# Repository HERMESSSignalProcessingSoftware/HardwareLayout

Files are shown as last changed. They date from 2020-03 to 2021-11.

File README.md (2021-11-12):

# HardwareLayout

## To consider for iteration 3.1
- [X] Rename 5V-28V to 5V-noniso
- [X] STAMP labeling
- [X] Northmarking Top and Bottom
- [X] Far fewer power LEDs
- [X] PTH LEDs via ZE05
- [ ] Label LEDs on PCB
- [X] Strip LED resistor network
- [X] LED Renames: LED_FPGA_LOADED(#13), LED_HB_MEMSYNC(#16), LED_HB_MSS(#14), LED_RECORDING(#15)
- [X] Strip 0 and inf valued devices
- [X] Inverting RXSM Connector
- [X] LM4030 for SGR measurement
- [X] VCCINT auf 1.2V
- [X] Bank0 und Bank6 auf 1.2V und connections an Spannung anpassen
- [X] Optocoupling Pullups
- [X] Main Clk for SF2
- [X] Fix broken Flash package
- [X] Replace FT2232D with FT2232H
- [X] (discarded) FTDI 1MOhm beim Oszi?
- [X] (discarded) FTDI Pins 3 42 und Ende R9 an 5V statt 3V3
- [X] (discarded) FTDI SI/WU auf 3V3

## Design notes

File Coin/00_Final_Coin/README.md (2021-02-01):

## Finaler HERMESS Coin
### Wichtige Informationen:
Bilder (16 bit): HardwareLayout\Coin\GIMP_FINAL\Version 2.1\16Bit
Bilder (GIMP - Projekt):  HardwareLayout\Coin\GIMP_FINAL
GERBER - FILES: HardwareLayout\Coin\00_Final_Coin
CAM - JOB: HardwareLayout\Coin\00_Final_Coin

### Scaling:
0.04 Pixel / mm

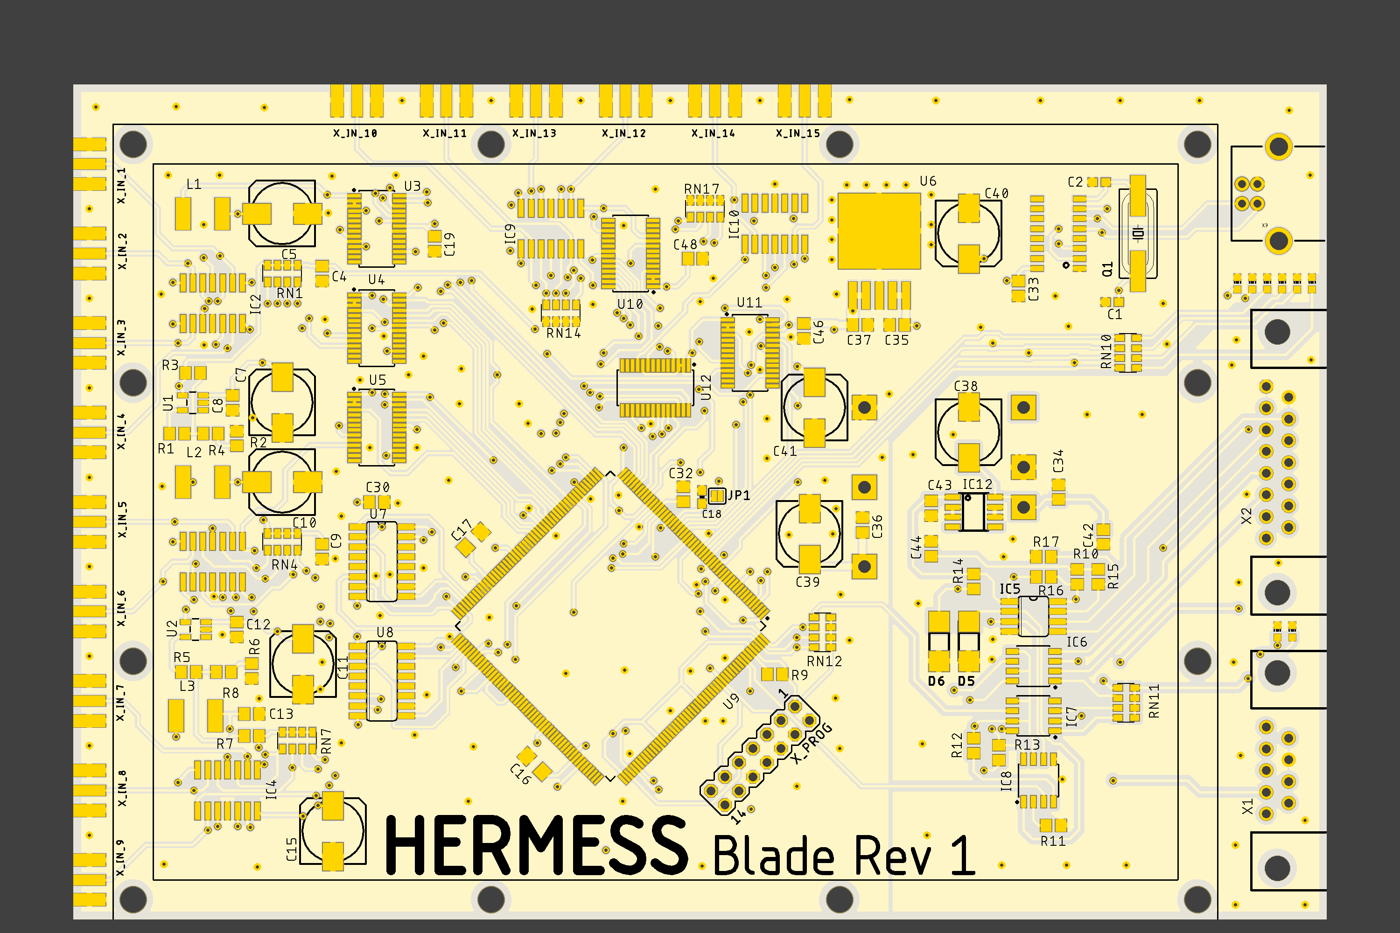
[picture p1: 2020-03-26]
docs/pinout/blade_rev1-sw.png

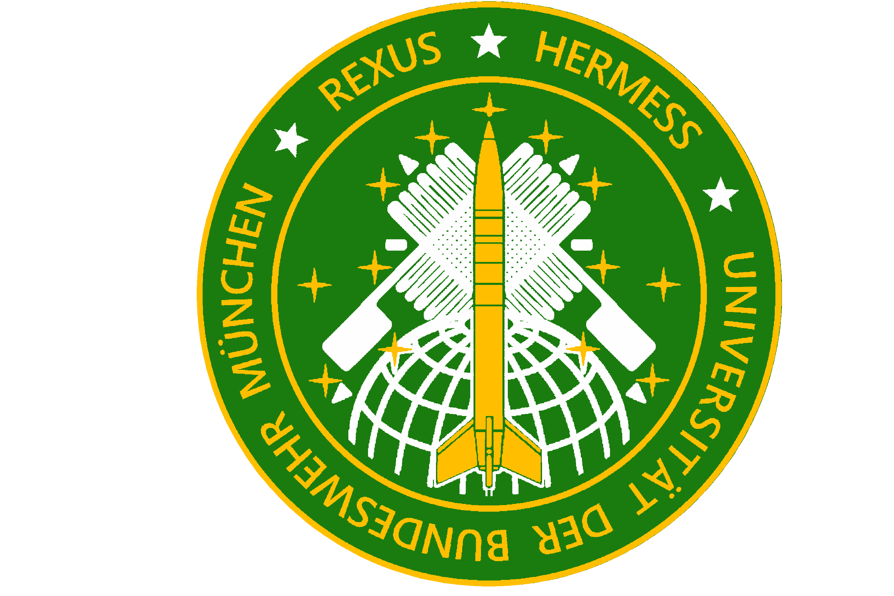
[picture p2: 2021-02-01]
Coin/00_Final_Coin/COIN_TOP_redesign_qr.png

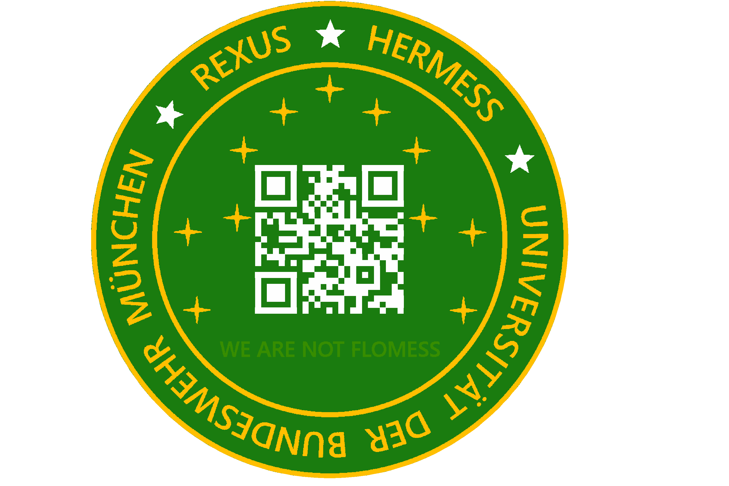
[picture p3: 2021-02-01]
Coin/00_Final_Coin/COIN_Bottom_redesign_qr.png

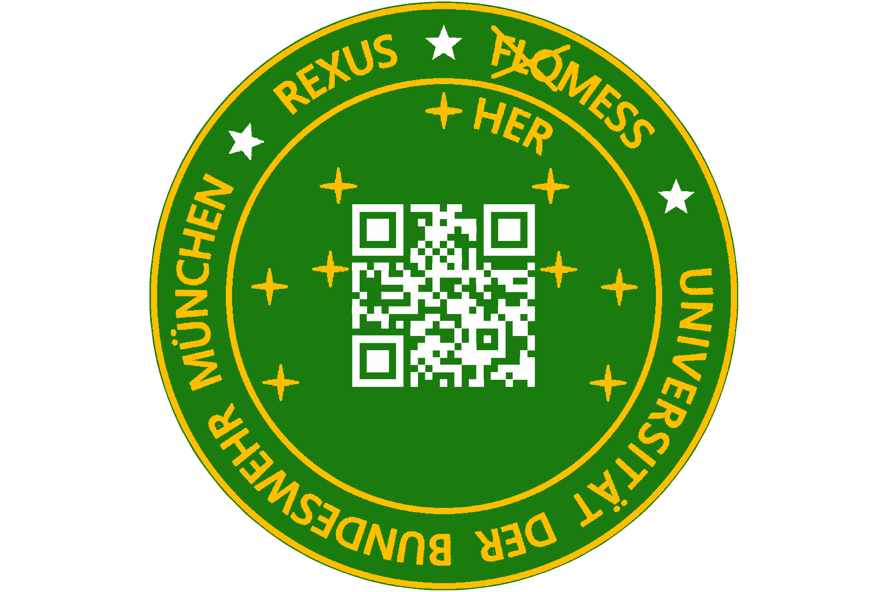
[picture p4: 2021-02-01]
Coin/01_Entwurf_fun_coin/HERMESS_COIN_FUN_BOTTOM.png

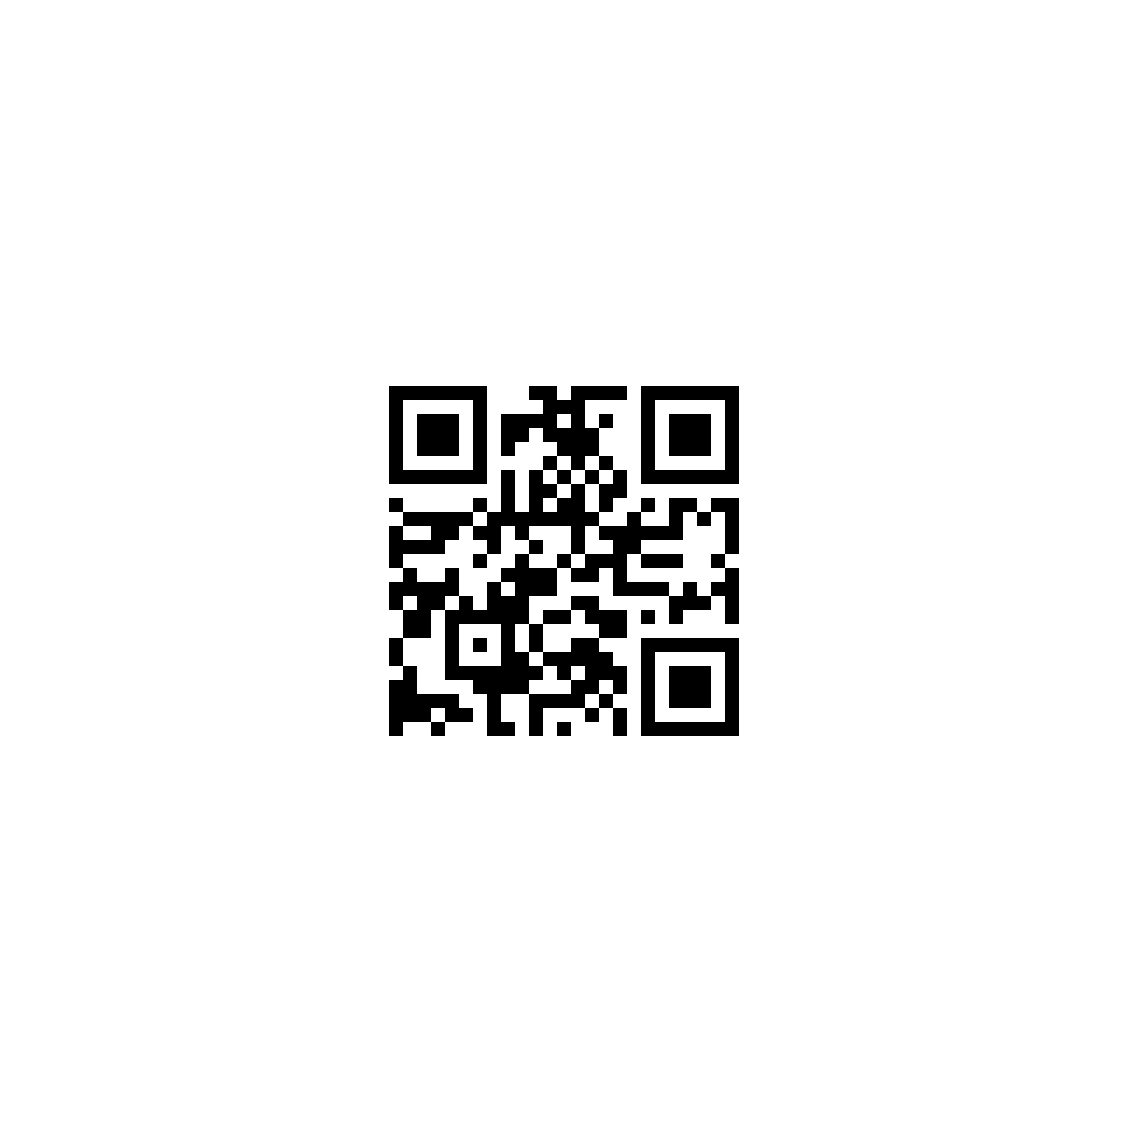
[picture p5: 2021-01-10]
Coin/GIMP_FINAL/HERMESS_BACKSIDE_LAYER_22.bmp

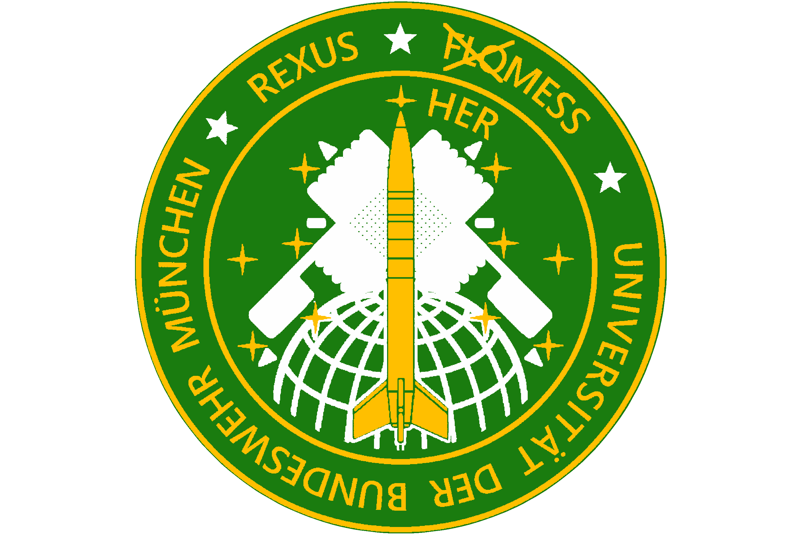
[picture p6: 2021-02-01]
Coin/01_Entwurf_fun_coin/HERMESS_COIN_FUN_TOP.png

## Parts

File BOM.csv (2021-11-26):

 | Neu bestellt | Qty | Value | Device | Package | Parts | Description | C-LOAD | CATEGORY | DATASHEET-URL | DESCRIPTION | HEAT-SINK | MANUFACTURER | MF | MOUNT | MPN | OC_FARNELL | OC_NEWARK | OPERATING_TEMP | OPERTAING_TEMP | PART-NUMBER | PART_STATUS | POPULARITY | ROHS_COMPLIANT | SERIES | SPICEPREFIX | SUB-CATEGORY | THERMALLOSS | TOLERANCE | TYPE | VALUE
x | 1 | 1 | DSC1001CI1-004.0960T | DSC1001CI1-004.0960T | CDFN3225 | U$5 |  |  |  |  |  |  |  |  |  |  |  |  |  |  |  |  |  |  |  | E
x | 1 | 1 | M93C46-WDW6TP | M93C46-WDW6TP | TSSOP-8 | FT_EEPROM | EEPORM M93C46 - WDW6TP
x | 1 | 1 | THN10-2411WIR | THL_20WI_SERIES | THL_20WI_SERIES | U_TRACODCDC | TRACO POWER DC/DC converter THL 20WI Series |  |  |  |  | NO
x | 2 | 1 |  | M15H | M15H | X1 | SUB-D |  |  |  |  |  |  |  |  |  | unknown | unknown |  |  |  |  | 0
x |  | 1 |  | PSS254_G2 | PSS254_G2 | WP
x |  | 1 |  | PSS254_G3 | PSS254_G3 | PROBES
x | 10 | 1 | 10n | C-EUC0805 | C0805 | C2 | CAPACITOR, European symbol |  |  |  |  |  |  |  |  |  |  |  |  |  |  |  | 88 |  |  | C
x | 2 | 1 | 12MHz | CRYSTALHC49UP | HC49UP | Q2 | CRYSTAL |  |  |  |  |  |  |  |  |  | unknown | unknown
x | 10 | 1 | 12k | R-EU_R0805 | R0805 | R9 | RESISTOR, European symbol |  |  |  |  |  |  |  |  |  |  |  |  |  |  |  | 86 |  |  | R
x | 10 | 1 | 150n | C-EUC0805 | C0805 | C27 | CAPACITOR, European symbol |  |  |  |  |  |  |  |  |  |  |  |  |  |  |  | 88 |  |  | C
x | 2 | 1 | 32.768kHz | WE-XTAL_IQXC-90_830107088501 | WE-XTAL_IQXC-90 | Y1 | WE-XTAL Watch Crystals | 6pF |  | https://www.we-online.com/catalog/datasheet/830107088501.pdf |  |  |  |  | SMT |  |  |  |  |  | 8,30E+11 |  |  |  |  |  |  |  | ±20ppm |  | 32.768kHz
x | 3 | 1 | FT2232HL | FT2232HL | LQFP64 | USB | FTDI FT2232HL
x | 2 | 1 | LM4030 | LM4030 | SOT-23 | REF4V096
x | 3 | 1 | TPS785 | TPS785 | TO-252-5 | TPS78512QKVURQ1
x | 3 | 1 | ZE05-4P-2V | ZE05-4P-2V | ZE05H-4P-2V | ZE05H-4P-2V
x | 3 | 6 | IL-AG5-10P-S3T2 | IL-AG5-10P-S3T2 | IL-AG5-10P-S3T2 | CON_STAMP1, CON_STAMP2, CON_STAMP3, CON_STAMP4, CON_STAMP5, CON_STAMP6
x | 4 | 2 |  | L-EUL1812 | L1812 | L1, L2 | INDUCTOR, European symbol |  |  |  |  |  |  |  |  |  |  |  |  |  |  |  | 18 |  |  | L
 | 5 | 18 | ADS1148QPWRQ1 | ADS1148QPWRQ1 | TSSOP28 | STAMP1_ADC_SG1, STAMP1_ADC_SG2, STAMP1_ADC_TEMP, STAMP2_ADC_SG1, STAMP2_ADC_SG2, STAMP2_ADC_TEMP, STAMP3_ADC_SG1, STAMP3_ADC_SG2, STAMP3_ADC_TEMP, STAMP4_ADC_SG1, STAMP4_ADC_SG2, STAMP4_ADC_TEMP, STAMP5_ADC_SG1, STAMP5_ADC_SG2, STAMP5_ADC_TEMP, STAMP6_ADC_SG1, STAMP6_ADC_SG2, STAMP6_ADC_TEMP
x | 6 | 3 | NXB0108PWJ | NXB0108PWJ | TSSOP-20 | U$1, U$2, U$3
x | 10 | 3 | 2 | R-EU_R0805 | R0805 | R2, R3, R4 | RESISTOR, European symbol |  |  |  |  |  |  |  |  |  |  |  |  |  |  |  | 86 |  |  | R
x | 10 | 2 | 22p | C-EUC0805 | C0805 | C74, C75 | CAPACITOR, European symbol |  |  |  |  |  |  |  |  |  |  |  |  |  |  |  | 88 |  |  | C
x | 5 | 1 | 3R65 | R-EU_R0805 | R0805 | R54 | RESISTOR, European symbol |  |  |  |  |  |  |  |  |  |  |  |  |  |  |  | 86 |  |  | R
x | 10 | 1 | 600 | R-EU_R0805 | R0805 | R42 | RESISTOR, European symbol |  |  |  |  |  |  |  |  |  |  |  |  |  |  |  | 86 |  |  | R
x | 20 | 5 | 680 | R-EU_R0805 | R0805 | R18, R19, R20, R49, R52 | RESISTOR, European symbol
x | 10 | 2 | 6pF | C-EUC0805 | C0805 | C30, C32 | CAPACITOR, European symbol |  |  |  |  |  |  |  |  |  |  |  |  |  |  |  | 88 |  |  | C
x | 20 | 5 | BSS123 | BSS123 | SOT23 | Q1, Q3, Q4, Q5, Q6 | N-CHANNEL MOS FET |  |  |  |  |  |  |  |  |  |  |  |  |  |  |  | 21
x | 20 | 1 | 1k | R-EU_R0805 | R0805 | R57 | RESISTOR, European symbol |  |  |  |  |  |  |  |  |  |  |  |  |  |  |  | 86 |  |  | R
x | 24 | 12 | COMMON_MODE_CHOKE | COMMON_MODE_CHOKE | COMMON_MODE_CHOKE | U$6, U$7, U$9, U$10, U$11, U$12, U$13, U$14, U$15, U$16, U$19, U$20 | WE-SL3 SMT COMMON MODE LINE FILT
x | 25 | 24 | 1k 0.1% | R-EU_R0805 | R0805 | R30, R33, R69, R74, R76, R86, R88, R92, R101, R105, R107, R111, R120, R124, R126, R130, R139, R143, R145, R149, R177, R181, R183, R187 | RESISTOR, European symbol |  |  |  |  |  |  |  |  |  |  |  |  |  |  |  | 86 |  |  | R
 |  | 4 |  | SJ | SJ | RCJ1, RCJ2, Y1J1, Y1J2 | SMD solder JUMPER |  |  |  |  |  |  |  |  |  |  |  |  |  |  |  | 33
 |  | 1 |  | USBMINIB | USB-MINIB | USB_CONN | USB Connectors
 |  | 103 | 100n | C-EUC0805 | C0805 | C1, C7, C8, C9, C10, C11, C12, C13, C14, C15, C16, C17, C18, C19, C20, C21, C22, C23, C25, C28, C29, C31, C33, C35, C36, C37, C43, C45, C46, C47, C48, C49, C51, C52, C53, C54, C55, C56, C71, C73, C76, C77, C78, C92, C94, C95, C96, C97, C98, C100, C101, C102, C103, C104, C105, C113, C115, C116, C117, C118, C119, C121, C122, C123, C124, C125, C126, C134, C136, C137, C138, C139, C140, C142, C143, C144, C145, C146, C147, C155, C157, C158, C159, C160, C161, C163, C164, C165, C166, C167, C168, C197, C199, C200, C201, C202, C203, C205, C206, C207, C208, C209, C210 | CAPACITOR, European symbol |  |  |  |  |  |  |  |  |  |  |  |  |  |  |  | 88 |  |  | C
 |  | 1 | 100n | C-EUC1206 | C1206 | C42 | CAPACITOR, European symbol |  |  |  |  |  |  |  |  |  |  |  |  |  |  |  | 54 |  |  | C
 |  | 3 | 10k | R-EU_R0805 | R0805 | R1, R26, R27 | RESISTOR, European symbol |  |  |  |  |  |  |  |  |  |  |  |  |  |  |  | 86 |  |  | R
 |  | 11 | 10u | CPOL-EUE/7260-38W | E/7260-38W | C38, C39, C40, C41, C60, C61, C62, C64, C65, C66, C67 | POLARIZED CAPACITOR, European symbol |  |  |  |  |  |  |  |  |  |  |  |  |  |  |  | 0 |  |  | C
 |  | 5 | 1V9 | LEDCHIP-LED0805 | CHIP-LED0805 | FL, MS, MSS, PWR, RC | LED
 |  | 6 | 1k | R-EU_R0805 | R0805 | R21, R22, R34, R43, R44, R53 | RESISTOR, European symbol
 |  | 18 | 1u | C-EUC0805 | C0805 | C34, C50, C63, C93, C99, C109, C114, C120, C130, C135, C141, C151, C156, C162, C172, C198, C204, C214 | CAPACITOR, European symbol |  |  |  |  |  |  |  |  |  |  |  |  |  |  |  | 88 |  |  | C
 |  | 1 | 2k2 | R-EU_R0805 | R0805 | R24 | RESISTOR, European symbol |  |  |  |  |  |  |  |  |  |  |  |  |  |  |  | 86 |  |  | R
 |  | 2 | 330 | R-EU_R0805 | R0805 | R47, R48 | RESISTOR, European symbol
 |  | 6 | 33n | C-EUC0805 | C0805 | C68, C110, C131, C152, C173, C215 | CAPACITOR, European symbol |  |  |  |  |  |  |  |  |  |  |  |  |  |  |  | 88 |  |  | C
 |  | 4 | 3k | R-EU_R0805 | R0805 | R11, R12, R13, R23 | RESISTOR, European symbol
 |  | 2 | 3k3 | R-EU_R0805 | R0805 | R16, R17 | RESISTOR, European symbol
 |  | 12 | 3n3 | C-EUC0805 | C0805 | C69, C70, C111, C112, C132, C133, C153, C154, C174, C175, C216, C217 | CAPACITOR, European symbol |  |  |  |  |  |  |  |  |  |  |  |  |  |  |  | 88 |  |  | C
 |  | 24 | 40 1% | R-EU_R0805 | R0805 | R29, R32, R72, R73, R84, R85, R90, R91, R103, R104, R109, R110, R122, R123, R128, R129, R141, R142, R147, R148, R179, R180, R185, R186 | RESISTOR, European symbol |  |  |  |  |  |  |  |  |  |  |  |  |  |  |  | 86 |  |  | R
 |  | 31 | 47 | R-EU_R0805 | R0805 | R14, R31, R35, R36, R40, R41, R45, R46, R50, R51, R55, R56, R60, R61, R70, R75, R83, R89, R93, R102, R108, R112, R121, R127, R131, R140, R146, R150, R178, R184, R188 | RESISTOR, European symbol |  |  |  |  |  |  |  |  |  |  |  |  |  |  |  | 86 |  |  | R
 |  | 2 | 470n | C-EUC0805 | C0805 | C4, C6 | CAPACITOR, European symbol |  |  |  |  |  |  |  |  |  |  |  |  |  |  |  | 88 |  |  | C
 |  | 18 | 4k7 | R-EU_R0805 | R0805 | R28, R68, R71, R77, R87, R94, R100, R106, R113, R119, R125, R132, R138, R144, R151, R176, R182, R189 | RESISTOR, European symbol |  |  |  |  |  |  |  |  |  |  |  |  |  |  |  | 86 |  |  | R
 |  | 12 | 4k7 1% | R-EU_R0805 | R0805 | R78, R79, R95, R96, R114, R115, R133, R134, R152, R153, R190, R191 | RESISTOR, European symbol |  |  |  |  |  |  |  |  |  |  |  |  |  |  |  | 86 |  |  | R
 |  | 5 | 4u7 | C-EUC0805 | C0805 | C3, C5, C24, C26, C79 | CAPACITOR, European symbol |  |  |  |  |  |  |  |  |  |  |  |  |  |  |  | 88 |  |  | C
 |  | 2 | 500 | R-EU_R0805 | R0805 | R10, R15 | RESISTOR, European symbol
 |  | 2 | 5V6 | DZMELF | DMELF | D1, D5 | Zener diode
 |  | 6 | 68n | C-EUC0805 | C0805 | C58, C107, C128, C149, C170, C212 | CAPACITOR, European symbol |  |  |  |  |  |  |  |  |  |  |  |  |  |  |  | 88 |  |  | C
 |  | 12 | 6n8 | C-EUC0805 | C0805 | C57, C59, C106, C108, C127, C129, C148, C150, C169, C171, C211, C213 | CAPACITOR, European symbol |  |  |  |  |  |  |  |  |  |  |  |  |  |  |  | 88 |  |  | C
 |  | 1 | 7k5 | R-EU_R0805 | R0805 | R25 | RESISTOR, European symbol |  |  |  |  |  |  |  |  |  |  |  |  |  |  |  | 86 |  |  | R
 |  | 6 | 820 0.1% | R-EU_R0805 | R0805 | R82, R99, R118, R137, R156, R194 | RESISTOR, European symbol |  |  |  |  |  |  |  |  |  |  |  |  |  |  |  | 86 |  |  | R
 |  | 12 | 9k09 1% | R-EU_R0805 | R0805 | R80, R81, R97, R98, R116, R117, R135, R136, R154, R155, R192, R193 | RESISTOR, European symbol |  |  |  |  |  |  |  |  |  |  |  |  |  |  |  | 86 |  |  | R
 |  | 1 | LM78L05ACMX/NOPB | LM78L05ACMX/NOPB | SOIC8 | U_7805
 |  | 1 | LT1528 | LT1528 | Q5-DD | U_LT1528 | LT1528
 |  | 1 | MAX488CSA | MAX488CSA | SO08 | U_MAX488 | RS485 TRANSEIVER |  |  |  |  |  |  | MAXIM |  | MAX488CSA | 3534170 | 34C3921 |  |  |  |  | 1
 |  | 3 | MOCD207M | MOCD207M_SOIC8 | SOIC127P594X363-8N | U_OPTO_3, U_OPTO_4, U_OPTO_5 | 8- pin SOIC Dual-Channel Phototransistor Output Optocoupler |  | Opto-Electronic |  |  |  | ON Semiconductor |  |  | MOCD207M |  |  |  | -40 to +100 °C |  | Active |  | RoHS3 Compliant |  |  | OptoCoupler | 0.24W |  |  | MOCD207M
 |  | 1 | S70FL01GSAGM | S70FL01GSAGM | SOIC16 | S70FL | Memory S70FL01G
 |  | 1 | SF2_M2S010TQ144 | SF2_M2S010TQ144 | TQFP144 | SF2_M2S010TQ1 | Smart Fusion SoC
 |  | 1 | ~0 | C-EUC0805 | C0805 | C44 | CAPACITOR, European symbol |  |  |  |  |  |  |  |  |  |  |  |  |  |  |  | 88 |  |  | C

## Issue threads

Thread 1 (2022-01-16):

MOSI signal of STAMP 6 spikes

robybyte, 2022-01-16:
While measuring RX TX signals of telemetry a strage signal appered on MOSI of STAMP 6 (pin number 2 at the SmartFusion IC).
Signal looked like a falling exponential function (as you discharge a capacitor) creating some spikes (Vpp was in the given limit of the SM2).

TODO: Measurments at pin 2 all the way to the corresponding STAMP.

Issue

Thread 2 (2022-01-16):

R54 overheating

robybyte, 2022-01-16:
While testing one resistor (R54) destroyed itself due to overheating.

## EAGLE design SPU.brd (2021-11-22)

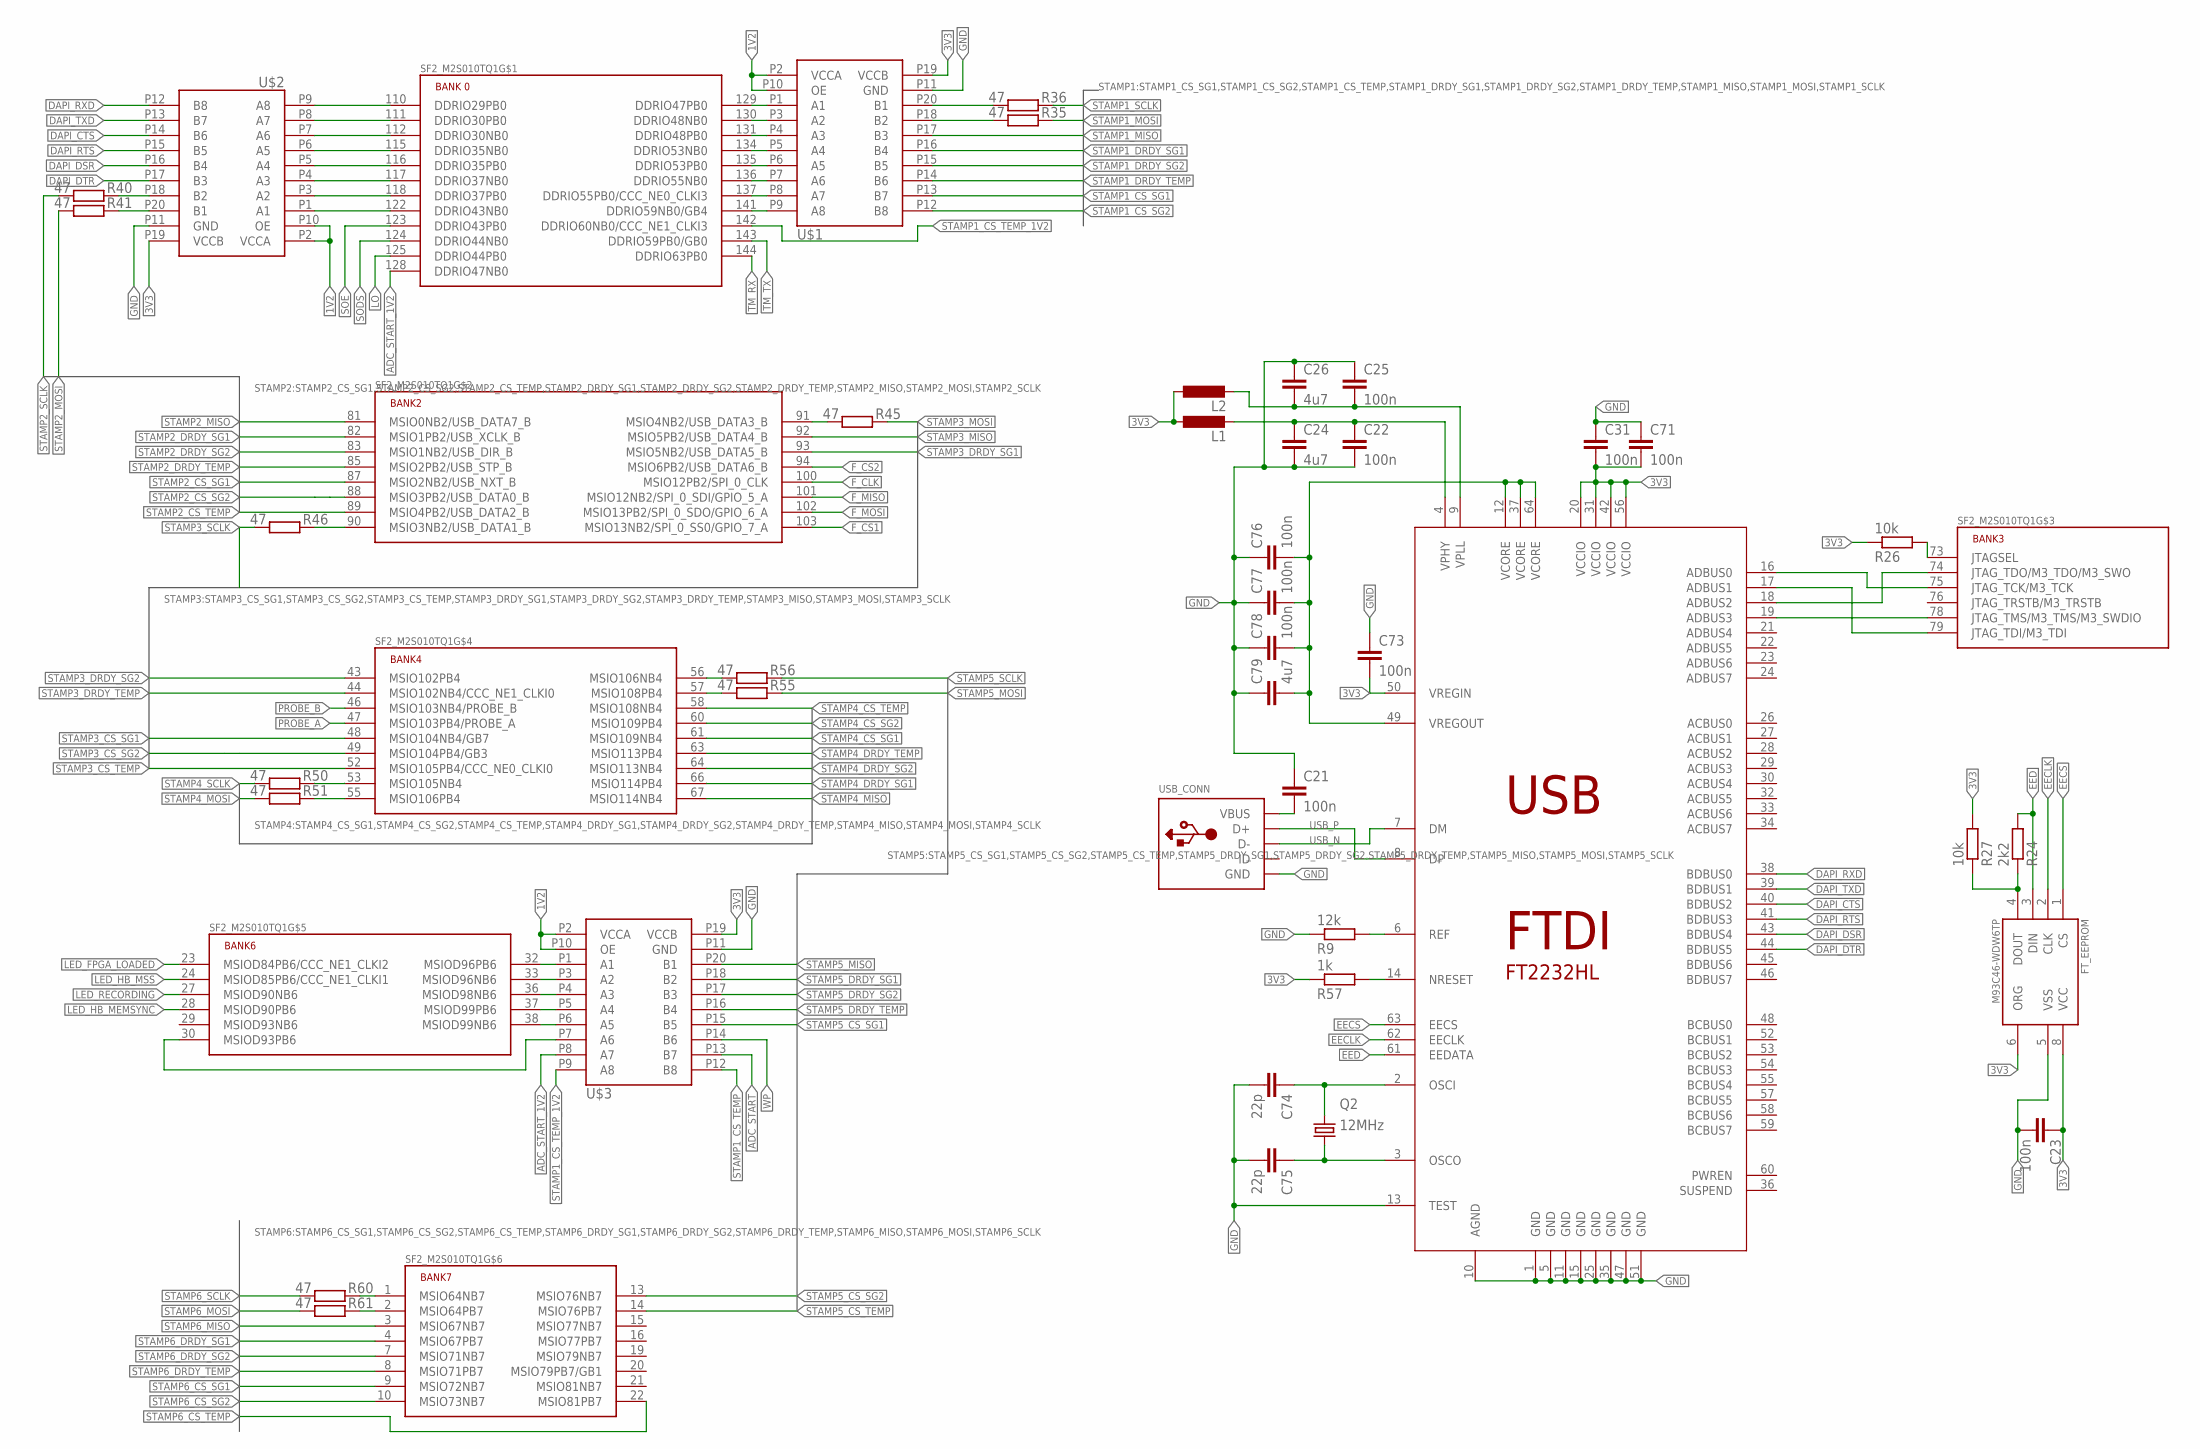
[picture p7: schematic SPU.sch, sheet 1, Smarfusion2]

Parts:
C21, C22, C23, C25, C31, C71, C73, C76, C77, C78: 100n; C0805
C24, C26, C79: 4u7; C0805
C74, C75: 22p; C0805
FT_EEPROM: M93C46-WDW6TP; TSSOP-8
L1, L2: L-EUL1812; L1812
Q2: 12MHz; HC49UP
R9: 12k; R0805
R24: 2k2; R0805
R26, R27: 10k; R0805
R35, R36, R40, R41, R45, R46, R50, R51, R55, R56, R60, R61: 47; R0805
R57: 1k; R0805
SF2_M2S010TQ1: SF2_M2S010TQ144; TQFP144
U$1, U$2, U$3: NXB0108PWJ; TSSOP-20
USB: FT2232HL; LQFP64
USB_CONN: USBMINIB; USB-MINIB

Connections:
1V2: U$1.P2 (VCCA), U$1.P10 (OE), U$2.P2 (VCCA), U$2.P10 (OE), U$3.P2 (VCCA), U$3.P10 (OE); also elsewhere on the board
3V3: C23.1, C31.2, C71.2, C73.2, FT_EEPROM.6 (ORG), FT_EEPROM.8 (VCC), L1.1, L2.1, R26.1, R27.2, R57.1, U$1.P19 (VCCB), U$2.P19 (VCCB), U$3.P19 (VCCB), USB.20 (VCCIO), USB.31 (VCCIO), USB.42 (VCCIO), USB.50 (VREGIN), USB.56 (VCCIO); also elsewhere on the board
ADC_START: U$3.P13 (B7); also elsewhere on the board
ADC_START_1V2: SF2_M2S010TQ1.128 (DDRIO47NB0), U$3.P8 (A7)
DAPI_CTS: U$2.P14 (B6), USB.40 (BDBUS2)
DAPI_DSR: U$2.P16 (B4), USB.43 (BDBUS4)
DAPI_DTR: U$2.P17 (B3), USB.44 (BDBUS5)
DAPI_RTS: U$2.P15 (B5), USB.41 (BDBUS3)
DAPI_RXD: U$2.P12 (B8), USB.38 (BDBUS0)
DAPI_TXD: U$2.P13 (B7), USB.39 (BDBUS1)
EECLK: FT_EEPROM.2 (CLK), USB.62 (EECLK)
EECS: FT_EEPROM.1 (CS), USB.63 (EECS)
EED: FT_EEPROM.3 (DIN), R24.2, USB.61 (EEDATA)
F_CLK: SF2_M2S010TQ1.100 (MSIO12PB2/SPI_0_CLK); also elsewhere on the board
F_CS1: SF2_M2S010TQ1.103 (MSIO13NB2/SPI_0_SS0/GPIO_7_A); also elsewhere on the board
F_CS2: SF2_M2S010TQ1.94 (MSIO6PB2/USB_DATA6_B); also elsewhere on the board
F_MISO: SF2_M2S010TQ1.101 (MSIO12NB2/SPI_0_SDI/GPIO_5_A); also elsewhere on the board
F_MOSI: SF2_M2S010TQ1.102 (MSIO13PB2/SPI_0_SDO/GPIO_6_A); also elsewhere on the board
GND: C21.1, C22.2, C23.2, C24.2, C25.1, C26.1, C31.1, C71.1, C73.1, C74.2, C75.2, C76.1, C77.1, C78.1, C79.1, FT_EEPROM.5 (VSS), R9.1, U$1.P11 (GND), U$2.P11 (GND), U$3.P11 (GND), USB.1 (GND), USB.5 (GND), USB.10 (AGND), USB.11 (GND), USB.13 (TEST), USB.15 (GND), USB.25 (GND), USB.35 (GND), USB.47 (GND), USB.51 (GND), USB_CONN.GND; also elsewhere on the board
LED_FPGA_LOADED: SF2_M2S010TQ1.23 (MSIOD84PB6/CCC_NE1_CLKI2); also elsewhere on the board
LED_HB_MEMSYNC: SF2_M2S010TQ1.28 (MSIOD90PB6); also elsewhere on the board
LED_HB_MSS: SF2_M2S010TQ1.24 (MSIOD85PB6/CCC_NE1_CLKI1); also elsewhere on the board
LED_RECORDING: SF2_M2S010TQ1.27 (MSIOD90NB6); also elsewhere on the board
LO: SF2_M2S010TQ1.125 (DDRIO44PB0); also elsewhere on the board
unnamed: R26.2, SF2_M2S010TQ1.73 (JTAGSEL)
unnamed: C74.1, Q2.2, USB.2 (OSCI)
unnamed: SF2_M2S010TQ1.32 (MSIOD96PB6), U$3.P1 (A1)
unnamed: SF2_M2S010TQ1.33 (MSIOD96NB6), U$3.P3 (A2)
unnamed: SF2_M2S010TQ1.36 (MSIOD98NB6), U$3.P4 (A3)
unnamed: C21.2, USB_CONN.VBUS
unnamed: C22.1, C24.1, L1.2, USB.4 (VPHY)
unnamed: R36.2, U$1.P20 (B1)
unnamed: SF2_M2S010TQ1.75 (JTAG_TCK/M3_TCK), USB.16 (ADBUS0)
unnamed: SF2_M2S010TQ1.79 (JTAG_TDI/M3_TDI), USB.17 (ADBUS1)
unnamed: SF2_M2S010TQ1.74 (JTAG_TDO/M3_TDO/M3_SWO), USB.18 (ADBUS2)
unnamed: SF2_M2S010TQ1.78 (JTAG_TMS/M3_TMS/M3_SWDIO), USB.19 (ADBUS3)
unnamed: SF2_M2S010TQ1.37 (MSIOD99PB6), U$3.P5 (A4)
unnamed: FT_EEPROM.4 (DOUT), R24.1, R27.1
unnamed: R35.2, U$1.P18 (B2)
unnamed: SF2_M2S010TQ1.118 (DDRIO37PB0), U$2.P3 (A2)
unnamed: SF2_M2S010TQ1.122 (DDRIO43NB0), U$2.P1 (A1)
unnamed: R40.1, U$2.P18 (B2)
unnamed: SF2_M2S010TQ1.129 (DDRIO47PB0), U$1.P1 (A1)
unnamed: R41.1, U$2.P20 (B1)
unnamed: R46.1, SF2_M2S010TQ1.90 (MSIO3NB2/USB_DATA1_B)
unnamed: R45.2, SF2_M2S010TQ1.91 (MSIO4NB2/USB_DATA3_B)
unnamed: SF2_M2S010TQ1.130 (DDRIO48NB0), U$1.P3 (A2)
unnamed: SF2_M2S010TQ1.131 (DDRIO48PB0), U$1.P4 (A3)
unnamed: SF2_M2S010TQ1.134 (DDRIO53NB0), U$1.P5 (A4)
unnamed: SF2_M2S010TQ1.135 (DDRIO53PB0), U$1.P6 (A5)
unnamed: SF2_M2S010TQ1.136 (DDRIO55NB0), U$1.P7 (A6)
unnamed: SF2_M2S010TQ1.137 (DDRIO55PB0/CCC_NE0_CLKI3), U$1.P8 (A7)
unnamed: SF2_M2S010TQ1.141 (DDRIO59NB0/GB4), U$1.P9 (A8)
unnamed: SF2_M2S010TQ1.38 (MSIOD99NB6), U$3.P6 (A5)
unnamed: SF2_M2S010TQ1.110 (DDRIO29PB0), U$2.P9 (A8)
unnamed: SF2_M2S010TQ1.111 (DDRIO30PB0), U$2.P8 (A7)
unnamed: SF2_M2S010TQ1.112 (DDRIO30NB0), U$2.P7 (A6)
unnamed: SF2_M2S010TQ1.115 (DDRIO35NB0), U$2.P6 (A5)
unnamed: R50.1, SF2_M2S010TQ1.53 (MSIO105NB4)
unnamed: R51.1, SF2_M2S010TQ1.55 (MSIO106PB4)
unnamed: SF2_M2S010TQ1.116 (DDRIO35PB0), U$2.P5 (A4)
unnamed: SF2_M2S010TQ1.117 (DDRIO37NB0), U$2.P4 (A3)
unnamed: SF2_M2S010TQ1.30 (MSIOD93PB6), U$3.P7 (A6)
unnamed: R55.2, SF2_M2S010TQ1.57 (MSIO108PB4)
unnamed: R56.2, SF2_M2S010TQ1.56 (MSIO106NB4)
unnamed: R60.1, SF2_M2S010TQ1.1 (MSIO64NB7)
unnamed: R61.1, SF2_M2S010TQ1.2 (MSIO64PB7)
unnamed: R57.2, USB.14 (NRESET)
unnamed: R9.2, USB.6 (REF)
unnamed: C75.1, Q2.1, USB.3 (OSCO)
unnamed: C76.2, C77.2, C78.2, C79.2, USB.12 (VCORE), USB.37 (VCORE), USB.49 (VREGOUT), USB.64 (VCORE)
unnamed: C25.2, C26.2, L2.2, USB.9 (VPLL)
PROBE_A: SF2_M2S010TQ1.47 (MSIO103PB4/PROBE_A); also elsewhere on the board
PROBE_B: SF2_M2S010TQ1.46 (MSIO103NB4/PROBE_B); also elsewhere on the board
SODS: SF2_M2S010TQ1.124 (DDRIO44NB0); also elsewhere on the board
SOE: SF2_M2S010TQ1.123 (DDRIO43PB0); also elsewhere on the board
STAMP1_CS_SG1: U$1.P13 (B7); also elsewhere on the board
STAMP1_CS_SG2: U$1.P12 (B8); also elsewhere on the board
STAMP1_CS_TEMP: U$3.P12 (B8); also elsewhere on the board
STAMP1_CS_TEMP_1V2: SF2_M2S010TQ1.142 (DDRIO60NB0/CCC_NE1_CLKI3), U$3.P9 (A8)
STAMP1_DRDY_SG1: U$1.P16 (B4); also elsewhere on the board
STAMP1_DRDY_SG2: U$1.P15 (B5); also elsewhere on the board
STAMP1_DRDY_TEMP: U$1.P14 (B6); also elsewhere on the board
STAMP1_MISO: U$1.P17 (B3); also elsewhere on the board
STAMP1_MOSI: R35.1; also elsewhere on the board
STAMP1_SCLK: R36.1; also elsewhere on the board
STAMP2_CS_SG1: SF2_M2S010TQ1.87 (MSIO2NB2/USB_NXT_B); also elsewhere on the board
STAMP2_CS_SG2: SF2_M2S010TQ1.88 (MSIO3PB2/USB_DATA0_B); also elsewhere on the board
STAMP2_CS_TEMP: SF2_M2S010TQ1.89 (MSIO4PB2/USB_DATA2_B); also elsewhere on the board
STAMP2_DRDY_SG1: SF2_M2S010TQ1.82 (MSIO1PB2/USB_XCLK_B); also elsewhere on the board
STAMP2_DRDY_SG2: SF2_M2S010TQ1.83 (MSIO1NB2/USB_DIR_B); also elsewhere on the board
STAMP2_DRDY_TEMP: SF2_M2S010TQ1.85 (MSIO2PB2/USB_STP_B); also elsewhere on the board
STAMP2_MISO: SF2_M2S010TQ1.81 (MSIO0NB2/USB_DATA7_B); also elsewhere on the board
STAMP2_MOSI: R41.2; also elsewhere on the board
STAMP2_SCLK: R40.2; also elsewhere on the board
STAMP3_CS_SG1: SF2_M2S010TQ1.48 (MSIO104NB4/GB7); also elsewhere on the board
STAMP3_CS_SG2: SF2_M2S010TQ1.49 (MSIO104PB4/GB3); also elsewhere on the board
STAMP3_CS_TEMP: SF2_M2S010TQ1.52 (MSIO105PB4/CCC_NE0_CLKI0); also elsewhere on the board
STAMP3_DRDY_SG1: SF2_M2S010TQ1.93 (MSIO5NB2/USB_DATA5_B); also elsewhere on the board
STAMP3_DRDY_SG2: SF2_M2S010TQ1.43 (MSIO102PB4); also elsewhere on the board
STAMP3_DRDY_TEMP: SF2_M2S010TQ1.44 (MSIO102NB4/CCC_NE1_CLKI0); also elsewhere on the board
STAMP3_MISO: SF2_M2S010TQ1.92 (MSIO5PB2/USB_DATA4_B); also elsewhere on the board
STAMP3_MOSI: R45.1; also elsewhere on the board
STAMP3_SCLK: R46.2; also elsewhere on the board
STAMP4_CS_SG1: SF2_M2S010TQ1.61 (MSIO109NB4); also elsewhere on the board
STAMP4_CS_SG2: SF2_M2S010TQ1.60 (MSIO109PB4); also elsewhere on the board
STAMP4_CS_TEMP: SF2_M2S010TQ1.58 (MSIO108NB4); also elsewhere on the board
STAMP4_DRDY_SG1: SF2_M2S010TQ1.66 (MSIO114PB4); also elsewhere on the board
STAMP4_DRDY_SG2: SF2_M2S010TQ1.64 (MSIO113NB4); also elsewhere on the board
STAMP4_DRDY_TEMP: SF2_M2S010TQ1.63 (MSIO113PB4); also elsewhere on the board
STAMP4_MISO: SF2_M2S010TQ1.67 (MSIO114NB4); also elsewhere on the board
STAMP4_MOSI: R51.2; also elsewhere on the board
STAMP4_SCLK: R50.2; also elsewhere on the board
STAMP5_CS_SG1: U$3.P15 (B5); also elsewhere on the board
STAMP5_CS_SG2: SF2_M2S010TQ1.13 (MSIO76NB7); also elsewhere on the board
STAMP5_CS_TEMP: SF2_M2S010TQ1.14 (MSIO76PB7); also elsewhere on the board
STAMP5_DRDY_SG1: U$3.P18 (B2); also elsewhere on the board
STAMP5_DRDY_SG2: U$3.P17 (B3); also elsewhere on the board
STAMP5_DRDY_TEMP: U$3.P16 (B4); also elsewhere on the board
STAMP5_MISO: U$3.P20 (B1); also elsewhere on the board
STAMP5_MOSI: R55.1; also elsewhere on the board
STAMP5_SCLK: R56.1; also elsewhere on the board
STAMP6_CS_SG1: SF2_M2S010TQ1.9 (MSIO72NB7); also elsewhere on the board
STAMP6_CS_SG2: SF2_M2S010TQ1.10 (MSIO73NB7); also elsewhere on the board
STAMP6_CS_TEMP: SF2_M2S010TQ1.22 (MSIO81PB7); also elsewhere on the board
STAMP6_DRDY_SG1: SF2_M2S010TQ1.4 (MSIO67PB7); also elsewhere on the board
STAMP6_DRDY_SG2: SF2_M2S010TQ1.7 (MSIO71NB7); also elsewhere on the board
STAMP6_DRDY_TEMP: SF2_M2S010TQ1.8 (MSIO71PB7); also elsewhere on the board
STAMP6_MISO: SF2_M2S010TQ1.3 (MSIO67NB7); also elsewhere on the board
STAMP6_MOSI: R61.2; also elsewhere on the board
STAMP6_SCLK: R60.2; also elsewhere on the board
TM_RX: SF2_M2S010TQ1.144 (DDRIO63PB0); also elsewhere on the board
TM_TX: SF2_M2S010TQ1.143 (DDRIO59PB0/GB0); also elsewhere on the board
USB_N: USB.7 (DM), USB_CONN.D-
USB_P: USB.8 (DP), USB_CONN.D+
WP: U$3.P14 (B6); also elsewhere on the board

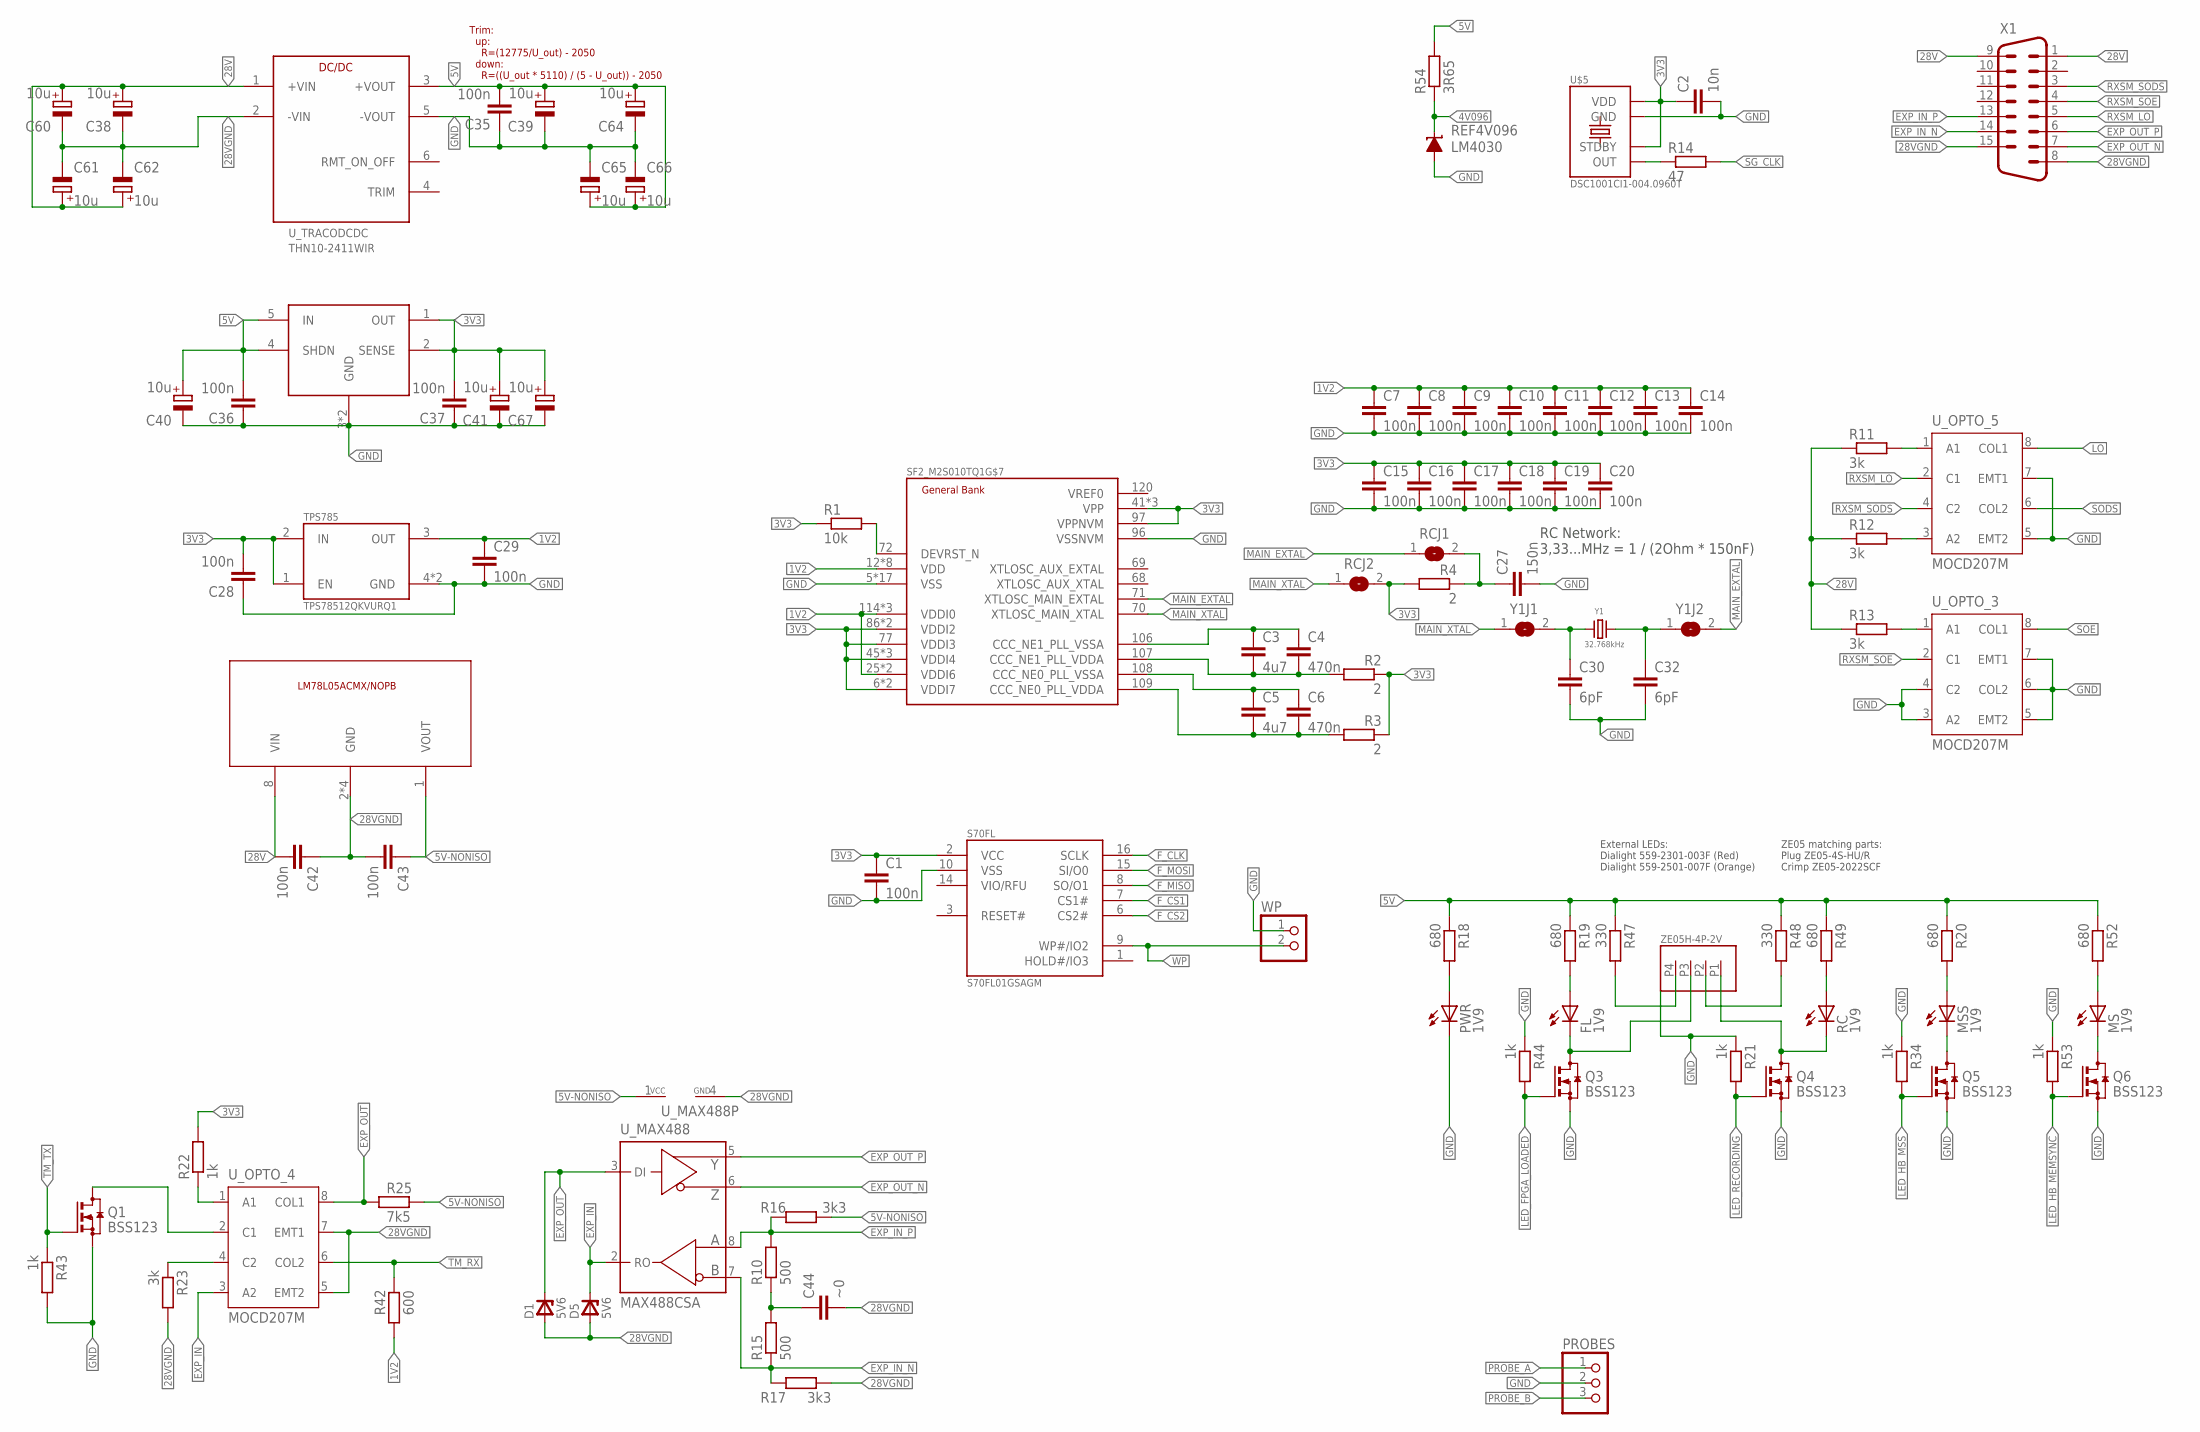
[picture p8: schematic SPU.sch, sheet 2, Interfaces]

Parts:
C1, C7, C8, C9, C10, C11, C12, C13, C14, C15, C16, C17, C18, C19, C20, C28, C29, C35, C36, C37, C43: 100n; C0805
C2: 10n; C0805
C3, C5: 4u7; C0805
C4, C6: 470n; C0805
C27: 150n; C0805
C30, C32: 6pF; C0805
C38, C39, C40, C41, C60, C61, C62, C64, C65, C66, C67: 10u; E/7260-38W
C42: 100n; C1206
C44: ~0; C0805
D1, D5: 5V6; DMELF
FL: 1V9; CHIP-LED0805
MS: 1V9; CHIP-LED0805
MSS: 1V9; CHIP-LED0805
PROBES: PSS254_G3
PWR: 1V9; CHIP-LED0805
Q1, Q3, Q4, Q5, Q6: BSS123; SOT23
R1: 10k; R0805
R2, R3, R4: 2; R0805
R10, R15: 500; R0805
R11, R12, R13, R23: 3k; R0805
R14: 47; R0805
R16, R17: 3k3; R0805
R18, R19, R20, R49, R52: 680; R0805
R21, R22, R34, R43, R44, R53: 1k; R0805
R25: 7k5; R0805
R42: 600; R0805
R47, R48: 330; R0805
R54: 3R65; R0805
RC: 1V9; CHIP-LED0805
RCJ1, RCJ2: SJ
REF4V096: LM4030; SOT-23
S70FL: S70FL01GSAGM; SOIC16
SF2_M2S010TQ1: SF2_M2S010TQ144; TQFP144
TPS78512QKVURQ1: TPS785; TO-252-5
U$5: DSC1001CI1-004.0960T; CDFN3225
U_7805: LM78L05ACMX/NOPB; SOIC8
U_LT1528: LT1528; Q5-DD
U_MAX488: MAX488CSA; SO08
U_OPTO_3, U_OPTO_4, U_OPTO_5: MOCD207M; SOIC127P594X363-8N
U_TRACODCDC: THN10-2411WIR; THL_20WI_SERIES
WP: PSS254_G2
X1: M15H
Y1: 32.768kHz; WE-XTAL_IQXC-90
Y1J1, Y1J2: SJ
ZE05H-4P-2V: ZE05-4P-2V; ZE05H-4P-2V

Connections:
1V2: C7.1, C8.1, C9.1, C10.1, C11.1, C12.1, C13.1, C14.1, C29.1, R42.1, SF2_M2S010TQ1.12 (VDD), SF2_M2S010TQ1.25 (VDDI6), SF2_M2S010TQ1.31 (VDD), SF2_M2S010TQ1.35 (VDDI6), SF2_M2S010TQ1.39 (VDD), SF2_M2S010TQ1.50 (VDD), SF2_M2S010TQ1.95 (VDD), SF2_M2S010TQ1.105 (VDD), SF2_M2S010TQ1.114 (VDDI0), SF2_M2S010TQ1.121 (VDD), SF2_M2S010TQ1.127 (VDDI0), SF2_M2S010TQ1.133 (VDD), SF2_M2S010TQ1.138 (VDDI0), TPS78512QKVURQ1.3 (OUT); also elsewhere on the board
3V3: C1.1, C2.1, C15.1, C16.1, C17.1, C18.1, C19.1, C20.1, C28.2, C37.2, C41.+, C67.+, R1.1, R2.1, R3.1, R4.2, R22.2, RCJ2.2, S70FL.2 (VCC), SF2_M2S010TQ1.6 (VDDI7), SF2_M2S010TQ1.17 (VDDI7), SF2_M2S010TQ1.41 (VPP), SF2_M2S010TQ1.45 (VDDI4), SF2_M2S010TQ1.54 (VDDI4), SF2_M2S010TQ1.62 (VDDI4), SF2_M2S010TQ1.77 (VDDI3), SF2_M2S010TQ1.80 (VPP), SF2_M2S010TQ1.86 (VDDI2), SF2_M2S010TQ1.97 (VPPNVM), SF2_M2S010TQ1.99 (VDDI2), SF2_M2S010TQ1.104 (VPP), TPS78512QKVURQ1.1 (EN), TPS78512QKVURQ1.2 (IN), U$5.P1 (STDBY), U$5.P4 (VDD), U_LT1528.1 (OUT), U_LT1528.2 (SENSE); also elsewhere on the board
4V096: R54.1, REF4V096.P4 (C); also elsewhere on the board
5V: C35.2, C36.2, C39.+, C40.+, C64.+, C65.+, C66.+, R18.1, R19.1, R20.1, R47.1, R48.1, R49.1, R52.1, R54.2, U_LT1528.4 (SHDN), U_LT1528.5 (IN), U_TRACODCDC.3 (+VOUT)
5V-NONISO: C43.1, R16.1, R25.2, U_7805.1 (VOUT), U_MAX488.1 (VCC)
28V: C38.+, C42.2, C60.+, C61.+, C62.+, R11.1, R12.1, R13.1, U_7805.8 (VIN), U_TRACODCDC.1 (+VIN), X1.1, X1.9
28VGND: C38.-, C42.1, C43.2, C44.2, C60.-, C61.-, C62.-, D1.A, D5.A, R17.1, R23.2, U_7805.2 (GND), U_7805.3 (GND), U_7805.6 (GND), U_7805.7 (GND), U_MAX488.4 (GND), U_OPTO_4.5 (EMT2), U_OPTO_4.7 (EMT1), U_TRACODCDC.2 (-VIN), X1.8, X1.15
EXP_IN: D5.C, U_MAX488.2 (RO), U_OPTO_4.3 (A2)
EXP_IN_N: R15.1, R17.2, U_MAX488.7 (B), X1.14
EXP_IN_P: R10.2, R16.2, U_MAX488.8 (A), X1.13
EXP_OUT: D1.C, R25.1, U_MAX488.3 (DI), U_OPTO_4.8 (COL1)
EXP_OUT_N: U_MAX488.6 (Z), X1.7
EXP_OUT_P: U_MAX488.5 (Y), X1.6
F_CLK: S70FL.16 (SCLK); also elsewhere on the board
F_CS1: S70FL.7 (CS1#); also elsewhere on the board
F_CS2: S70FL.6 (CS2#); also elsewhere on the board
F_MISO: S70FL.8 (SO/O1); also elsewhere on the board
F_MOSI: S70FL.15 (SI/O0); also elsewhere on the board
GND: C1.2, C2.2, C7.2, C8.2, C9.2, C10.2, C11.2, C12.2, C13.2, C14.2, C15.2, C16.2, C17.2, C18.2, C19.2, C20.2, C27.2, C28.1, C29.2, C30.2, C32.2, C35.1, C36.1, C37.1, C39.-, C40.-, C41.-, C64.-, C65.-, C66.-, C67.-, PROBES.2, PWR.C, Q1.2 (S), Q3.2 (S), Q4.2 (S), Q5.2 (S), Q6.2 (S), R21.1, R34.1, R43.2, R44.1, R53.1, REF4V096.P5 (A), S70FL.10 (VSS), SF2_M2S010TQ1.5 (VSS), SF2_M2S010TQ1.11 (VSS), SF2_M2S010TQ1.18 (VSS), SF2_M2S010TQ1.26 (VSS), SF2_M2S010TQ1.34 (VSS), SF2_M2S010TQ1.40 (VSS), SF2_M2S010TQ1.42 (VSS), SF2_M2S010TQ1.51 (VSS), SF2_M2S010TQ1.59 (VSS), SF2_M2S010TQ1.65 (VSS), SF2_M2S010TQ1.84 (VSS), SF2_M2S010TQ1.96 (VSSNVM), SF2_M2S010TQ1.98 (VSS), SF2_M2S010TQ1.113 (VSS), SF2_M2S010TQ1.119 (VSS), SF2_M2S010TQ1.126 (VSS), SF2_M2S010TQ1.132 (VSS), SF2_M2S010TQ1.139 (VSS), TPS78512QKVURQ1.4 (GND), TPS78512QKVURQ1.5 (GND), U$5.P2 (GND), U_LT1528.3 (GND), U_LT1528.6 (GND), U_OPTO_3.3 (A2), U_OPTO_3.4 (C2), U_OPTO_3.5 (EMT2), U_OPTO_3.6 (COL2), U_OPTO_3.7 (EMT1), U_OPTO_5.5 (EMT2), U_OPTO_5.7 (EMT1), U_TRACODCDC.5 (-VOUT), WP.1, ZE05H-4P-2V.P5, ZE05H-4P-2V.P6; also elsewhere on the board
LED_FPGA_LOADED: Q3.1 (G), R44.2; also elsewhere on the board
LED_HB_MEMSYNC: Q6.1 (G), R53.2; also elsewhere on the board
LED_HB_MSS: Q5.1 (G), R34.2; also elsewhere on the board
LED_RECORDING: Q4.1 (G), R21.2; also elsewhere on the board
LO: U_OPTO_5.8 (COL1); also elsewhere on the board
MAIN_EXTAL: RCJ1.1, SF2_M2S010TQ1.71 (XTLOSC_MAIN_EXTAL), Y1J2.2
MAIN_XTAL: RCJ2.1, SF2_M2S010TQ1.70 (XTLOSC_MAIN_XTAL), Y1J1.1
unnamed: C44.1, R10.1, R15.2
unnamed: R1.2, SF2_M2S010TQ1.72 (DEVRST_N)
unnamed: R23.1, U_OPTO_4.4 (C2)
unnamed: C3.1, C4.1, SF2_M2S010TQ1.106 (CCC_NE1_PLL_VSSA)
unnamed: C3.2, C4.2, R2.2, SF2_M2S010TQ1.107 (CCC_NE1_PLL_VDDA)
unnamed: C5.2, C6.2, R3.2, SF2_M2S010TQ1.109 (CCC_NE0_PLL_VDDA)
unnamed: C5.1, C6.1, SF2_M2S010TQ1.108 (CCC_NE0_PLL_VSSA)
unnamed: C30.1, Y1.1, Y1J1.2
unnamed: R13.2, U_OPTO_3.1 (A1)
unnamed: R12.2, U_OPTO_5.3 (A2)
unnamed: R11.2, U_OPTO_5.1 (A1)
unnamed: R22.1, U_OPTO_4.1 (A1)
unnamed: R14.1, U$5.P3 (OUT)
unnamed: PWR.A, R18.2
unnamed: MS.C, Q6.3 (D)
unnamed: MSS.C, Q5.3 (D)
unnamed: Q1.3 (D), U_OPTO_4.2 (C1)
unnamed: FL.A, R19.2
unnamed: MSS.A, R20.2
unnamed: C32.1, Y1.2, Y1J2.1
unnamed: MS.A, R52.2
unnamed: R49.2, RC.A
unnamed: R47.2, ZE05H-4P-2V.P4
unnamed: Q4.3 (D), RC.C, ZE05H-4P-2V.P1
unnamed: R48.2, ZE05H-4P-2V.P2
unnamed: FL.C, Q3.3 (D), ZE05H-4P-2V.P3
NET_U: C27.1, R4.1, RCJ1.2
PROBE_A: PROBES.1; also elsewhere on the board
PROBE_B: PROBES.3; also elsewhere on the board
RXSM_LO: U_OPTO_5.2 (C1), X1.5
RXSM_SODS: U_OPTO_5.4 (C2), X1.3
RXSM_SOE: U_OPTO_3.2 (C1), X1.4
SG_CLK: R14.2; also elsewhere on the board
SODS: U_OPTO_5.6 (COL2); also elsewhere on the board
SOE: U_OPTO_3.8 (COL1); also elsewhere on the board
TM_RX: R42.2, U_OPTO_4.6 (COL2); also elsewhere on the board
TM_TX: Q1.1 (G), R43.1; also elsewhere on the board
WP: S70FL.9 (WP#/IO2), WP.2; also elsewhere on the board

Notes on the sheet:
LM78L05ACMX/NOPB
Trim: up: R=(12775/U_out) - 2050 down: R=((U_out * 5110) / (5 - U_out)) - 2050
External LEDs: Dialight 559-2301-003F (Red) Dialight 559-2501-007F (Orange)
ZE05 matching parts: Plug ZE05-4S-HU/R Crimp ZE05-2022SCF
RC Network: 3,33...MHz = 1 / (2Ohm * 150nF)

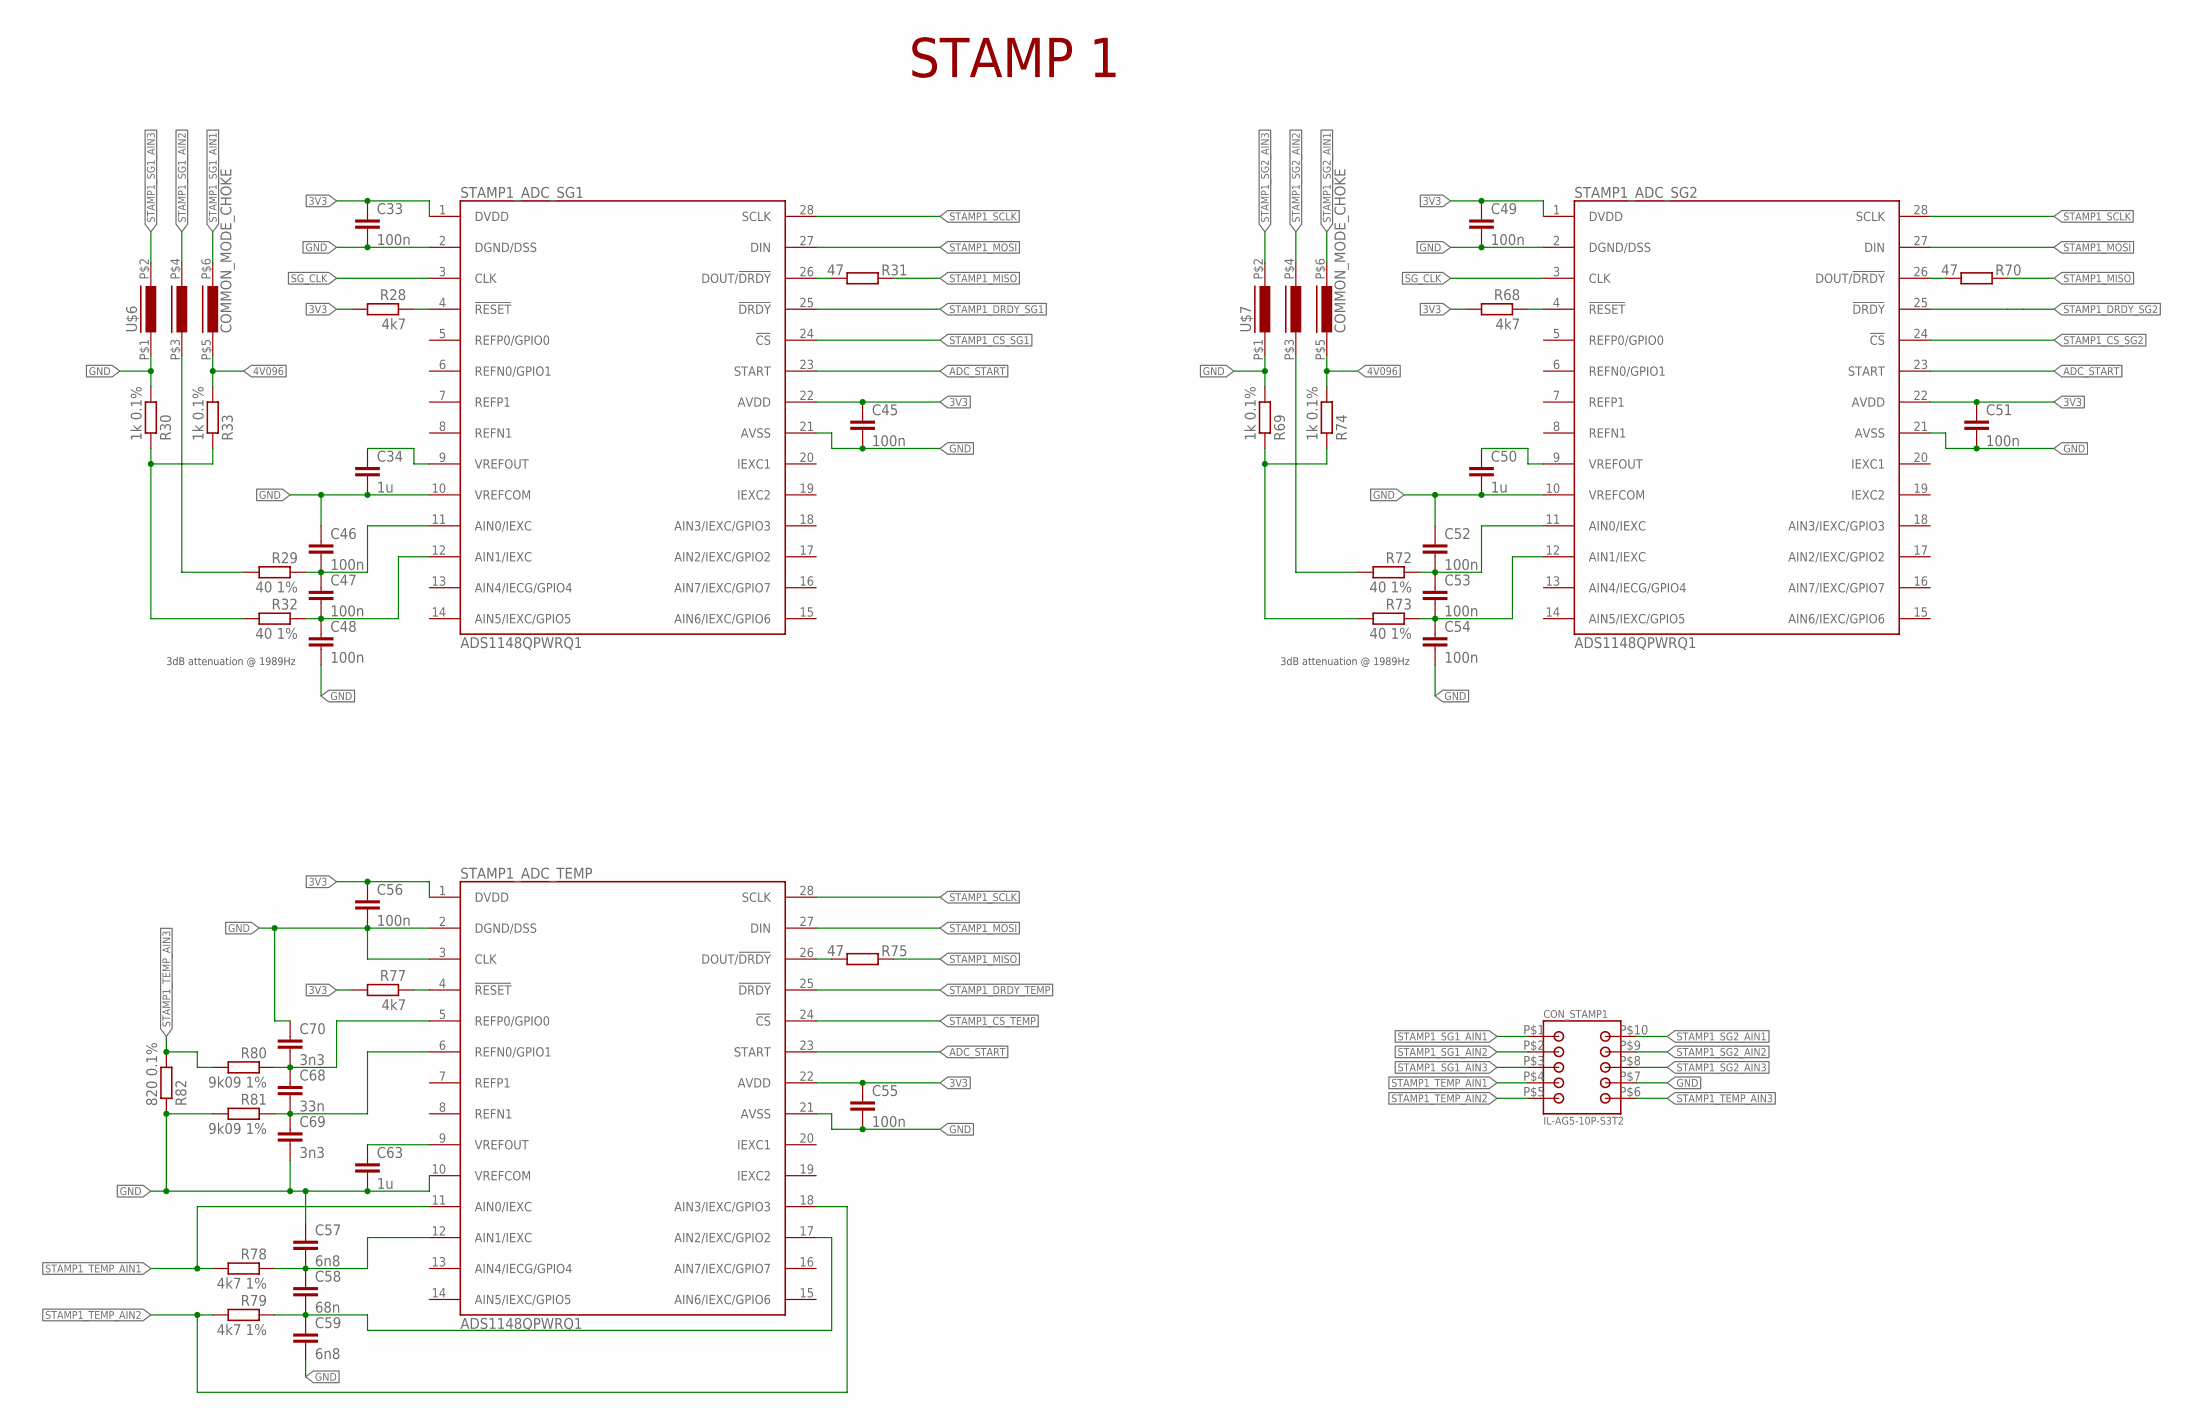
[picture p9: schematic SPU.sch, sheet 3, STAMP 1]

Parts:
C33, C45, C46, C47, C48, C49, C51, C52, C53, C54, C55, C56: 100n; C0805
C34, C50, C63: 1u; C0805
C57, C59: 6n8; C0805
C58: 68n; C0805
C68: 33n; C0805
C69, C70: 3n3; C0805
CON_STAMP1: IL-AG5-10P-S3T2
R28, R68, R77: 4k7; R0805
R29, R32, R72, R73: 40 1%; R0805
R30, R33, R69, R74: 1k 0.1%; R0805
R31, R70, R75: 47; R0805
R78, R79: 4k7 1%; R0805
R80, R81: 9k09 1%; R0805
R82: 820 0.1%; R0805
STAMP1_ADC_SG1, STAMP1_ADC_SG2, STAMP1_ADC_TEMP: ADS1148QPWRQ1; TSSOP28
U$6, U$7: COMMON_MODE_CHOKE

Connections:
3V3: C33.1, C45.1, C49.1, C51.1, C55.1, C56.1, R28.2, R68.2, R77.2, STAMP1_ADC_SG1.1 (DVDD), STAMP1_ADC_SG1.22 (AVDD), STAMP1_ADC_SG2.1 (DVDD), STAMP1_ADC_SG2.22 (AVDD), STAMP1_ADC_TEMP.1 (DVDD), STAMP1_ADC_TEMP.22 (AVDD); also elsewhere on the board
4V096: R33.2, R74.2, U$6.P$5 (5), U$7.P$5 (5); also elsewhere on the board
ADC_START: STAMP1_ADC_SG1.23 (START), STAMP1_ADC_SG2.23 (START), STAMP1_ADC_TEMP.23 (START); also elsewhere on the board
GND: C33.2, C34.2, C45.2, C46.1, C48.2, C49.2, C50.2, C51.2, C52.1, C54.2, C55.2, C56.2, C57.1, C59.2, C63.2, C69.2, C70.1, CON_STAMP1.P$7, R30.2, R69.2, R81.2, R82.1, STAMP1_ADC_SG1.2 (DGND/DSS), STAMP1_ADC_SG1.10 (VREFCOM), STAMP1_ADC_SG1.21 (AVSS), STAMP1_ADC_SG2.2 (DGND/DSS), STAMP1_ADC_SG2.10 (VREFCOM), STAMP1_ADC_SG2.21 (AVSS), STAMP1_ADC_TEMP.2 (DGND/DSS), STAMP1_ADC_TEMP.3 (CLK), STAMP1_ADC_TEMP.10 (VREFCOM), STAMP1_ADC_TEMP.21 (AVSS), U$6.P$1 (1), U$7.P$1 (1); also elsewhere on the board
unnamed: C34.1, STAMP1_ADC_SG1.9 (VREFOUT)
unnamed: R68.1, STAMP1_ADC_SG2.4 (!RESET)
unnamed: R28.1, STAMP1_ADC_SG1.4 (!RESET)
unnamed: R31.2, STAMP1_ADC_SG1.26 (DOUT/!DRDY)
unnamed: C46.2, C47.1, R29.1, STAMP1_ADC_SG1.11 (AIN0/IEXC)
unnamed: C47.2, C48.1, R32.1, STAMP1_ADC_SG1.12 (AIN1/IEXC)
unnamed: C50.1, STAMP1_ADC_SG2.9 (VREFOUT)
unnamed: R70.2, STAMP1_ADC_SG2.26 (DOUT/!DRDY)
unnamed: C52.2, C53.1, R72.1, STAMP1_ADC_SG2.11 (AIN0/IEXC)
unnamed: C53.2, C54.1, R73.1, STAMP1_ADC_SG2.12 (AIN1/IEXC)
unnamed: R30.1, R32.2, R33.1
unnamed: R69.1, R73.2, R74.1
unnamed: R29.2, U$6.P$3 (3)
unnamed: R72.2, U$7.P$3 (3)
unnamed: R75.2, STAMP1_ADC_TEMP.26 (DOUT/!DRDY)
unnamed: R77.1, STAMP1_ADC_TEMP.4 (!RESET)
unnamed: C57.2, C58.1, R78.1, STAMP1_ADC_TEMP.12 (AIN1/IEXC)
unnamed: C58.2, C59.1, R79.1, STAMP1_ADC_TEMP.17 (AIN2/IEXC/GPIO2)
unnamed: C63.1, STAMP1_ADC_TEMP.9 (VREFOUT)
unnamed: C68.2, C69.1, R81.1, STAMP1_ADC_TEMP.6 (REFN0/GPIO1)
unnamed: C68.1, C70.2, R80.1, STAMP1_ADC_TEMP.5 (REFP0/GPIO0)
SG_CLK: STAMP1_ADC_SG1.3 (CLK), STAMP1_ADC_SG2.3 (CLK); also elsewhere on the board
STAMP1_CS_SG1: STAMP1_ADC_SG1.24 (!CS); also elsewhere on the board
STAMP1_CS_SG2: STAMP1_ADC_SG2.24 (!CS); also elsewhere on the board
STAMP1_CS_TEMP: STAMP1_ADC_TEMP.24 (!CS); also elsewhere on the board
STAMP1_DRDY_SG1: STAMP1_ADC_SG1.25 (!DRDY); also elsewhere on the board
STAMP1_DRDY_SG2: STAMP1_ADC_SG2.25 (!DRDY); also elsewhere on the board
STAMP1_DRDY_TEMP: STAMP1_ADC_TEMP.25 (!DRDY); also elsewhere on the board
STAMP1_MISO: R31.1, R70.1, R75.1; also elsewhere on the board
STAMP1_MOSI: STAMP1_ADC_SG1.27 (DIN), STAMP1_ADC_SG2.27 (DIN), STAMP1_ADC_TEMP.27 (DIN); also elsewhere on the board
STAMP1_SCLK: STAMP1_ADC_SG1.28 (SCLK), STAMP1_ADC_SG2.28 (SCLK), STAMP1_ADC_TEMP.28 (SCLK); also elsewhere on the board
STAMP1_SG1_AIN1: CON_STAMP1.P$1, U$6.P$6 (6)
STAMP1_SG1_AIN2: CON_STAMP1.P$2, U$6.P$4 (4)
STAMP1_SG1_AIN3: CON_STAMP1.P$3, U$6.P$2 (2)
STAMP1_SG2_AIN1: CON_STAMP1.P$10, U$7.P$6 (6)
STAMP1_SG2_AIN2: CON_STAMP1.P$9, U$7.P$4 (4)
STAMP1_SG2_AIN3: CON_STAMP1.P$8, U$7.P$2 (2)
STAMP1_TEMP_AIN1: CON_STAMP1.P$4, R78.2, STAMP1_ADC_TEMP.11 (AIN0/IEXC)
STAMP1_TEMP_AIN2: CON_STAMP1.P$5, R79.2, STAMP1_ADC_TEMP.18 (AIN3/IEXC/GPIO3)
STAMP1_TEMP_AIN3: CON_STAMP1.P$6, R80.2, R82.2

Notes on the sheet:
3dB attenuation @ 1989Hz
STAMP 1

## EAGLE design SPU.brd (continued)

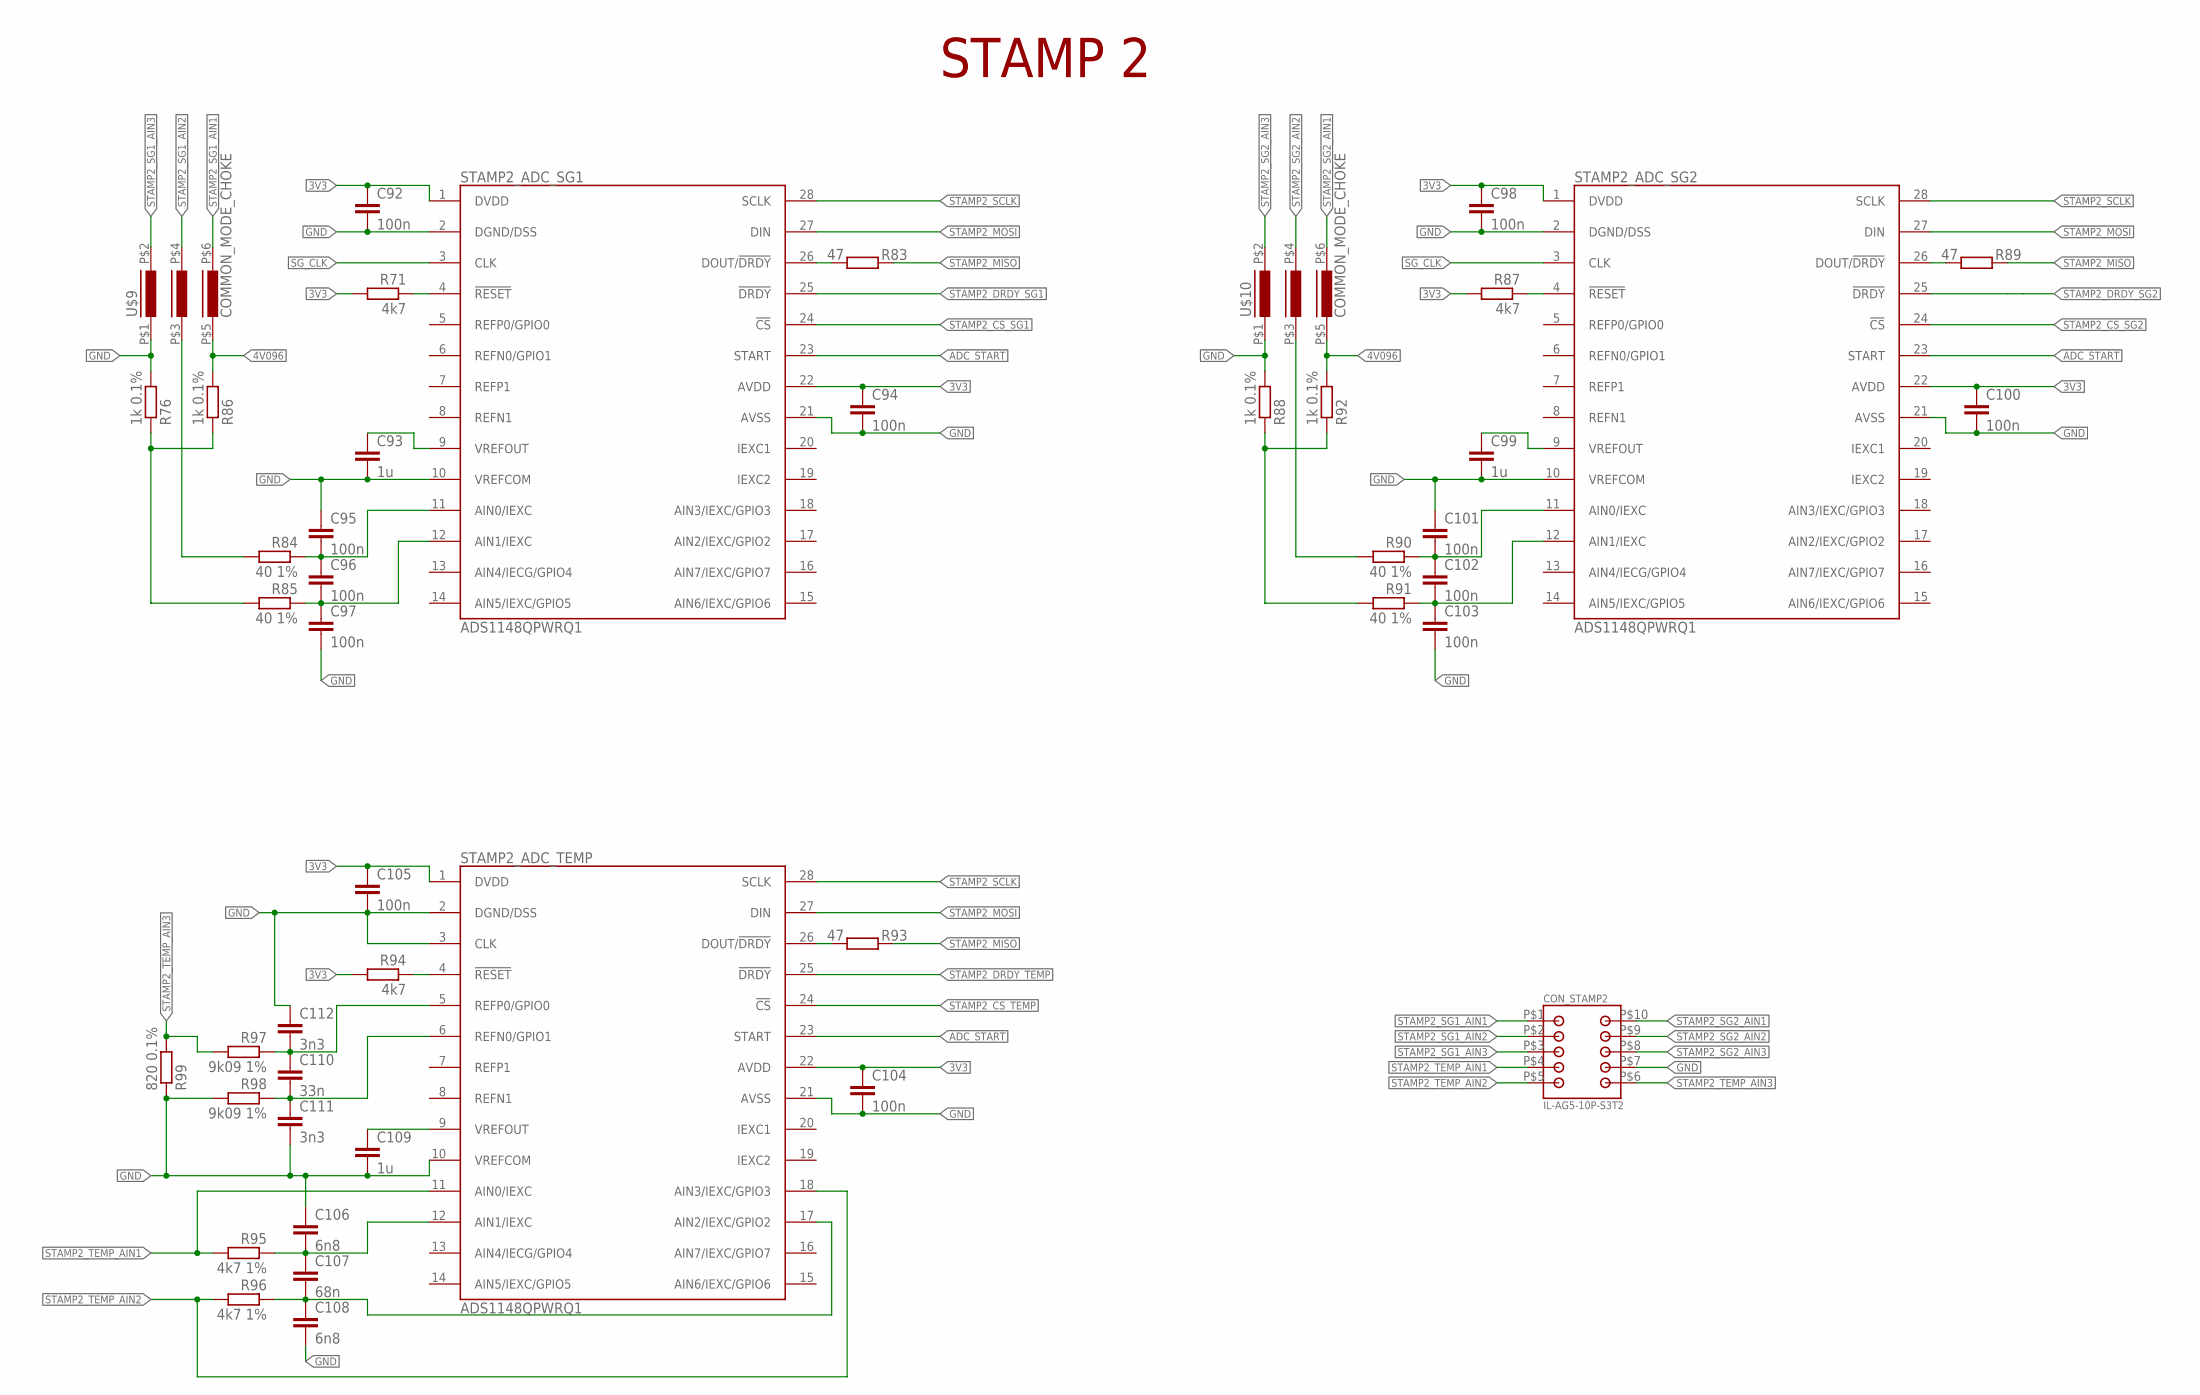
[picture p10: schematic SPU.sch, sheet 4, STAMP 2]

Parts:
C92, C94, C95, C96, C97, C98, C100, C101, C102, C103, C104, C105: 100n; C0805
C93, C99, C109: 1u; C0805
C106, C108: 6n8; C0805
C107: 68n; C0805
C110: 33n; C0805
C111, C112: 3n3; C0805
CON_STAMP2: IL-AG5-10P-S3T2
R71, R87, R94: 4k7; R0805
R76, R86, R88, R92: 1k 0.1%; R0805
R83, R89, R93: 47; R0805
R84, R85, R90, R91: 40 1%; R0805
R95, R96: 4k7 1%; R0805
R97, R98: 9k09 1%; R0805
R99: 820 0.1%; R0805
STAMP2_ADC_SG1, STAMP2_ADC_SG2, STAMP2_ADC_TEMP: ADS1148QPWRQ1; TSSOP28
U$9, U$10: COMMON_MODE_CHOKE

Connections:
3V3: C92.1, C94.1, C98.1, C100.1, C104.1, C105.1, R71.2, R87.2, R94.2, STAMP2_ADC_SG1.1 (DVDD), STAMP2_ADC_SG1.22 (AVDD), STAMP2_ADC_SG2.1 (DVDD), STAMP2_ADC_SG2.22 (AVDD), STAMP2_ADC_TEMP.1 (DVDD), STAMP2_ADC_TEMP.22 (AVDD); also elsewhere on the board
4V096: R86.2, R92.2, U$9.P$5 (5), U$10.P$5 (5); also elsewhere on the board
ADC_START: STAMP2_ADC_SG1.23 (START), STAMP2_ADC_SG2.23 (START), STAMP2_ADC_TEMP.23 (START); also elsewhere on the board
GND: C92.2, C93.2, C94.2, C95.1, C97.2, C98.2, C99.2, C100.2, C101.1, C103.2, C104.2, C105.2, C106.1, C108.2, C109.2, C111.2, C112.1, CON_STAMP2.P$7, R76.2, R88.2, R98.2, R99.1, STAMP2_ADC_SG1.2 (DGND/DSS), STAMP2_ADC_SG1.10 (VREFCOM), STAMP2_ADC_SG1.21 (AVSS), STAMP2_ADC_SG2.2 (DGND/DSS), STAMP2_ADC_SG2.10 (VREFCOM), STAMP2_ADC_SG2.21 (AVSS), STAMP2_ADC_TEMP.2 (DGND/DSS), STAMP2_ADC_TEMP.3 (CLK), STAMP2_ADC_TEMP.10 (VREFCOM), STAMP2_ADC_TEMP.21 (AVSS), U$9.P$1 (1), U$10.P$1 (1); also elsewhere on the board
unnamed: R71.1, STAMP2_ADC_SG1.4 (!RESET)
unnamed: C93.1, STAMP2_ADC_SG1.9 (VREFOUT)
unnamed: R83.2, STAMP2_ADC_SG1.26 (DOUT/!DRDY)
unnamed: C95.2, C96.1, R84.1, STAMP2_ADC_SG1.11 (AIN0/IEXC)
unnamed: C96.2, C97.1, R85.1, STAMP2_ADC_SG1.12 (AIN1/IEXC)
unnamed: R76.1, R85.2, R86.1
unnamed: R84.2, U$9.P$3 (3)
unnamed: R87.1, STAMP2_ADC_SG2.4 (!RESET)
unnamed: C99.1, STAMP2_ADC_SG2.9 (VREFOUT)
unnamed: R89.2, STAMP2_ADC_SG2.26 (DOUT/!DRDY)
unnamed: C101.2, C102.1, R90.1, STAMP2_ADC_SG2.11 (AIN0/IEXC)
unnamed: C102.2, C103.1, R91.1, STAMP2_ADC_SG2.12 (AIN1/IEXC)
unnamed: R88.1, R91.2, R92.1
unnamed: R90.2, U$10.P$3 (3)
unnamed: R93.2, STAMP2_ADC_TEMP.26 (DOUT/!DRDY)
unnamed: R94.1, STAMP2_ADC_TEMP.4 (!RESET)
unnamed: C106.2, C107.1, R95.1, STAMP2_ADC_TEMP.12 (AIN1/IEXC)
unnamed: C107.2, C108.1, R96.1, STAMP2_ADC_TEMP.17 (AIN2/IEXC/GPIO2)
unnamed: C109.1, STAMP2_ADC_TEMP.9 (VREFOUT)
S2AT1: C110.1, C112.2, R97.1, STAMP2_ADC_TEMP.5 (REFP0/GPIO0)
S2AT2: C110.2, C111.1, R98.1, STAMP2_ADC_TEMP.6 (REFN0/GPIO1)
SG_CLK: STAMP2_ADC_SG1.3 (CLK), STAMP2_ADC_SG2.3 (CLK); also elsewhere on the board
STAMP2_CS_SG1: STAMP2_ADC_SG1.24 (!CS); also elsewhere on the board
STAMP2_CS_SG2: STAMP2_ADC_SG2.24 (!CS); also elsewhere on the board
STAMP2_CS_TEMP: STAMP2_ADC_TEMP.24 (!CS); also elsewhere on the board
STAMP2_DRDY_SG1: STAMP2_ADC_SG1.25 (!DRDY); also elsewhere on the board
STAMP2_DRDY_SG2: STAMP2_ADC_SG2.25 (!DRDY); also elsewhere on the board
STAMP2_DRDY_TEMP: STAMP2_ADC_TEMP.25 (!DRDY); also elsewhere on the board
STAMP2_MISO: R83.1, R89.1, R93.1; also elsewhere on the board
STAMP2_MOSI: STAMP2_ADC_SG1.27 (DIN), STAMP2_ADC_SG2.27 (DIN), STAMP2_ADC_TEMP.27 (DIN); also elsewhere on the board
STAMP2_SCLK: STAMP2_ADC_SG1.28 (SCLK), STAMP2_ADC_SG2.28 (SCLK), STAMP2_ADC_TEMP.28 (SCLK); also elsewhere on the board
STAMP2_SG1_AIN1: CON_STAMP2.P$1, U$9.P$6 (6)
STAMP2_SG1_AIN2: CON_STAMP2.P$2, U$9.P$4 (4)
STAMP2_SG1_AIN3: CON_STAMP2.P$3, U$9.P$2 (2)
STAMP2_SG2_AIN1: CON_STAMP2.P$10, U$10.P$6 (6)
STAMP2_SG2_AIN2: CON_STAMP2.P$9, U$10.P$4 (4)
STAMP2_SG2_AIN3: CON_STAMP2.P$8, U$10.P$2 (2)
STAMP2_TEMP_AIN1: CON_STAMP2.P$4, R95.2, STAMP2_ADC_TEMP.11 (AIN0/IEXC)
STAMP2_TEMP_AIN2: CON_STAMP2.P$5, R96.2, STAMP2_ADC_TEMP.18 (AIN3/IEXC/GPIO3)
STAMP2_TEMP_AIN3: CON_STAMP2.P$6, R97.2, R99.2

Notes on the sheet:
STAMP 2

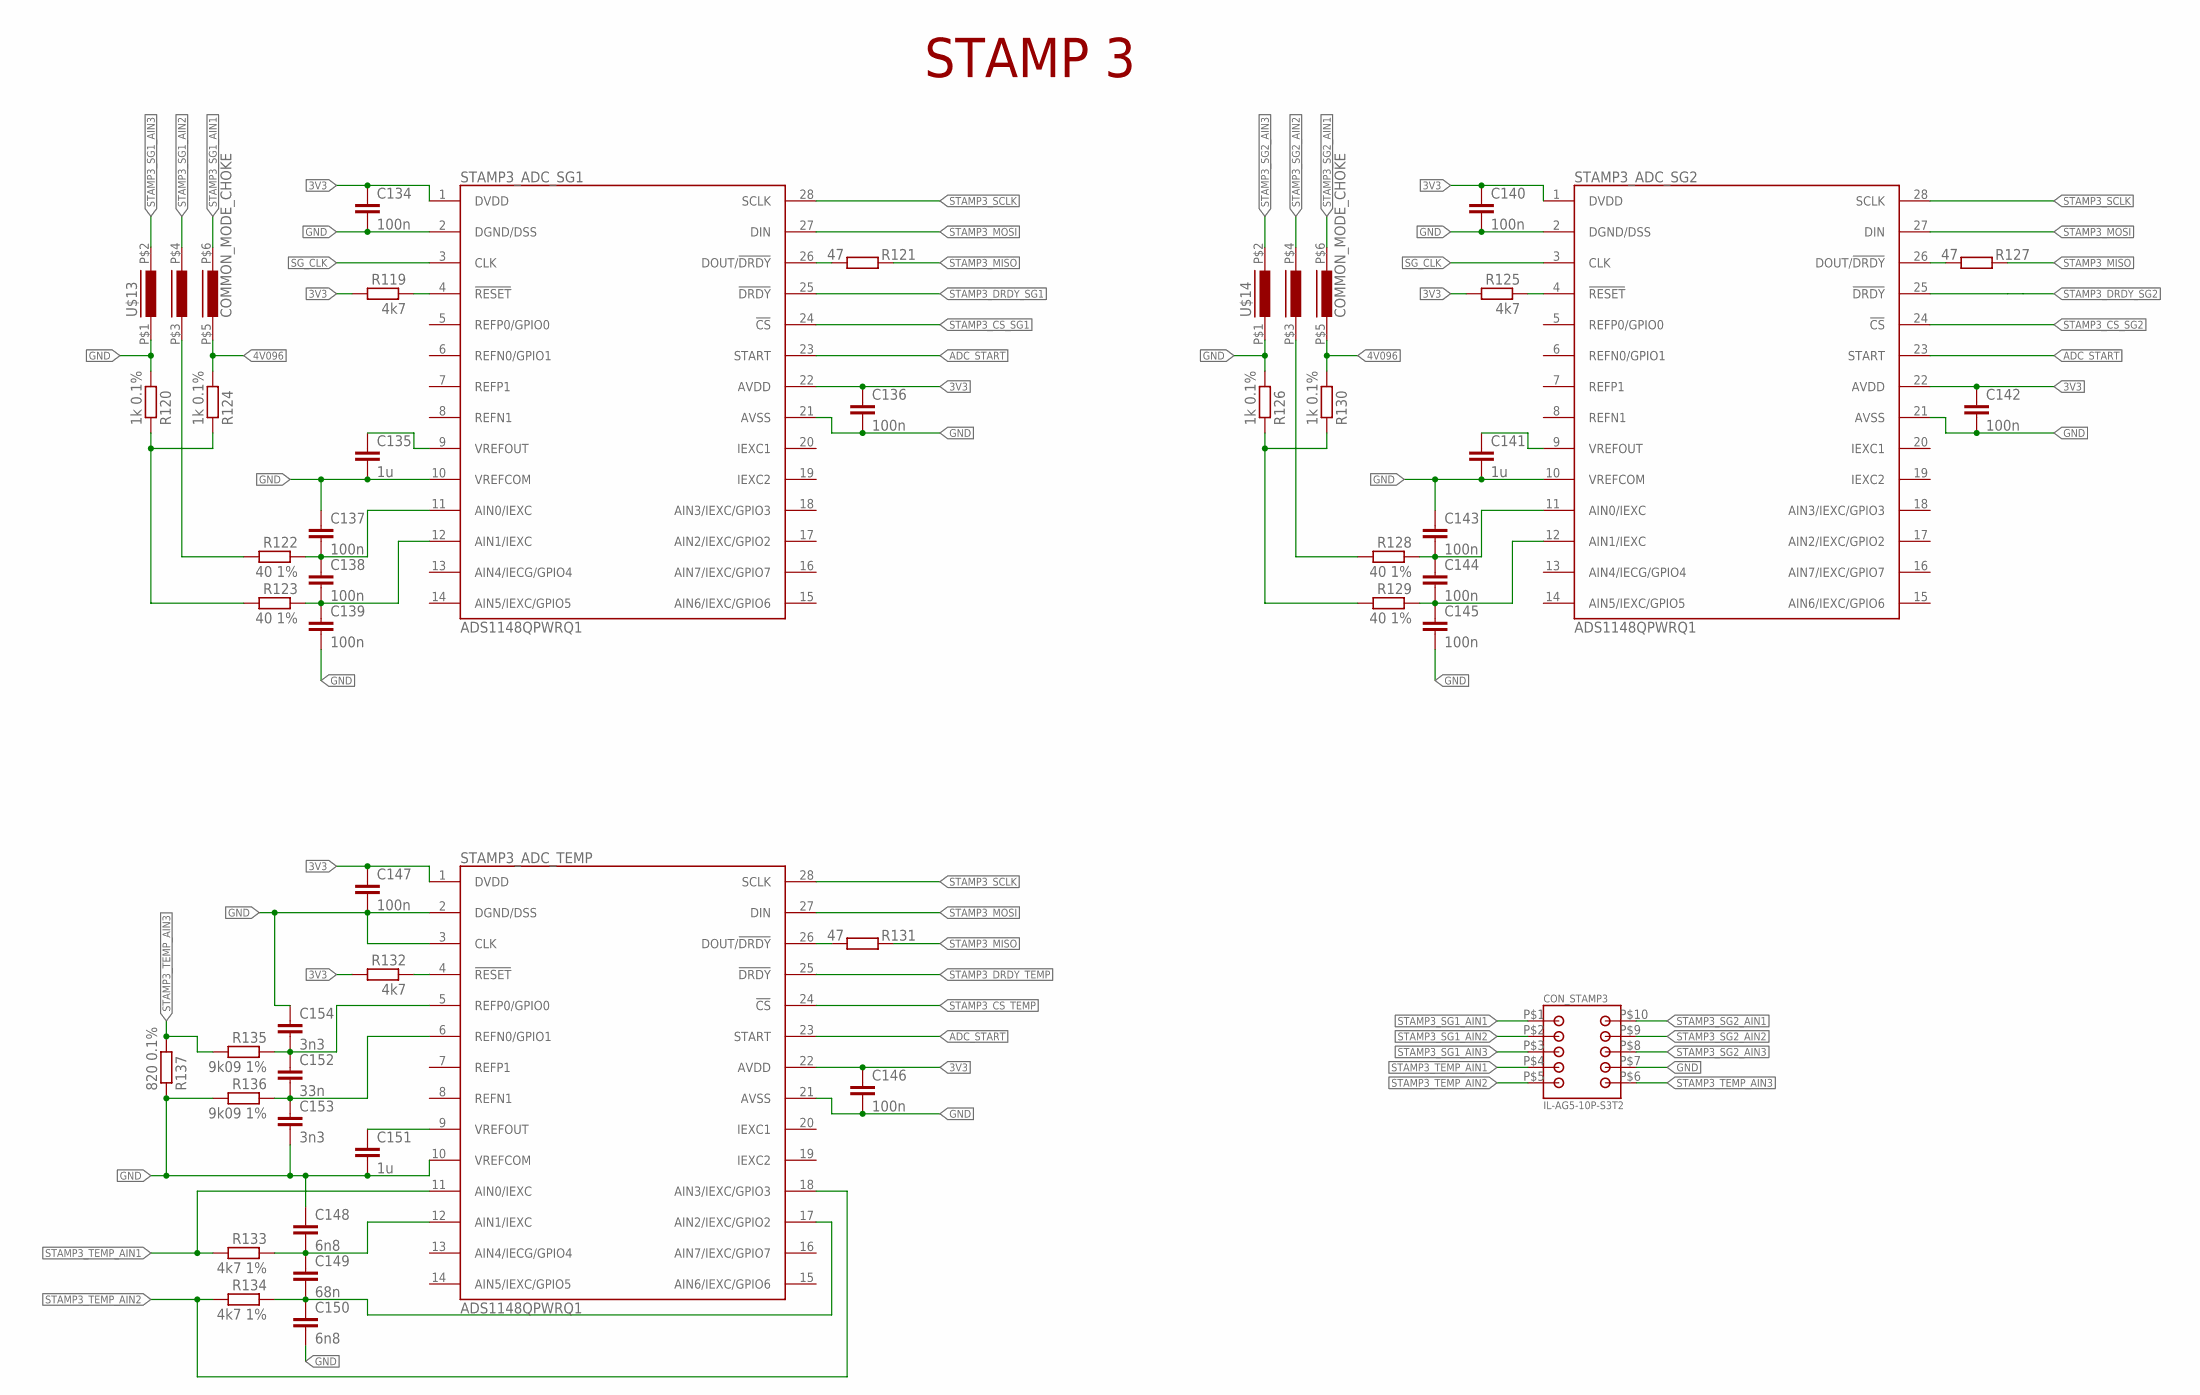
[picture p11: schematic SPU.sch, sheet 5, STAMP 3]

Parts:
C134, C136, C137, C138, C139, C140, C142, C143, C144, C145, C146, C147: 100n; C0805
C135, C141, C151: 1u; C0805
C148, C150: 6n8; C0805
C149: 68n; C0805
C152: 33n; C0805
C153, C154: 3n3; C0805
CON_STAMP3: IL-AG5-10P-S3T2
R119, R125, R132: 4k7; R0805
R120, R124, R126, R130: 1k 0.1%; R0805
R121, R127, R131: 47; R0805
R122, R123, R128, R129: 40 1%; R0805
R133, R134: 4k7 1%; R0805
R135, R136: 9k09 1%; R0805
R137: 820 0.1%; R0805
STAMP3_ADC_SG1, STAMP3_ADC_SG2, STAMP3_ADC_TEMP: ADS1148QPWRQ1; TSSOP28
U$13, U$14: COMMON_MODE_CHOKE

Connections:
3V3: C134.1, C136.1, C140.1, C142.1, C146.1, C147.1, R119.2, R125.2, R132.2, STAMP3_ADC_SG1.1 (DVDD), STAMP3_ADC_SG1.22 (AVDD), STAMP3_ADC_SG2.1 (DVDD), STAMP3_ADC_SG2.22 (AVDD), STAMP3_ADC_TEMP.1 (DVDD), STAMP3_ADC_TEMP.22 (AVDD); also elsewhere on the board
4V096: R124.2, R130.2, U$13.P$5 (5), U$14.P$5 (5); also elsewhere on the board
ADC_START: STAMP3_ADC_SG1.23 (START), STAMP3_ADC_SG2.23 (START), STAMP3_ADC_TEMP.23 (START); also elsewhere on the board
GND: C134.2, C135.2, C136.2, C137.1, C139.2, C140.2, C141.2, C142.2, C143.1, C145.2, C146.2, C147.2, C148.1, C150.2, C151.2, C153.2, C154.1, CON_STAMP3.P$7, R120.2, R126.2, R136.2, R137.1, STAMP3_ADC_SG1.2 (DGND/DSS), STAMP3_ADC_SG1.10 (VREFCOM), STAMP3_ADC_SG1.21 (AVSS), STAMP3_ADC_SG2.2 (DGND/DSS), STAMP3_ADC_SG2.10 (VREFCOM), STAMP3_ADC_SG2.21 (AVSS), STAMP3_ADC_TEMP.2 (DGND/DSS), STAMP3_ADC_TEMP.3 (CLK), STAMP3_ADC_TEMP.10 (VREFCOM), STAMP3_ADC_TEMP.21 (AVSS), U$13.P$1 (1), U$14.P$1 (1); also elsewhere on the board
unnamed: R119.1, STAMP3_ADC_SG1.4 (!RESET)
unnamed: C135.1, STAMP3_ADC_SG1.9 (VREFOUT)
unnamed: R121.2, STAMP3_ADC_SG1.26 (DOUT/!DRDY)
unnamed: C137.2, C138.1, R122.1, STAMP3_ADC_SG1.11 (AIN0/IEXC)
unnamed: C138.2, C139.1, R123.1, STAMP3_ADC_SG1.12 (AIN1/IEXC)
unnamed: R120.1, R123.2, R124.1
unnamed: R122.2, U$13.P$3 (3)
unnamed: R125.1, STAMP3_ADC_SG2.4 (!RESET)
unnamed: C141.1, STAMP3_ADC_SG2.9 (VREFOUT)
unnamed: R127.2, STAMP3_ADC_SG2.26 (DOUT/!DRDY)
unnamed: C143.2, C144.1, R128.1, STAMP3_ADC_SG2.11 (AIN0/IEXC)
unnamed: C144.2, C145.1, R129.1, STAMP3_ADC_SG2.12 (AIN1/IEXC)
unnamed: R126.1, R129.2, R130.1
unnamed: R128.2, U$14.P$3 (3)
unnamed: R131.2, STAMP3_ADC_TEMP.26 (DOUT/!DRDY)
unnamed: R132.1, STAMP3_ADC_TEMP.4 (!RESET)
unnamed: C148.2, C149.1, R133.1, STAMP3_ADC_TEMP.12 (AIN1/IEXC)
unnamed: C149.2, C150.1, R134.1, STAMP3_ADC_TEMP.17 (AIN2/IEXC/GPIO2)
unnamed: C151.1, STAMP3_ADC_TEMP.9 (VREFOUT)
unnamed: C152.2, C153.1, R136.1, STAMP3_ADC_TEMP.6 (REFN0/GPIO1)
unnamed: C152.1, C154.2, R135.1, STAMP3_ADC_TEMP.5 (REFP0/GPIO0)
SG_CLK: STAMP3_ADC_SG1.3 (CLK), STAMP3_ADC_SG2.3 (CLK); also elsewhere on the board
STAMP3_CS_SG1: STAMP3_ADC_SG1.24 (!CS); also elsewhere on the board
STAMP3_CS_SG2: STAMP3_ADC_SG2.24 (!CS); also elsewhere on the board
STAMP3_CS_TEMP: STAMP3_ADC_TEMP.24 (!CS); also elsewhere on the board
STAMP3_DRDY_SG1: STAMP3_ADC_SG1.25 (!DRDY); also elsewhere on the board
STAMP3_DRDY_SG2: STAMP3_ADC_SG2.25 (!DRDY); also elsewhere on the board
STAMP3_DRDY_TEMP: STAMP3_ADC_TEMP.25 (!DRDY); also elsewhere on the board
STAMP3_MISO: R121.1, R127.1, R131.1; also elsewhere on the board
STAMP3_MOSI: STAMP3_ADC_SG1.27 (DIN), STAMP3_ADC_SG2.27 (DIN), STAMP3_ADC_TEMP.27 (DIN); also elsewhere on the board
STAMP3_SCLK: STAMP3_ADC_SG1.28 (SCLK), STAMP3_ADC_SG2.28 (SCLK), STAMP3_ADC_TEMP.28 (SCLK); also elsewhere on the board
STAMP3_SG1_AIN1: CON_STAMP3.P$1, U$13.P$6 (6)
STAMP3_SG1_AIN2: CON_STAMP3.P$2, U$13.P$4 (4)
STAMP3_SG1_AIN3: CON_STAMP3.P$3, U$13.P$2 (2)
STAMP3_SG2_AIN1: CON_STAMP3.P$10, U$14.P$6 (6)
STAMP3_SG2_AIN2: CON_STAMP3.P$9, U$14.P$4 (4)
STAMP3_SG2_AIN3: CON_STAMP3.P$8, U$14.P$2 (2)
STAMP3_TEMP_AIN1: CON_STAMP3.P$4, R133.2, STAMP3_ADC_TEMP.11 (AIN0/IEXC)
STAMP3_TEMP_AIN2: CON_STAMP3.P$5, R134.2, STAMP3_ADC_TEMP.18 (AIN3/IEXC/GPIO3)
STAMP3_TEMP_AIN3: CON_STAMP3.P$6, R135.2, R137.2

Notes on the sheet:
STAMP 3

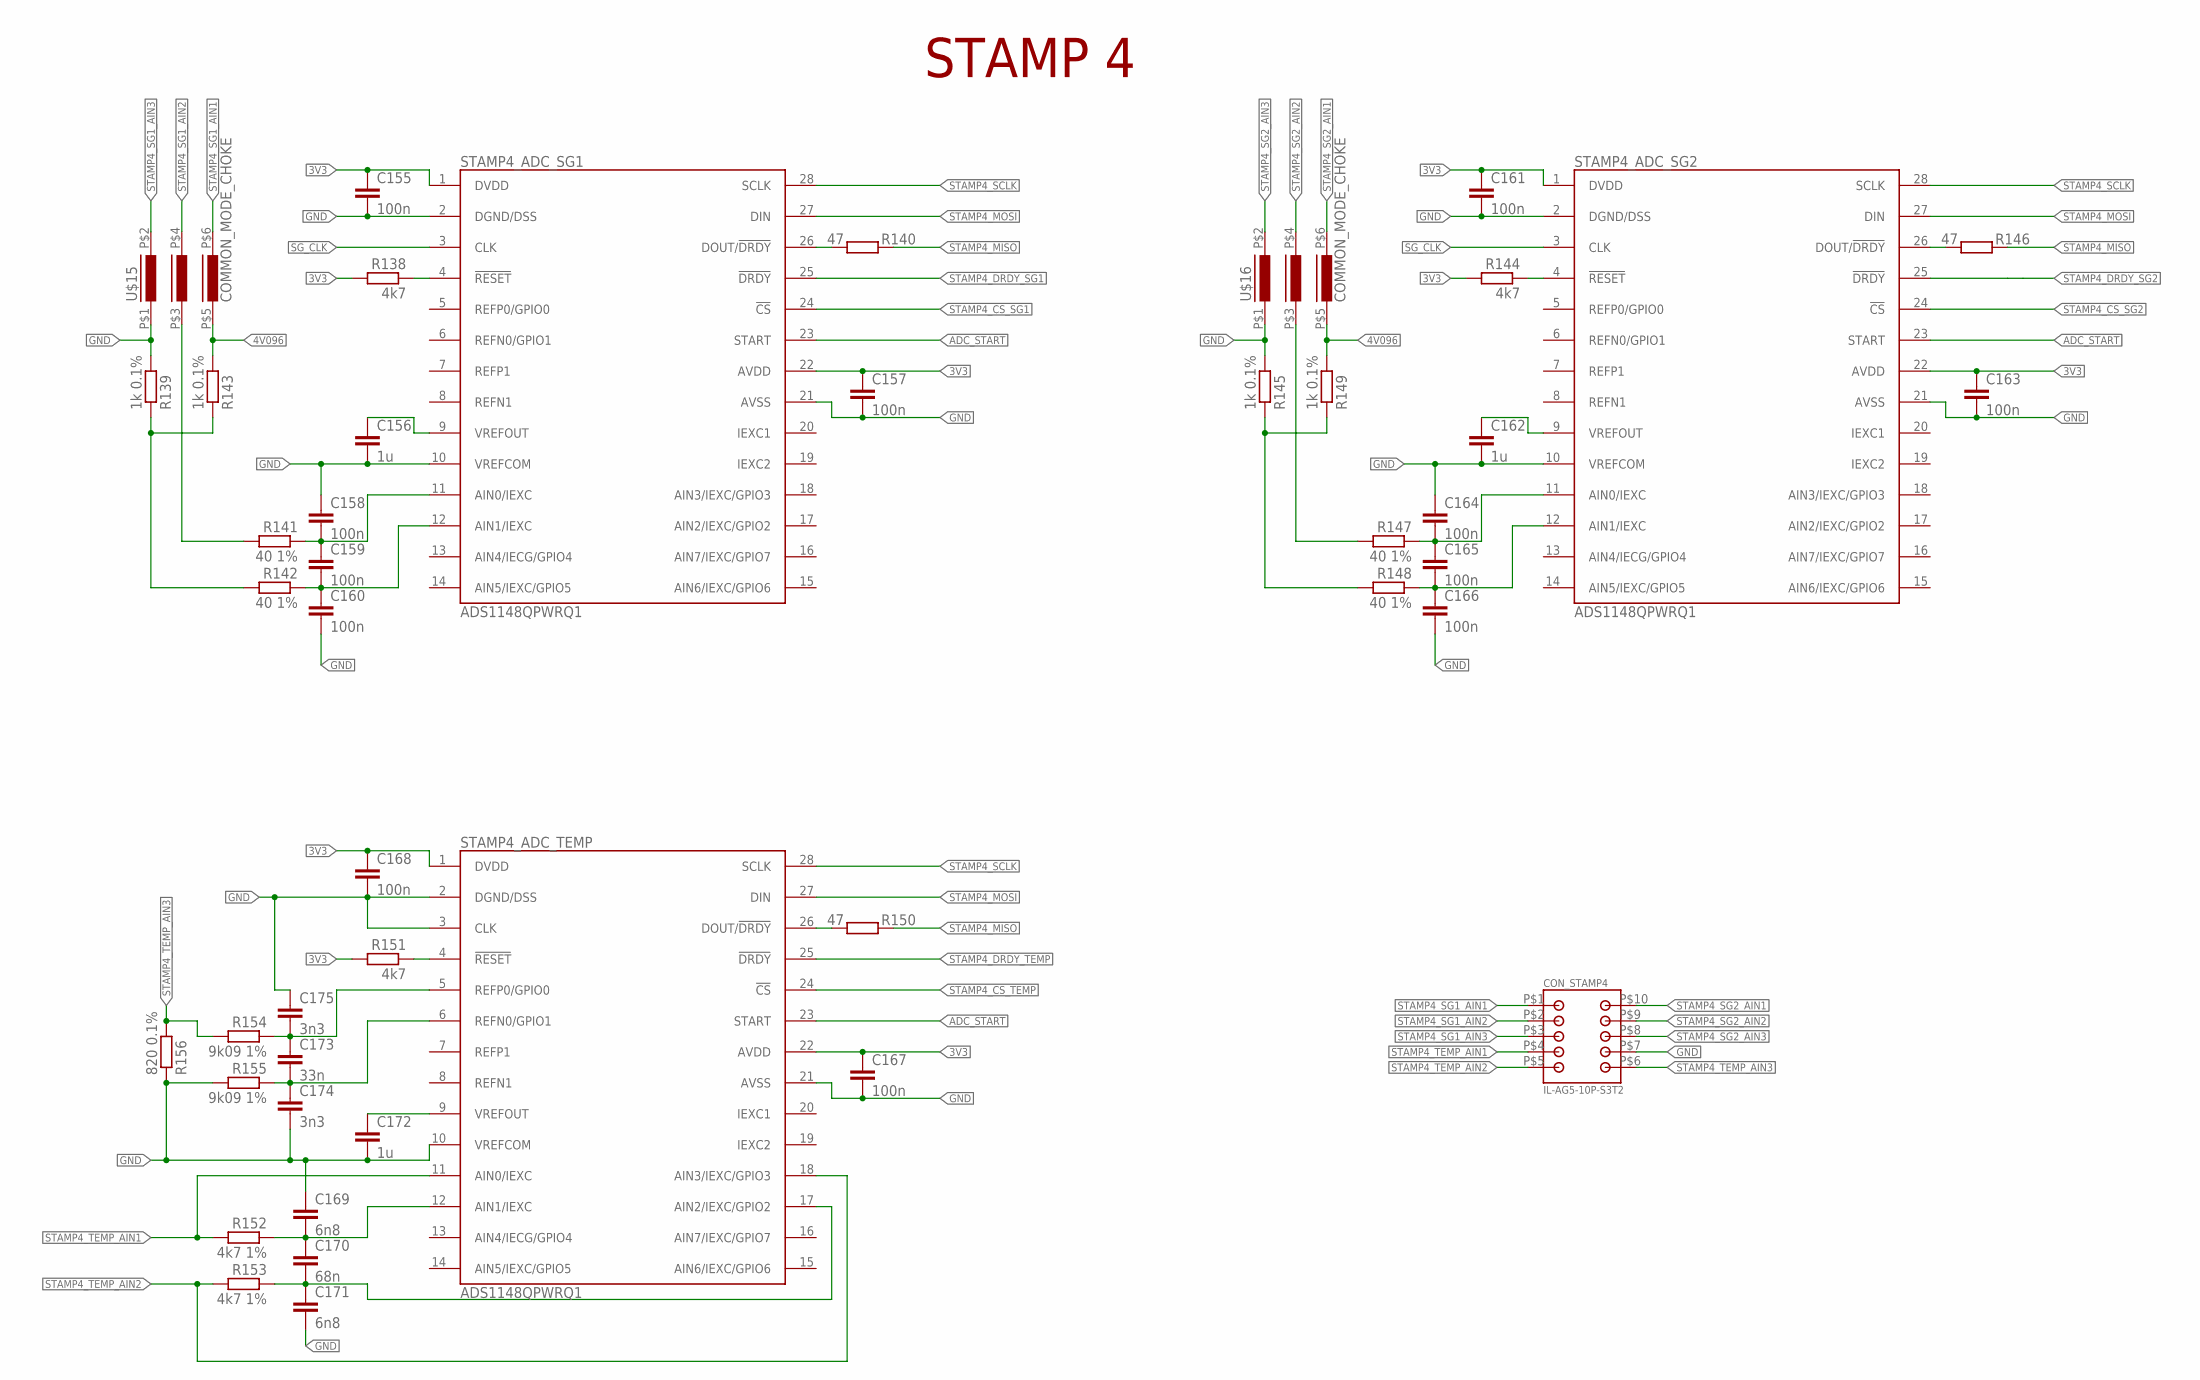
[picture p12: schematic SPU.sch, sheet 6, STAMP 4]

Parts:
C155, C157, C158, C159, C160, C161, C163, C164, C165, C166, C167, C168: 100n; C0805
C156, C162, C172: 1u; C0805
C169, C171: 6n8; C0805
C170: 68n; C0805
C173: 33n; C0805
C174, C175: 3n3; C0805
CON_STAMP4: IL-AG5-10P-S3T2
R138, R144, R151: 4k7; R0805
R139, R143, R145, R149: 1k 0.1%; R0805
R140, R146, R150: 47; R0805
R141, R142, R147, R148: 40 1%; R0805
R152, R153: 4k7 1%; R0805
R154, R155: 9k09 1%; R0805
R156: 820 0.1%; R0805
STAMP4_ADC_SG1, STAMP4_ADC_SG2, STAMP4_ADC_TEMP: ADS1148QPWRQ1; TSSOP28
U$15, U$16: COMMON_MODE_CHOKE

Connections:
3V3: C155.1, C157.1, C161.1, C163.1, C167.1, C168.1, R138.2, R144.2, R151.2, STAMP4_ADC_SG1.1 (DVDD), STAMP4_ADC_SG1.22 (AVDD), STAMP4_ADC_SG2.1 (DVDD), STAMP4_ADC_SG2.22 (AVDD), STAMP4_ADC_TEMP.1 (DVDD), STAMP4_ADC_TEMP.22 (AVDD); also elsewhere on the board
4V096: R143.2, R149.2, U$15.P$5 (5), U$16.P$5 (5); also elsewhere on the board
ADC_START: STAMP4_ADC_SG1.23 (START), STAMP4_ADC_SG2.23 (START), STAMP4_ADC_TEMP.23 (START); also elsewhere on the board
GND: C155.2, C156.2, C157.2, C158.1, C160.2, C161.2, C162.2, C163.2, C164.1, C166.2, C167.2, C168.2, C169.1, C171.2, C172.2, C174.2, C175.1, CON_STAMP4.P$7, R139.2, R145.2, R155.2, R156.1, STAMP4_ADC_SG1.2 (DGND/DSS), STAMP4_ADC_SG1.10 (VREFCOM), STAMP4_ADC_SG1.21 (AVSS), STAMP4_ADC_SG2.2 (DGND/DSS), STAMP4_ADC_SG2.10 (VREFCOM), STAMP4_ADC_SG2.21 (AVSS), STAMP4_ADC_TEMP.2 (DGND/DSS), STAMP4_ADC_TEMP.3 (CLK), STAMP4_ADC_TEMP.10 (VREFCOM), STAMP4_ADC_TEMP.21 (AVSS), U$15.P$1 (1), U$16.P$1 (1); also elsewhere on the board
unnamed: R138.1, STAMP4_ADC_SG1.4 (!RESET)
unnamed: C156.1, STAMP4_ADC_SG1.9 (VREFOUT)
unnamed: R140.2, STAMP4_ADC_SG1.26 (DOUT/!DRDY)
unnamed: C158.2, C159.1, R141.1, STAMP4_ADC_SG1.11 (AIN0/IEXC)
unnamed: C159.2, C160.1, R142.1, STAMP4_ADC_SG1.12 (AIN1/IEXC)
unnamed: R139.1, R142.2, R143.1
unnamed: R141.2, U$15.P$3 (3)
unnamed: R144.1, STAMP4_ADC_SG2.4 (!RESET)
unnamed: C162.1, STAMP4_ADC_SG2.9 (VREFOUT)
unnamed: R146.2, STAMP4_ADC_SG2.26 (DOUT/!DRDY)
unnamed: C164.2, C165.1, R147.1, STAMP4_ADC_SG2.11 (AIN0/IEXC)
unnamed: C165.2, C166.1, R148.1, STAMP4_ADC_SG2.12 (AIN1/IEXC)
unnamed: R145.1, R148.2, R149.1
unnamed: R147.2, U$16.P$3 (3)
unnamed: R150.2, STAMP4_ADC_TEMP.26 (DOUT/!DRDY)
unnamed: R151.1, STAMP4_ADC_TEMP.4 (!RESET)
unnamed: C169.2, C170.1, R152.1, STAMP4_ADC_TEMP.12 (AIN1/IEXC)
unnamed: C170.2, C171.1, R153.1, STAMP4_ADC_TEMP.17 (AIN2/IEXC/GPIO2)
unnamed: C172.1, STAMP4_ADC_TEMP.9 (VREFOUT)
unnamed: C173.2, C174.1, R155.1, STAMP4_ADC_TEMP.6 (REFN0/GPIO1)
unnamed: C173.1, C175.2, R154.1, STAMP4_ADC_TEMP.5 (REFP0/GPIO0)
SG_CLK: STAMP4_ADC_SG1.3 (CLK), STAMP4_ADC_SG2.3 (CLK); also elsewhere on the board
STAMP4_CS_SG1: STAMP4_ADC_SG1.24 (!CS); also elsewhere on the board
STAMP4_CS_SG2: STAMP4_ADC_SG2.24 (!CS); also elsewhere on the board
STAMP4_CS_TEMP: STAMP4_ADC_TEMP.24 (!CS); also elsewhere on the board
STAMP4_DRDY_SG1: STAMP4_ADC_SG1.25 (!DRDY); also elsewhere on the board
STAMP4_DRDY_SG2: STAMP4_ADC_SG2.25 (!DRDY); also elsewhere on the board
STAMP4_DRDY_TEMP: STAMP4_ADC_TEMP.25 (!DRDY); also elsewhere on the board
STAMP4_MISO: R140.1, R146.1, R150.1; also elsewhere on the board
STAMP4_MOSI: STAMP4_ADC_SG1.27 (DIN), STAMP4_ADC_SG2.27 (DIN), STAMP4_ADC_TEMP.27 (DIN); also elsewhere on the board
STAMP4_SCLK: STAMP4_ADC_SG1.28 (SCLK), STAMP4_ADC_SG2.28 (SCLK), STAMP4_ADC_TEMP.28 (SCLK); also elsewhere on the board
STAMP4_SG1_AIN1: CON_STAMP4.P$1, U$15.P$6 (6)
STAMP4_SG1_AIN2: CON_STAMP4.P$2, U$15.P$4 (4)
STAMP4_SG1_AIN3: CON_STAMP4.P$3, U$15.P$2 (2)
STAMP4_SG2_AIN1: CON_STAMP4.P$10, U$16.P$6 (6)
STAMP4_SG2_AIN2: CON_STAMP4.P$9, U$16.P$4 (4)
STAMP4_SG2_AIN3: CON_STAMP4.P$8, U$16.P$2 (2)
STAMP4_TEMP_AIN1: CON_STAMP4.P$4, R152.2, STAMP4_ADC_TEMP.11 (AIN0/IEXC)
STAMP4_TEMP_AIN2: CON_STAMP4.P$5, R153.2, STAMP4_ADC_TEMP.18 (AIN3/IEXC/GPIO3)
STAMP4_TEMP_AIN3: CON_STAMP4.P$6, R154.2, R156.2

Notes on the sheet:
STAMP 4

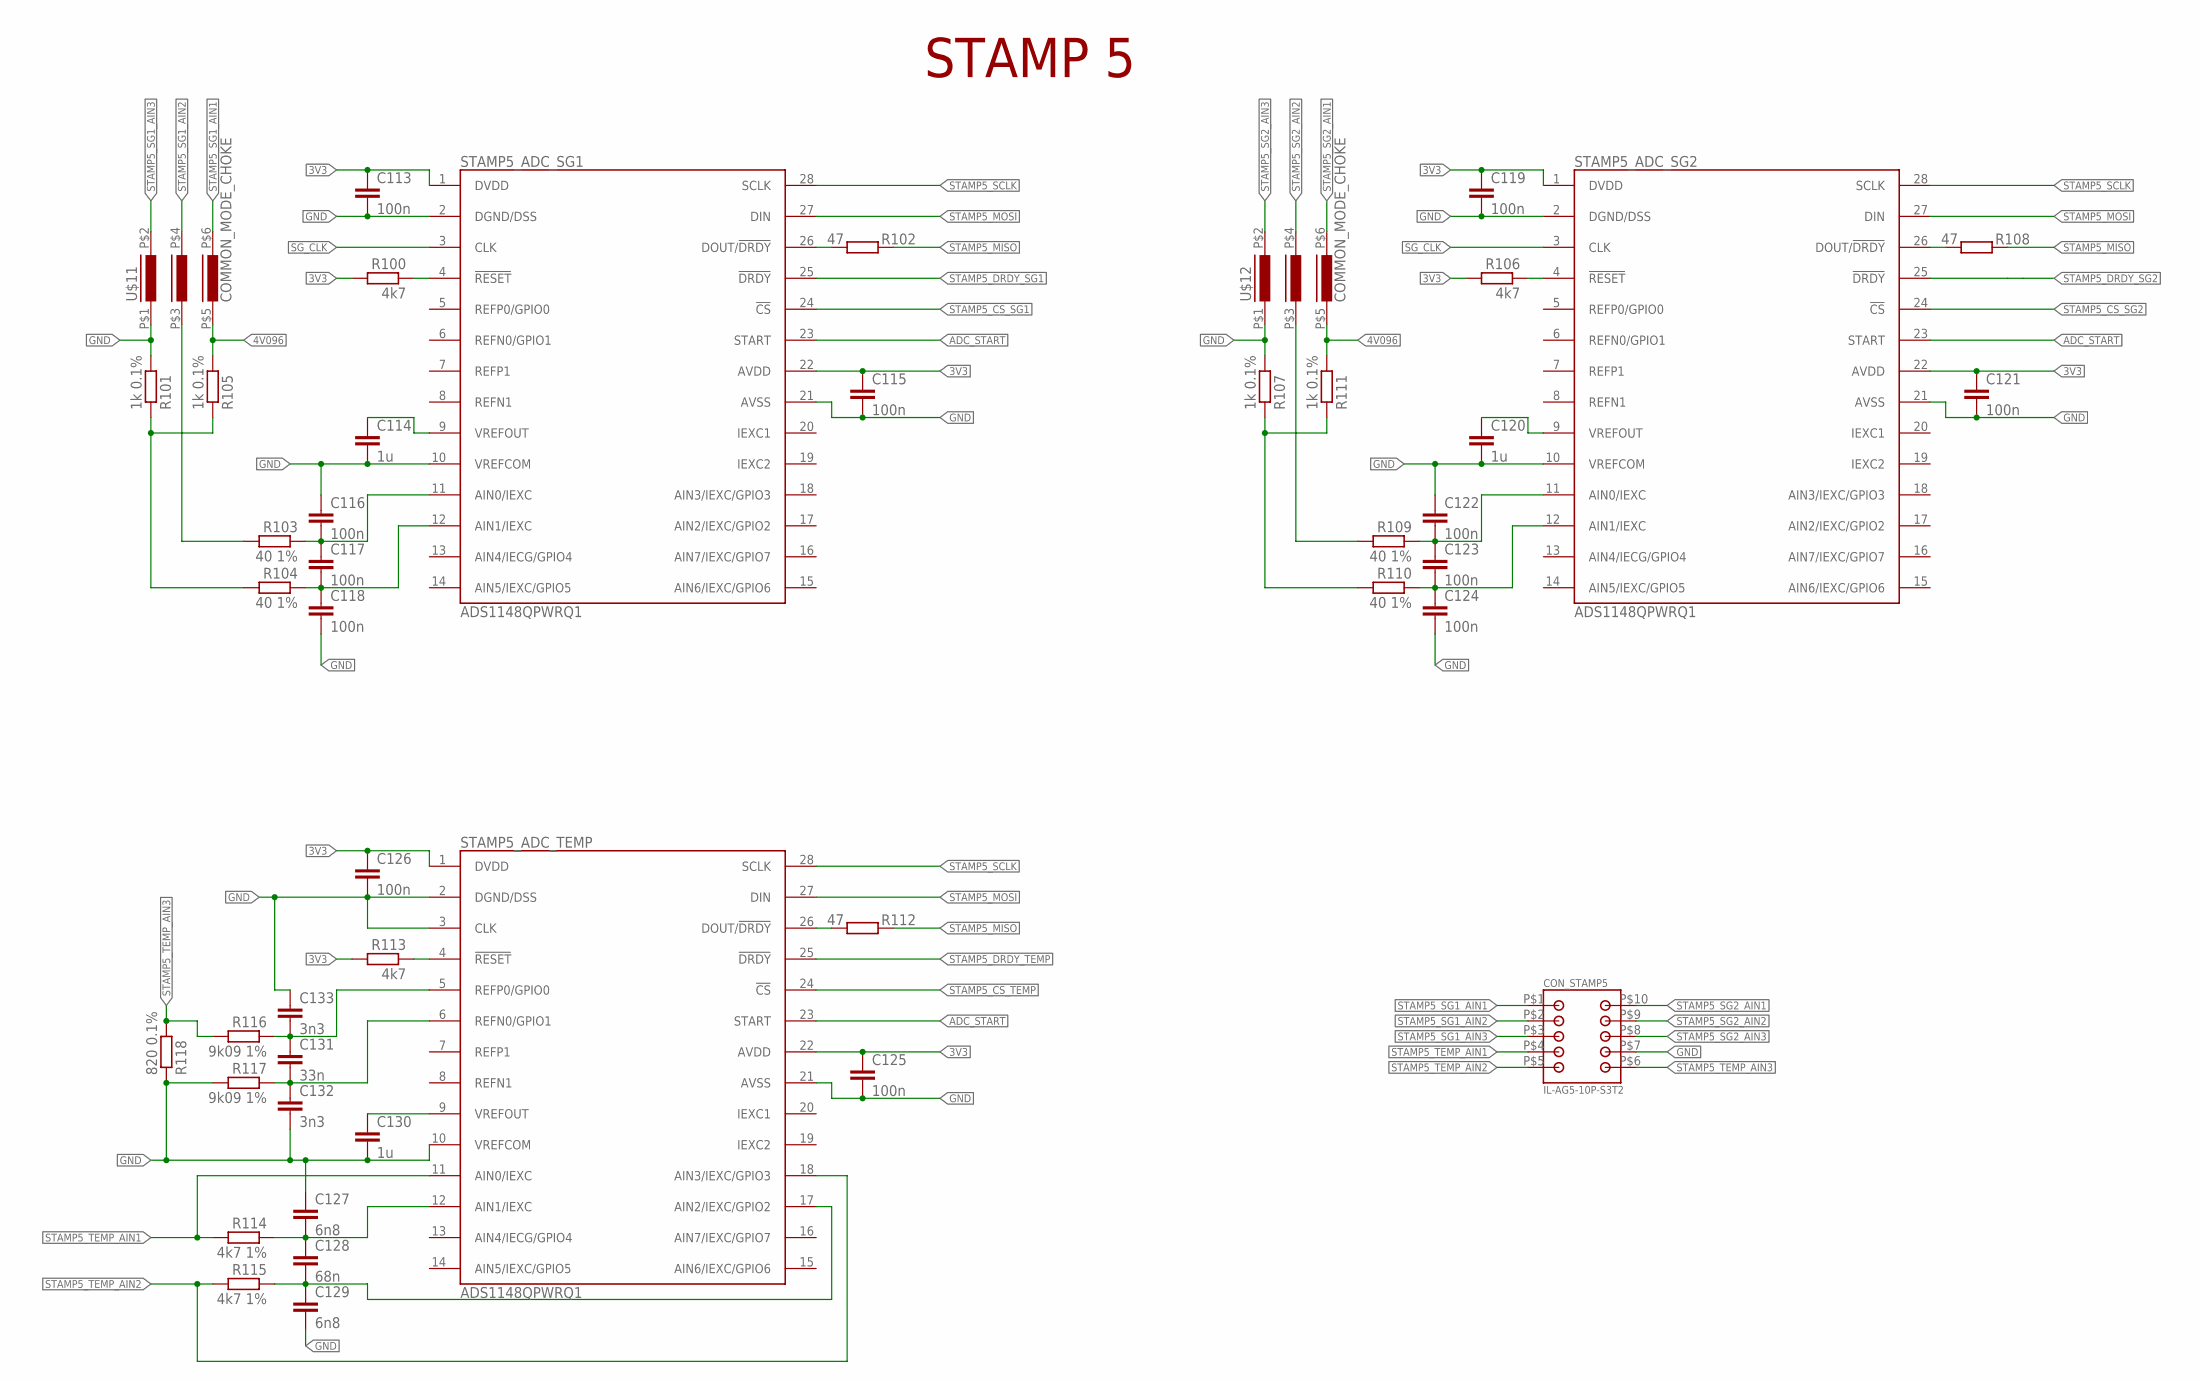
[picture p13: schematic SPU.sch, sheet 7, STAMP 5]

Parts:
C113, C115, C116, C117, C118, C119, C121, C122, C123, C124, C125, C126: 100n; C0805
C114, C120, C130: 1u; C0805
C127, C129: 6n8; C0805
C128: 68n; C0805
C131: 33n; C0805
C132, C133: 3n3; C0805
CON_STAMP5: IL-AG5-10P-S3T2
R100, R106, R113: 4k7; R0805
R101, R105, R107, R111: 1k 0.1%; R0805
R102, R108, R112: 47; R0805
R103, R104, R109, R110: 40 1%; R0805
R114, R115: 4k7 1%; R0805
R116, R117: 9k09 1%; R0805
R118: 820 0.1%; R0805
STAMP5_ADC_SG1, STAMP5_ADC_SG2, STAMP5_ADC_TEMP: ADS1148QPWRQ1; TSSOP28
U$11, U$12: COMMON_MODE_CHOKE

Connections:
3V3: C113.1, C115.1, C119.1, C121.1, C125.1, C126.1, R100.2, R106.2, R113.2, STAMP5_ADC_SG1.1 (DVDD), STAMP5_ADC_SG1.22 (AVDD), STAMP5_ADC_SG2.1 (DVDD), STAMP5_ADC_SG2.22 (AVDD), STAMP5_ADC_TEMP.1 (DVDD), STAMP5_ADC_TEMP.22 (AVDD); also elsewhere on the board
4V096: R105.2, R111.2, U$11.P$5 (5), U$12.P$5 (5); also elsewhere on the board
ADC_START: STAMP5_ADC_SG1.23 (START), STAMP5_ADC_SG2.23 (START), STAMP5_ADC_TEMP.23 (START); also elsewhere on the board
GND: C113.2, C114.2, C115.2, C116.1, C118.2, C119.2, C120.2, C121.2, C122.1, C124.2, C125.2, C126.2, C127.1, C129.2, C130.2, C132.2, C133.1, CON_STAMP5.P$7, R101.2, R107.2, R117.2, R118.1, STAMP5_ADC_SG1.2 (DGND/DSS), STAMP5_ADC_SG1.10 (VREFCOM), STAMP5_ADC_SG1.21 (AVSS), STAMP5_ADC_SG2.2 (DGND/DSS), STAMP5_ADC_SG2.10 (VREFCOM), STAMP5_ADC_SG2.21 (AVSS), STAMP5_ADC_TEMP.2 (DGND/DSS), STAMP5_ADC_TEMP.3 (CLK), STAMP5_ADC_TEMP.10 (VREFCOM), STAMP5_ADC_TEMP.21 (AVSS), U$11.P$1 (1), U$12.P$1 (1); also elsewhere on the board
unnamed: R100.1, STAMP5_ADC_SG1.4 (!RESET)
unnamed: C114.1, STAMP5_ADC_SG1.9 (VREFOUT)
unnamed: R102.2, STAMP5_ADC_SG1.26 (DOUT/!DRDY)
unnamed: C116.2, C117.1, R103.1, STAMP5_ADC_SG1.11 (AIN0/IEXC)
unnamed: C117.2, C118.1, R104.1, STAMP5_ADC_SG1.12 (AIN1/IEXC)
unnamed: R101.1, R104.2, R105.1
unnamed: R103.2, U$11.P$3 (3)
unnamed: R106.1, STAMP5_ADC_SG2.4 (!RESET)
unnamed: C120.1, STAMP5_ADC_SG2.9 (VREFOUT)
unnamed: R108.2, STAMP5_ADC_SG2.26 (DOUT/!DRDY)
unnamed: C122.2, C123.1, R109.1, STAMP5_ADC_SG2.11 (AIN0/IEXC)
unnamed: C123.2, C124.1, R110.1, STAMP5_ADC_SG2.12 (AIN1/IEXC)
unnamed: R107.1, R110.2, R111.1
unnamed: R109.2, U$12.P$3 (3)
unnamed: R112.2, STAMP5_ADC_TEMP.26 (DOUT/!DRDY)
unnamed: R113.1, STAMP5_ADC_TEMP.4 (!RESET)
unnamed: C127.2, C128.1, R114.1, STAMP5_ADC_TEMP.12 (AIN1/IEXC)
unnamed: C128.2, C129.1, R115.1, STAMP5_ADC_TEMP.17 (AIN2/IEXC/GPIO2)
unnamed: C130.1, STAMP5_ADC_TEMP.9 (VREFOUT)
unnamed: C131.2, C132.1, R117.1, STAMP5_ADC_TEMP.6 (REFN0/GPIO1)
unnamed: C131.1, C133.2, R116.1, STAMP5_ADC_TEMP.5 (REFP0/GPIO0)
SG_CLK: STAMP5_ADC_SG1.3 (CLK), STAMP5_ADC_SG2.3 (CLK); also elsewhere on the board
STAMP5_CS_SG1: STAMP5_ADC_SG1.24 (!CS); also elsewhere on the board
STAMP5_CS_SG2: STAMP5_ADC_SG2.24 (!CS); also elsewhere on the board
STAMP5_CS_TEMP: STAMP5_ADC_TEMP.24 (!CS); also elsewhere on the board
STAMP5_DRDY_SG1: STAMP5_ADC_SG1.25 (!DRDY); also elsewhere on the board
STAMP5_DRDY_SG2: STAMP5_ADC_SG2.25 (!DRDY); also elsewhere on the board
STAMP5_DRDY_TEMP: STAMP5_ADC_TEMP.25 (!DRDY); also elsewhere on the board
STAMP5_MISO: R102.1, R108.1, R112.1; also elsewhere on the board
STAMP5_MOSI: STAMP5_ADC_SG1.27 (DIN), STAMP5_ADC_SG2.27 (DIN), STAMP5_ADC_TEMP.27 (DIN); also elsewhere on the board
STAMP5_SCLK: STAMP5_ADC_SG1.28 (SCLK), STAMP5_ADC_SG2.28 (SCLK), STAMP5_ADC_TEMP.28 (SCLK); also elsewhere on the board
STAMP5_SG1_AIN1: CON_STAMP5.P$1, U$11.P$6 (6)
STAMP5_SG1_AIN2: CON_STAMP5.P$2, U$11.P$4 (4)
STAMP5_SG1_AIN3: CON_STAMP5.P$3, U$11.P$2 (2)
STAMP5_SG2_AIN1: CON_STAMP5.P$10, U$12.P$6 (6)
STAMP5_SG2_AIN2: CON_STAMP5.P$9, U$12.P$4 (4)
STAMP5_SG2_AIN3: CON_STAMP5.P$8, U$12.P$2 (2)
STAMP5_TEMP_AIN1: CON_STAMP5.P$4, R114.2, STAMP5_ADC_TEMP.11 (AIN0/IEXC)
STAMP5_TEMP_AIN2: CON_STAMP5.P$5, R115.2, STAMP5_ADC_TEMP.18 (AIN3/IEXC/GPIO3)
STAMP5_TEMP_AIN3: CON_STAMP5.P$6, R116.2, R118.2

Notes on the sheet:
STAMP 5

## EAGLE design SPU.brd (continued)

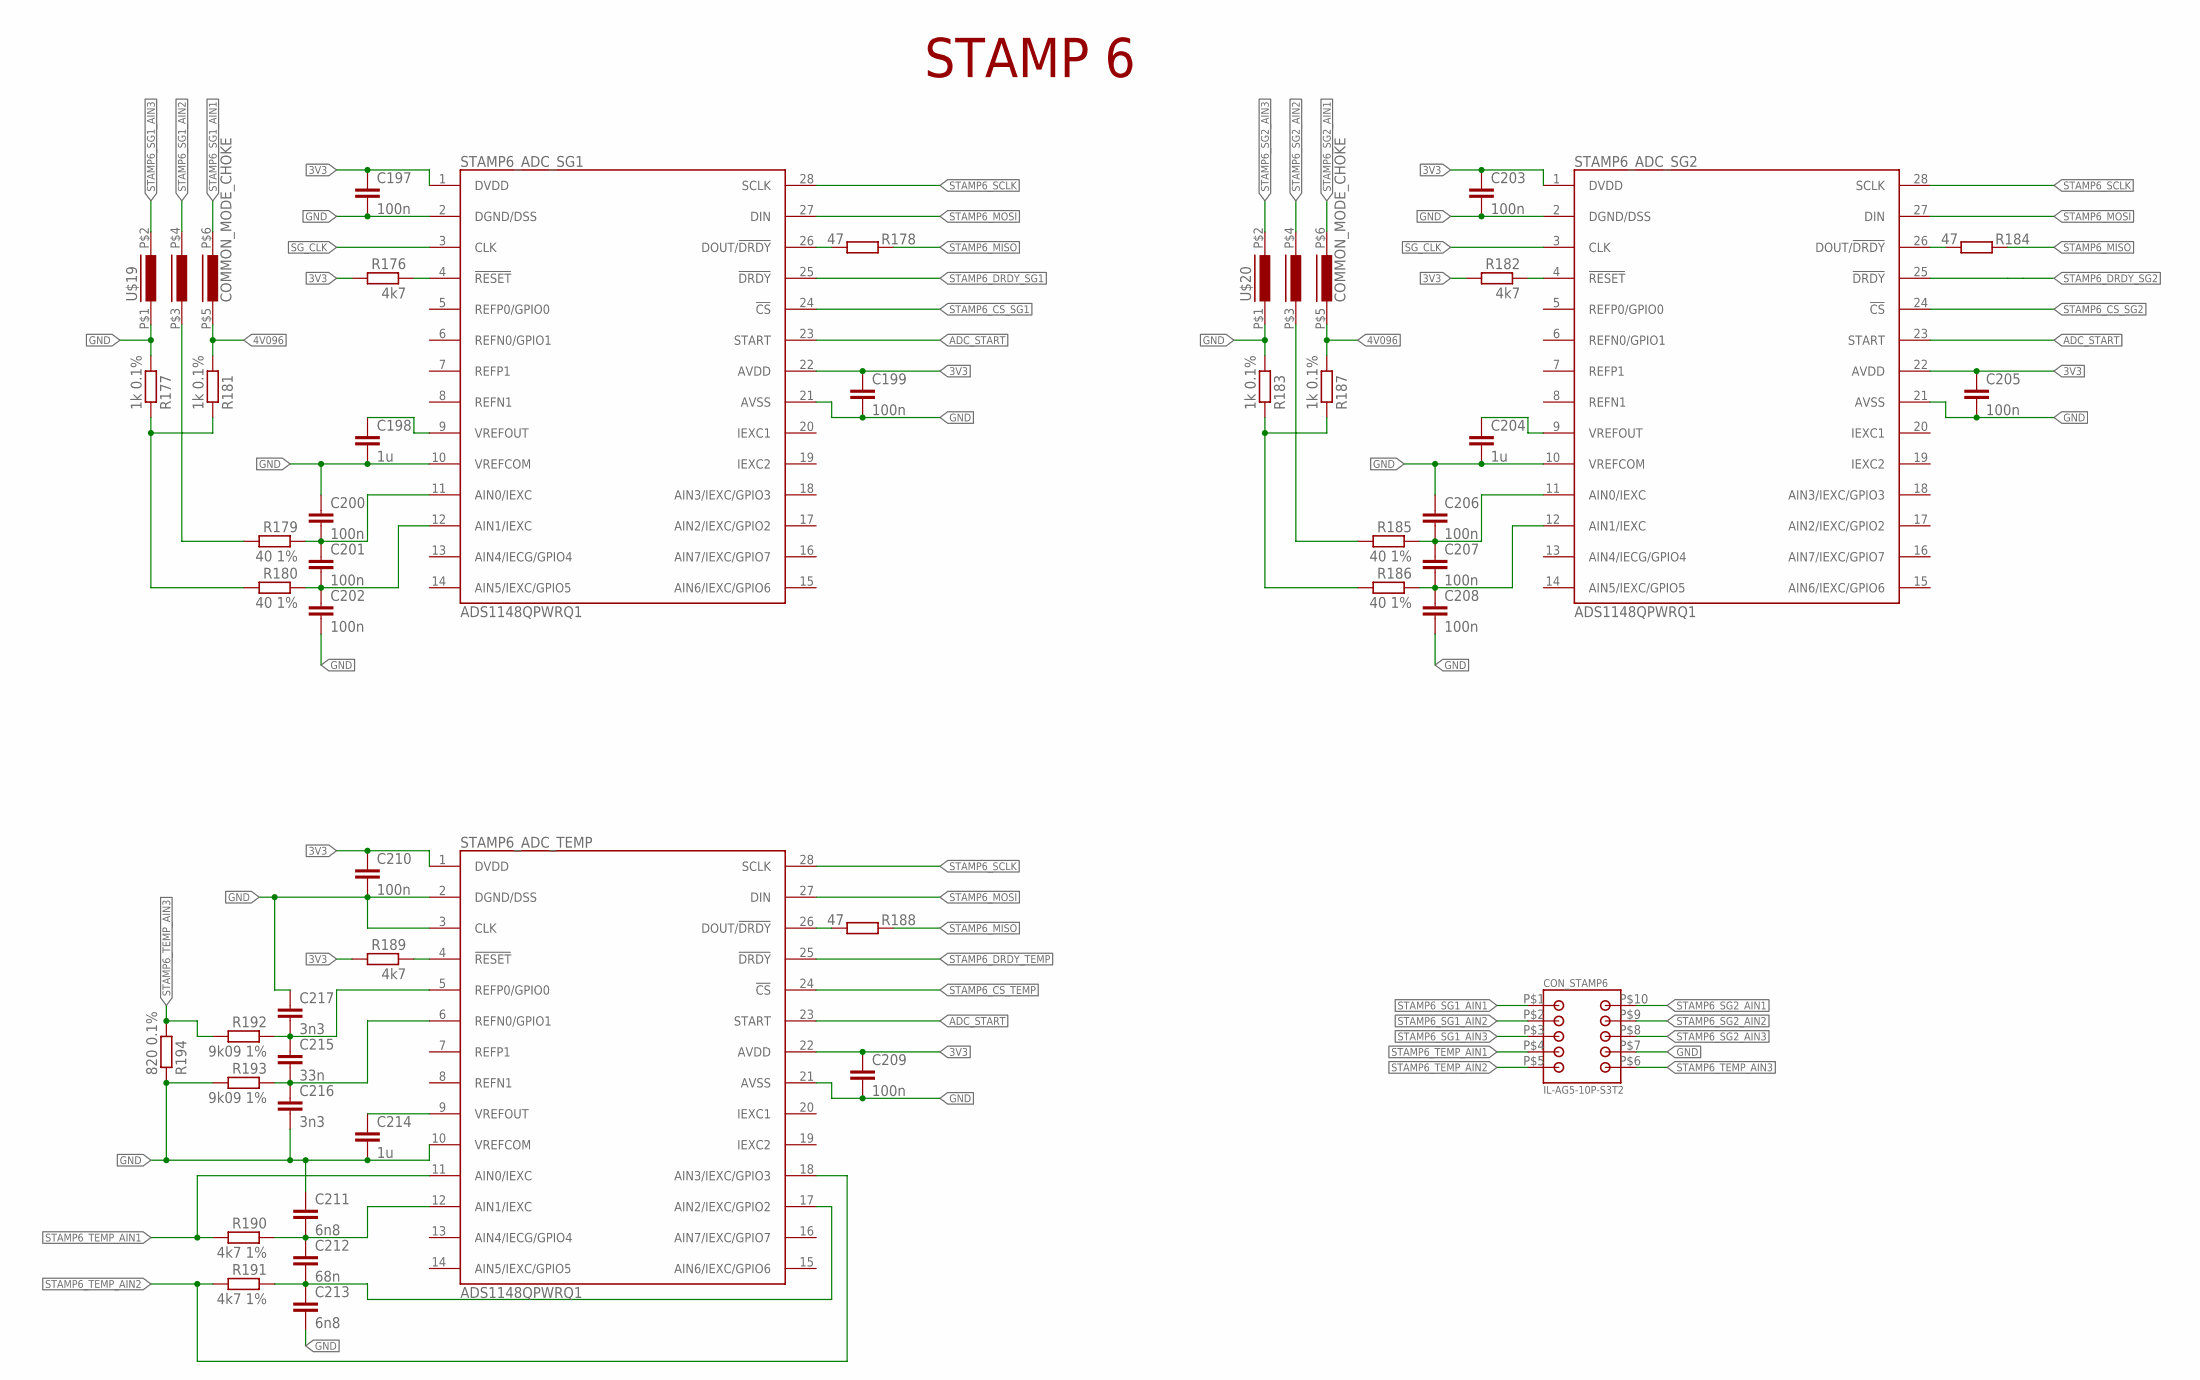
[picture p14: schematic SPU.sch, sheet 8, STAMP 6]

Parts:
C197, C199, C200, C201, C202, C203, C205, C206, C207, C208, C209, C210: 100n; C0805
C198, C204, C214: 1u; C0805
C211, C213: 6n8; C0805
C212: 68n; C0805
C215: 33n; C0805
C216, C217: 3n3; C0805
CON_STAMP6: IL-AG5-10P-S3T2
R176, R182, R189: 4k7; R0805
R177, R181, R183, R187: 1k 0.1%; R0805
R178, R184, R188: 47; R0805
R179, R180, R185, R186: 40 1%; R0805
R190, R191: 4k7 1%; R0805
R192, R193: 9k09 1%; R0805
R194: 820 0.1%; R0805
STAMP6_ADC_SG1, STAMP6_ADC_SG2, STAMP6_ADC_TEMP: ADS1148QPWRQ1; TSSOP28
U$19, U$20: COMMON_MODE_CHOKE

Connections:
3V3: C197.1, C199.1, C203.1, C205.1, C209.1, C210.1, R176.2, R182.2, R189.2, STAMP6_ADC_SG1.1 (DVDD), STAMP6_ADC_SG1.22 (AVDD), STAMP6_ADC_SG2.1 (DVDD), STAMP6_ADC_SG2.22 (AVDD), STAMP6_ADC_TEMP.1 (DVDD), STAMP6_ADC_TEMP.22 (AVDD); also elsewhere on the board
4V096: R181.2, R187.2, U$19.P$5 (5), U$20.P$5 (5); also elsewhere on the board
ADC_START: STAMP6_ADC_SG1.23 (START), STAMP6_ADC_SG2.23 (START), STAMP6_ADC_TEMP.23 (START); also elsewhere on the board
GND: C197.2, C198.2, C199.2, C200.1, C202.2, C203.2, C204.2, C205.2, C206.1, C208.2, C209.2, C210.2, C211.1, C213.2, C214.2, C216.2, C217.1, CON_STAMP6.P$7, R177.2, R183.2, R193.2, R194.1, STAMP6_ADC_SG1.2 (DGND/DSS), STAMP6_ADC_SG1.10 (VREFCOM), STAMP6_ADC_SG1.21 (AVSS), STAMP6_ADC_SG2.2 (DGND/DSS), STAMP6_ADC_SG2.10 (VREFCOM), STAMP6_ADC_SG2.21 (AVSS), STAMP6_ADC_TEMP.2 (DGND/DSS), STAMP6_ADC_TEMP.3 (CLK), STAMP6_ADC_TEMP.10 (VREFCOM), STAMP6_ADC_TEMP.21 (AVSS), U$19.P$1 (1), U$20.P$1 (1); also elsewhere on the board
unnamed: R176.1, STAMP6_ADC_SG1.4 (!RESET)
unnamed: C198.1, STAMP6_ADC_SG1.9 (VREFOUT)
unnamed: R178.2, STAMP6_ADC_SG1.26 (DOUT/!DRDY)
unnamed: C200.2, C201.1, R179.1, STAMP6_ADC_SG1.11 (AIN0/IEXC)
unnamed: C201.2, C202.1, R180.1, STAMP6_ADC_SG1.12 (AIN1/IEXC)
unnamed: R177.1, R180.2, R181.1
unnamed: R179.2, U$19.P$3 (3)
unnamed: R182.1, STAMP6_ADC_SG2.4 (!RESET)
unnamed: C204.1, STAMP6_ADC_SG2.9 (VREFOUT)
unnamed: R184.2, STAMP6_ADC_SG2.26 (DOUT/!DRDY)
unnamed: C206.2, C207.1, R185.1, STAMP6_ADC_SG2.11 (AIN0/IEXC)
unnamed: C207.2, C208.1, R186.1, STAMP6_ADC_SG2.12 (AIN1/IEXC)
unnamed: R183.1, R186.2, R187.1
unnamed: R185.2, U$20.P$3 (3)
unnamed: R188.2, STAMP6_ADC_TEMP.26 (DOUT/!DRDY)
unnamed: R189.1, STAMP6_ADC_TEMP.4 (!RESET)
unnamed: C211.2, C212.1, R190.1, STAMP6_ADC_TEMP.12 (AIN1/IEXC)
unnamed: C212.2, C213.1, R191.1, STAMP6_ADC_TEMP.17 (AIN2/IEXC/GPIO2)
unnamed: C214.1, STAMP6_ADC_TEMP.9 (VREFOUT)
unnamed: C215.2, C216.1, R193.1, STAMP6_ADC_TEMP.6 (REFN0/GPIO1)
unnamed: C215.1, C217.2, R192.1, STAMP6_ADC_TEMP.5 (REFP0/GPIO0)
SG_CLK: STAMP6_ADC_SG1.3 (CLK), STAMP6_ADC_SG2.3 (CLK); also elsewhere on the board
STAMP6_CS_SG1: STAMP6_ADC_SG1.24 (!CS); also elsewhere on the board
STAMP6_CS_SG2: STAMP6_ADC_SG2.24 (!CS); also elsewhere on the board
STAMP6_CS_TEMP: STAMP6_ADC_TEMP.24 (!CS); also elsewhere on the board
STAMP6_DRDY_SG1: STAMP6_ADC_SG1.25 (!DRDY); also elsewhere on the board
STAMP6_DRDY_SG2: STAMP6_ADC_SG2.25 (!DRDY); also elsewhere on the board
STAMP6_DRDY_TEMP: STAMP6_ADC_TEMP.25 (!DRDY); also elsewhere on the board
STAMP6_MISO: R178.1, R184.1, R188.1; also elsewhere on the board
STAMP6_MOSI: STAMP6_ADC_SG1.27 (DIN), STAMP6_ADC_SG2.27 (DIN), STAMP6_ADC_TEMP.27 (DIN); also elsewhere on the board
STAMP6_SCLK: STAMP6_ADC_SG1.28 (SCLK), STAMP6_ADC_SG2.28 (SCLK), STAMP6_ADC_TEMP.28 (SCLK); also elsewhere on the board
STAMP6_SG1_AIN1: CON_STAMP6.P$1, U$19.P$6 (6)
STAMP6_SG1_AIN2: CON_STAMP6.P$2, U$19.P$4 (4)
STAMP6_SG1_AIN3: CON_STAMP6.P$3, U$19.P$2 (2)
STAMP6_SG2_AIN1: CON_STAMP6.P$10, U$20.P$6 (6)
STAMP6_SG2_AIN2: CON_STAMP6.P$9, U$20.P$4 (4)
STAMP6_SG2_AIN3: CON_STAMP6.P$8, U$20.P$2 (2)
STAMP6_TEMP_AIN1: CON_STAMP6.P$4, R190.2, STAMP6_ADC_TEMP.11 (AIN0/IEXC)
STAMP6_TEMP_AIN2: CON_STAMP6.P$5, R191.2, STAMP6_ADC_TEMP.18 (AIN3/IEXC/GPIO3)
STAMP6_TEMP_AIN3: CON_STAMP6.P$6, R192.2, R194.2

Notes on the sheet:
STAMP 6

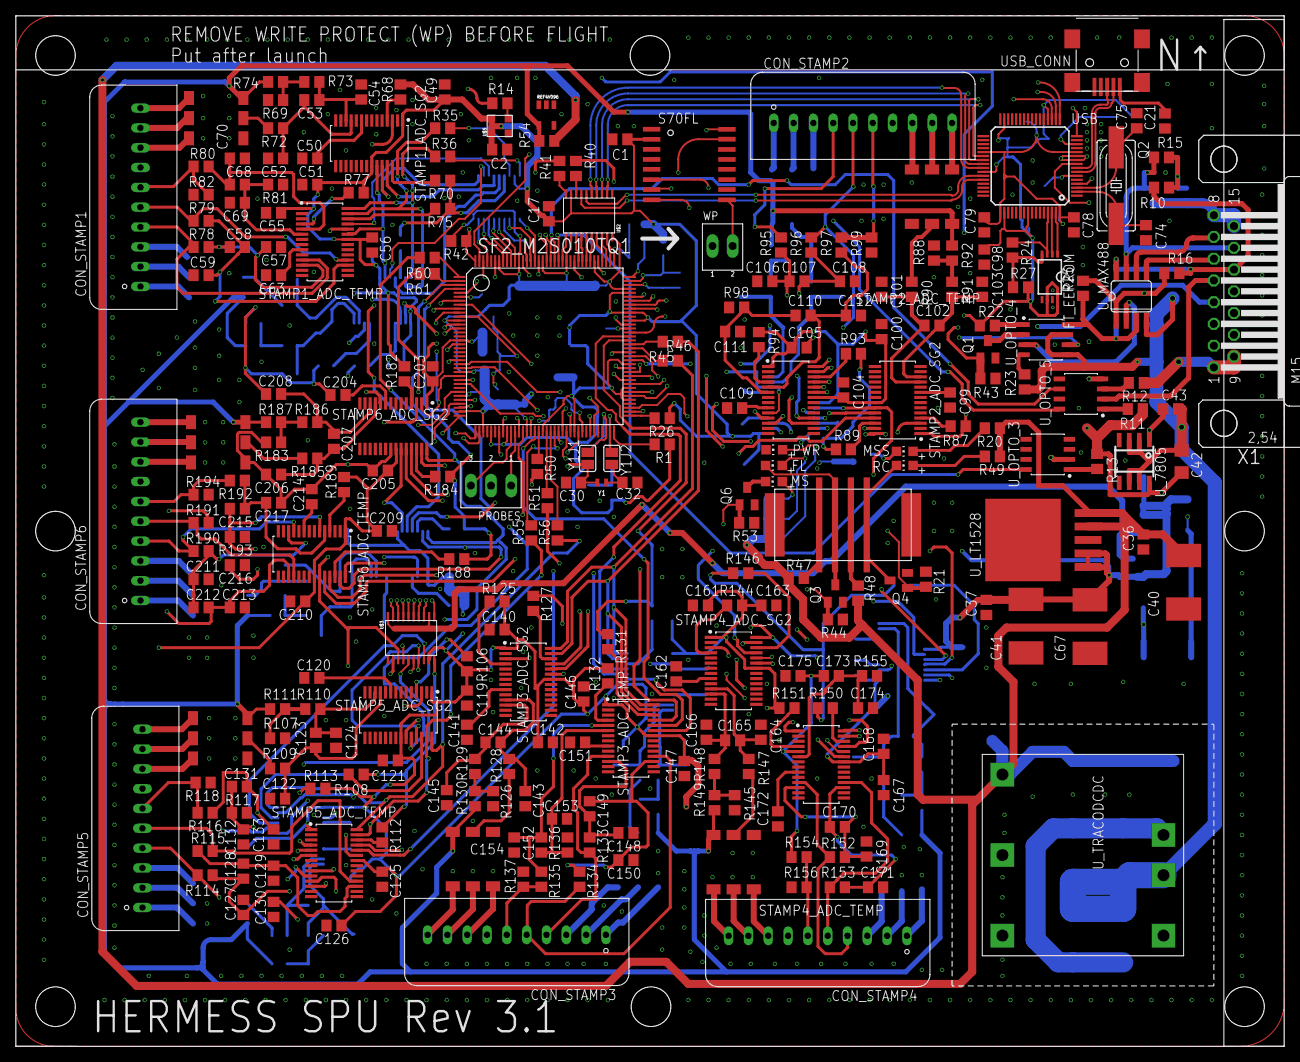
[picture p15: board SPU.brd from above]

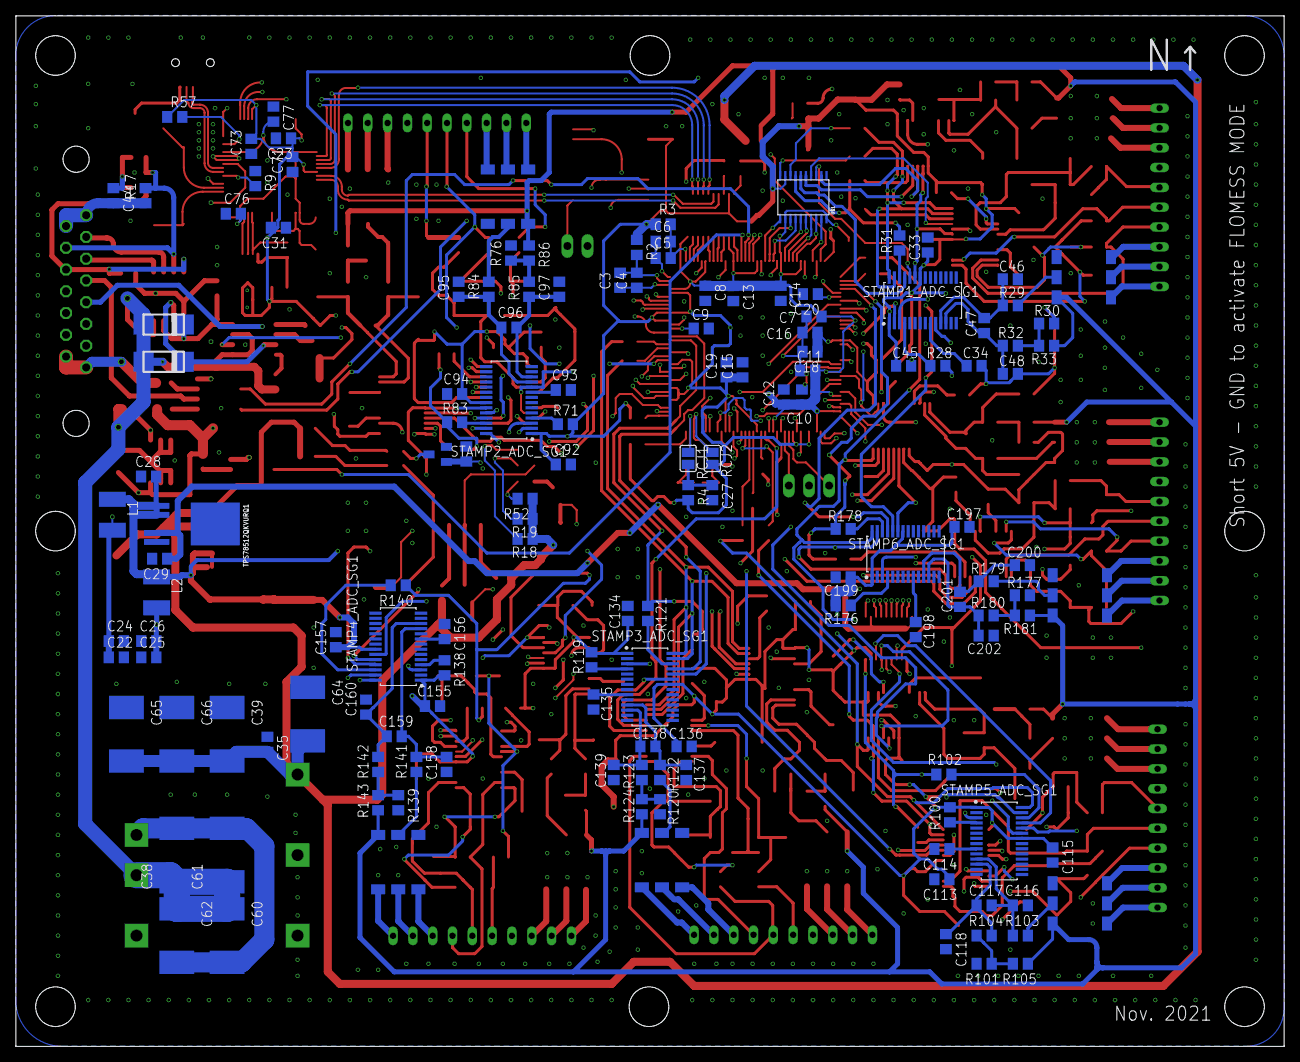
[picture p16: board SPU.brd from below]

Board: 4 copper layers, 160.0 x 130.0 mm, 421 parts (143 on the bottom side), 360 nets.

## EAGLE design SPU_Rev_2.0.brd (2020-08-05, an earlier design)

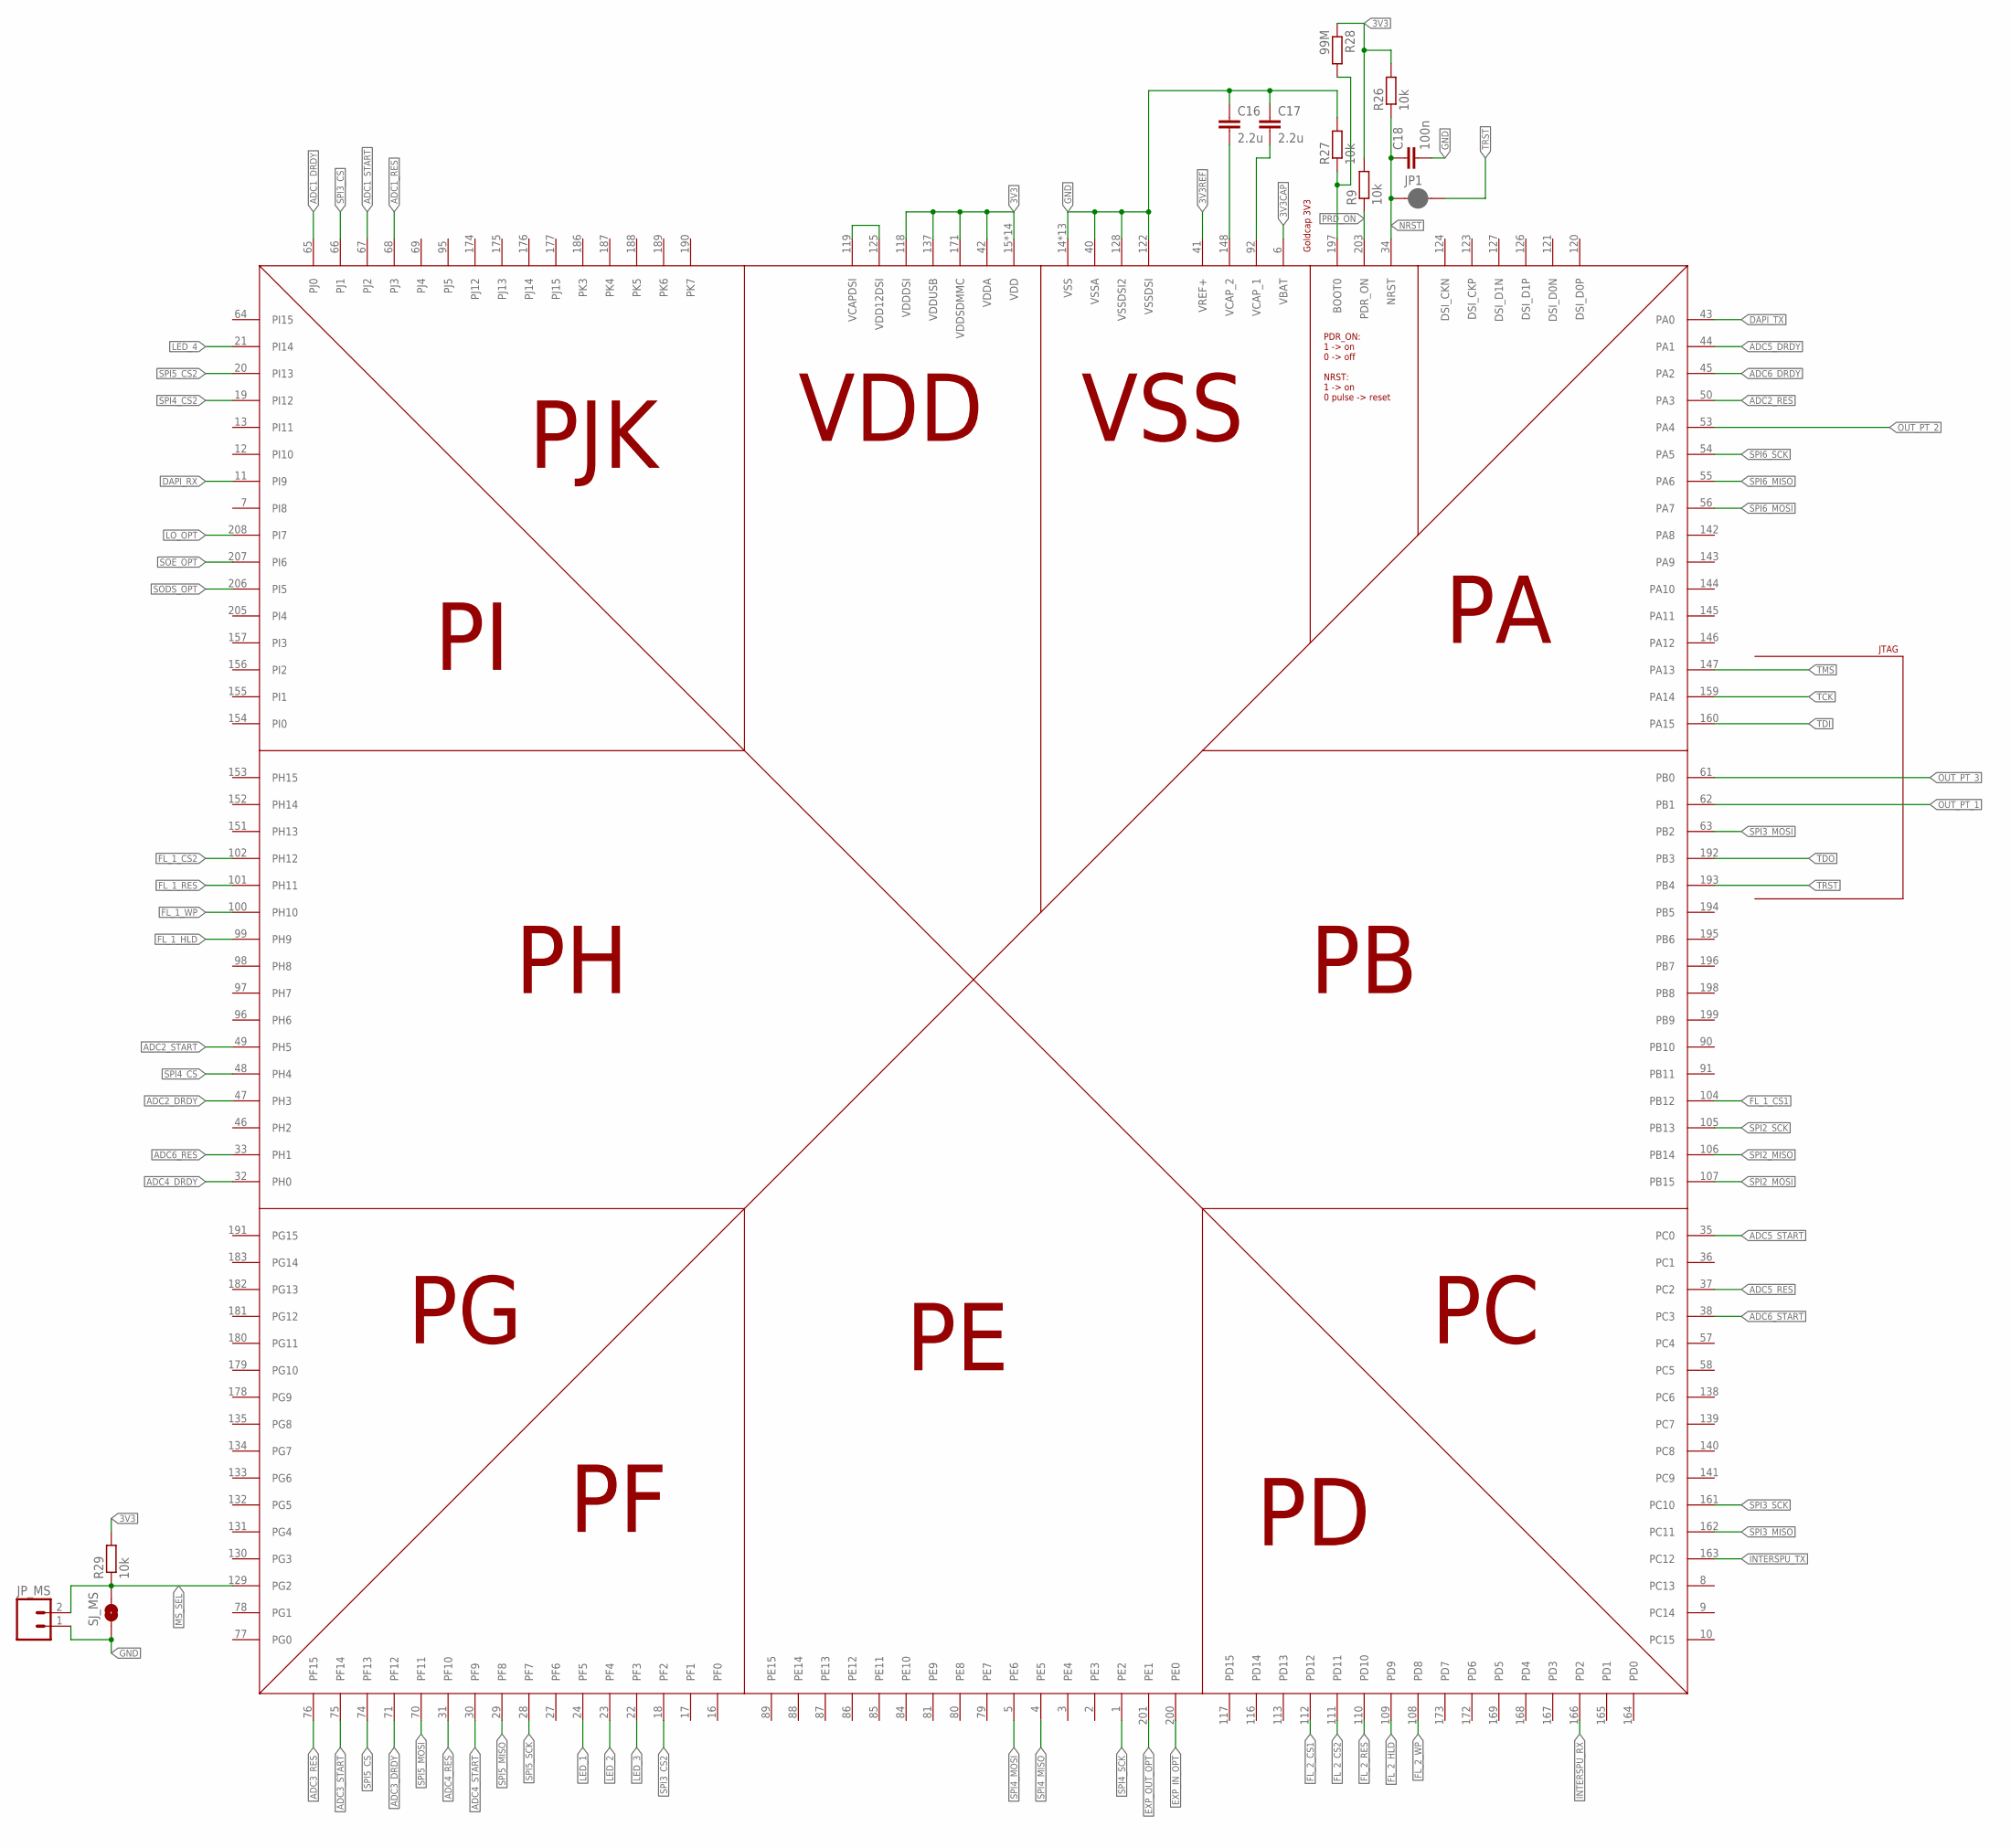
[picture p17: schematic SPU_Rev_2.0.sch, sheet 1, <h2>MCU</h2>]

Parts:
C16, C17: 2.2u; C1206
C18: 100n; 0603-CAP
JP1: JUMPER-SMT_2_NC_PASTE_SILK; SMT-JUMPER_2_NC_PASTE_SILK
JP_MS: M02PTH; 1X02
R9, R26, R27, R29: 10k; R0805
R28: 99M; R0805
SJ_MS: SOLDERJUMPERNO; SJ_2S-NO
U_STM32F779: STM32F77XXXLQFP208; QFP50P3060X3060X385-208

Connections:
3V3: R9.2, R26.2, R28.1, R29.2, U_STM32F779.15 (VDD), U_STM32F779.26 (VDD), U_STM32F779.39 (VDD), U_STM32F779.42 (VDDA), U_STM32F779.52 (VDD), U_STM32F779.59 (VDD), U_STM32F779.73 (VDD), U_STM32F779.83 (VDD), U_STM32F779.94 (VDD), U_STM32F779.103 (VDD), U_STM32F779.115 (VDD), U_STM32F779.118 (VDDDSI), U_STM32F779.137 (VDDUSB), U_STM32F779.150 (VDD), U_STM32F779.158 (VDD), U_STM32F779.171 (VDDSDMMC), U_STM32F779.185 (VDD), U_STM32F779.204 (VDD); also elsewhere on the board
3V3CAP: U_STM32F779.6 (VBAT)
3V3REF: U_STM32F779.41 (VREF+); also elsewhere on the board
ADC1_DRDY: U_STM32F779.65 (PJ0)
ADC1_RES: U_STM32F779.68 (PJ3)
ADC1_START: U_STM32F779.67 (PJ2)
ADC2_DRDY: U_STM32F779.47 (PH3)
ADC2_RES: U_STM32F779.50 (PA3)
ADC2_START: U_STM32F779.49 (PH5)
ADC3_DRDY: U_STM32F779.71 (PF12)
ADC3_RES: U_STM32F779.76 (PF15)
ADC3_START: U_STM32F779.75 (PF14)
ADC4_DRDY: U_STM32F779.32 (PH0)
ADC4_RES: U_STM32F779.31 (PF10)
ADC4_START: U_STM32F779.30 (PF9)
ADC5_DRDY: U_STM32F779.44 (PA1)
ADC5_RES: U_STM32F779.37 (PC2)
ADC5_START: U_STM32F779.35 (PC0)
ADC6_DRDY: U_STM32F779.45 (PA2)
ADC6_RES: U_STM32F779.33 (PH1)
ADC6_START: U_STM32F779.38 (PC3)
DAPI_RX: U_STM32F779.11 (PI9); also elsewhere on the board
DAPI_TX: U_STM32F779.43 (PA0); also elsewhere on the board
EXP_IN_OPT: U_STM32F779.200 (PE0); also elsewhere on the board
EXP_OUT_OPT: U_STM32F779.201 (PE1); also elsewhere on the board
FL_1_CS1: U_STM32F779.104 (PB12); also elsewhere on the board
FL_1_CS2: U_STM32F779.102 (PH12); also elsewhere on the board
FL_1_HLD: U_STM32F779.99 (PH9); also elsewhere on the board
FL_1_RES: U_STM32F779.101 (PH11); also elsewhere on the board
FL_1_WP: U_STM32F779.100 (PH10); also elsewhere on the board
FL_2_CS1: U_STM32F779.112 (PD12); also elsewhere on the board
FL_2_CS2: U_STM32F779.111 (PD11); also elsewhere on the board
FL_2_HLD: U_STM32F779.109 (PD9); also elsewhere on the board
FL_2_RES: U_STM32F779.110 (PD10); also elsewhere on the board
FL_2_WP: U_STM32F779.108 (PD8); also elsewhere on the board
GND: C16.1, C17.1, C18.2, JP_MS.1, R27.2, SJ_MS.1, U_STM32F779.14 (VSS), U_STM32F779.25 (VSS), U_STM32F779.40 (VSSA), U_STM32F779.51 (VSS), U_STM32F779.60 (VSS), U_STM32F779.72 (VSS), U_STM32F779.82 (VSS), U_STM32F779.93 (VSS), U_STM32F779.114 (VSS), U_STM32F779.122 (VSSDSI), U_STM32F779.128 (VSSDSI2), U_STM32F779.136 (VSS), U_STM32F779.149 (VSS), U_STM32F779.170 (VSS), U_STM32F779.184 (VSS), U_STM32F779.202 (VSS); also elsewhere on the board
INTERSPU_RX: U_STM32F779.166 (PD2); also elsewhere on the board
INTERSPU_TX: U_STM32F779.163 (PC12); also elsewhere on the board
LED_1: U_STM32F779.24 (PF5); also elsewhere on the board
LED_2: U_STM32F779.23 (PF4); also elsewhere on the board
LED_3: U_STM32F779.22 (PF3); also elsewhere on the board
LED_4: U_STM32F779.21 (PI14); also elsewhere on the board
LO_OPT: U_STM32F779.208 (PI7); also elsewhere on the board
MS_SEL: JP_MS.2, R29.1, SJ_MS.2, U_STM32F779.129 (PG2)
unnamed: C16.2, U_STM32F779.148 (VCAP_2)
unnamed: C17.2, U_STM32F779.92 (VCAP_1)
unnamed: U_STM32F779.119 (VCAPDSI), U_STM32F779.125 (VDD12DSI)
unnamed: R27.1, R28.2, U_STM32F779.197 (BOOT0)
NRST: C18.1, JP1.1, R26.1, U_STM32F779.34 (NRST); also elsewhere on the board
OUT_PT_1: U_STM32F779.62 (PB1)
OUT_PT_2: U_STM32F779.53 (PA4)
OUT_PT_3: U_STM32F779.61 (PB0)
PRD_ON: R9.1, U_STM32F779.203 (PDR_ON)
SODS_OPT: U_STM32F779.206 (PI5); also elsewhere on the board
SOE_OPT: U_STM32F779.207 (PI6); also elsewhere on the board
SPI2_MISO: U_STM32F779.106 (PB14); also elsewhere on the board
SPI2_MOSI: U_STM32F779.107 (PB15); also elsewhere on the board
SPI2_SCK: U_STM32F779.105 (PB13); also elsewhere on the board
SPI3_CS: U_STM32F779.66 (PJ1)
SPI3_CS2: U_STM32F779.18 (PF2)
SPI3_MISO: U_STM32F779.162 (PC11)
SPI3_MOSI: U_STM32F779.63 (PB2)
SPI3_SCK: U_STM32F779.161 (PC10)
SPI4_CS: U_STM32F779.48 (PH4)
SPI4_CS2: U_STM32F779.19 (PI12)
SPI4_MISO: U_STM32F779.4 (PE5)
SPI4_MOSI: U_STM32F779.5 (PE6)
SPI4_SCK: U_STM32F779.1 (PE2)
SPI5_CS: U_STM32F779.74 (PF13)
SPI5_CS2: U_STM32F779.20 (PI13)
SPI5_MISO: U_STM32F779.29 (PF8)
SPI5_MOSI: U_STM32F779.70 (PF11)
SPI5_SCK: U_STM32F779.28 (PF7)
SPI6_MISO: U_STM32F779.55 (PA6); also elsewhere on the board
SPI6_MOSI: U_STM32F779.56 (PA7); also elsewhere on the board
SPI6_SCK: U_STM32F779.54 (PA5); also elsewhere on the board
TCK: U_STM32F779.159 (PA14); also elsewhere on the board
TDI: U_STM32F779.160 (PA15); also elsewhere on the board
TDO: U_STM32F779.192 (PB3); also elsewhere on the board
TMS: U_STM32F779.147 (PA13); also elsewhere on the board
TRST: JP1.2, U_STM32F779.193 (PB4); also elsewhere on the board

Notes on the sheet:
JTAG
Goldcap 3V3
PDR_ON: 1 -> on 0 -> off NRST: 1 -> on 0 pulse -> reset

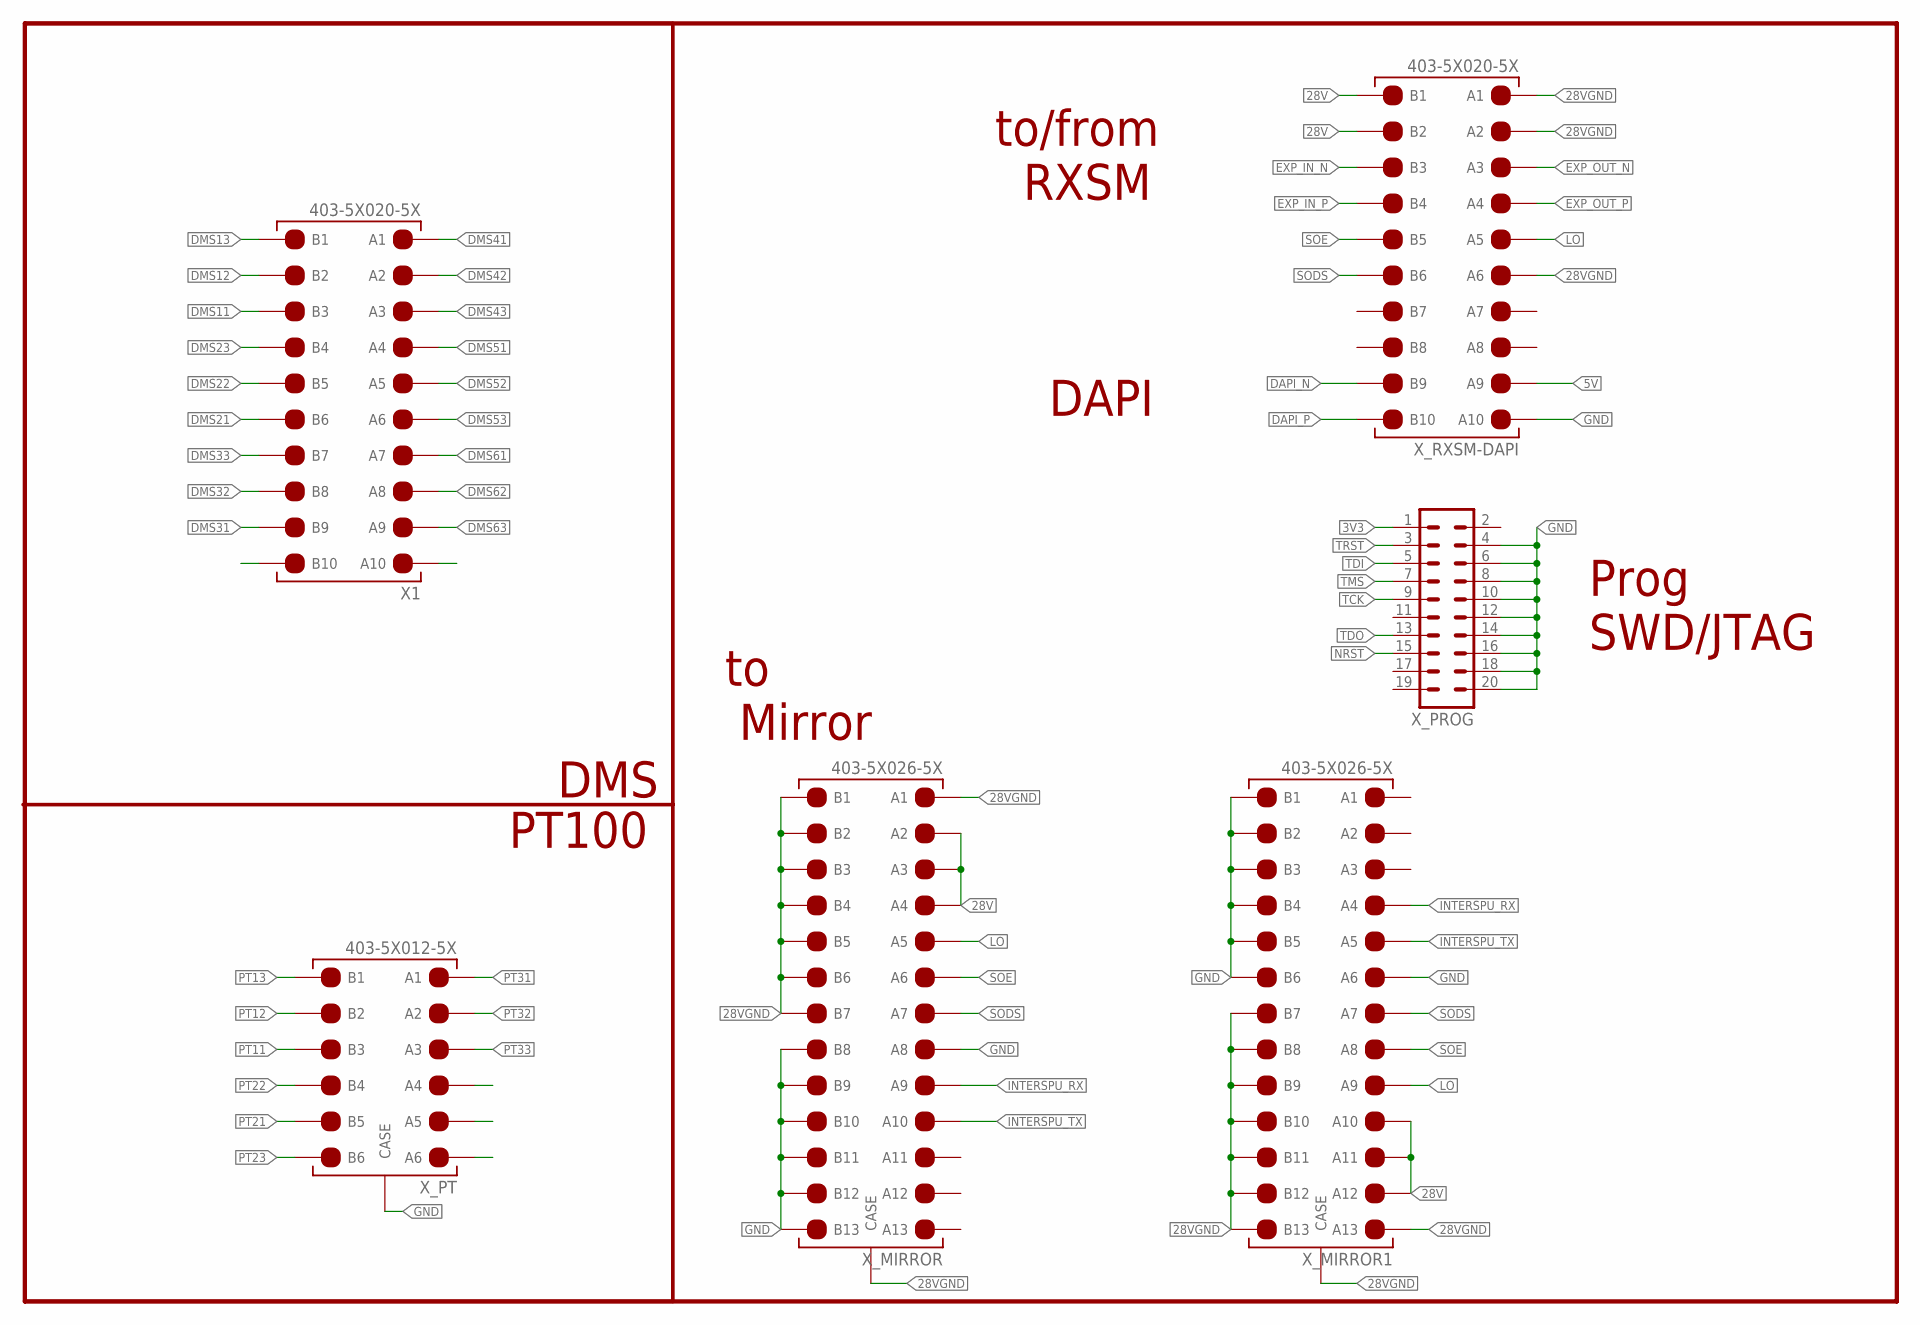
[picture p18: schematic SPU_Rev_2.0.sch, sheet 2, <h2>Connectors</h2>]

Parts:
X1: 403-5X020-5X
X_MIRROR, X_MIRROR1: 403-5X026-5X
X_PROG: MA10-2
X_PT: 403-5X012-5X
X_RXSM-DAPI: 403-5X020-5X

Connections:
3V3: X_PROG.1; also elsewhere on the board
5V: X_RXSM-DAPI.P$A9 (A9); also elsewhere on the board
28V: X_MIRROR.P$A2 (A2), X_MIRROR.P$A3 (A3), X_MIRROR.P$A4 (A4), X_MIRROR1.P$A10 (A10), X_MIRROR1.P$A11 (A11), X_MIRROR1.P$A12 (A12), X_RXSM-DAPI.P$B1 (B1), X_RXSM-DAPI.P$B2 (B2); also elsewhere on the board
28VGND: X_MIRROR.P$A1 (A1), X_MIRROR.P$B1 (B1), X_MIRROR.P$B2 (B2), X_MIRROR.P$B3 (B3), X_MIRROR.P$B4 (B4), X_MIRROR.P$B5 (B5), X_MIRROR.P$B6 (B6), X_MIRROR.P$B7 (B7), X_MIRROR.P$BL1 (CASE), X_MIRROR.P$BL2 (CASE), X_MIRROR.P$BL3 (CASE), X_MIRROR.P$BL4 (CASE), X_MIRROR1.P$A13 (A13), X_MIRROR1.P$B7 (B7), X_MIRROR1.P$B8 (B8), X_MIRROR1.P$B9 (B9), X_MIRROR1.P$B10 (B10), X_MIRROR1.P$B11 (B11), X_MIRROR1.P$B12 (B12), X_MIRROR1.P$B13 (B13), X_MIRROR1.P$BL1 (CASE), X_MIRROR1.P$BL2 (CASE), X_MIRROR1.P$BL3 (CASE), X_MIRROR1.P$BL4 (CASE), X_RXSM-DAPI.P$A1 (A1), X_RXSM-DAPI.P$A2 (A2), X_RXSM-DAPI.P$A6 (A6); also elsewhere on the board
DAPI_N: X_RXSM-DAPI.P$B9 (B9); also elsewhere on the board
DAPI_P: X_RXSM-DAPI.P$B10 (B10); also elsewhere on the board
DMS11: X1.P$B3 (B3); also elsewhere on the board
DMS12: X1.P$B2 (B2); also elsewhere on the board
DMS13: X1.P$B1 (B1); also elsewhere on the board
DMS21: X1.P$B6 (B6); also elsewhere on the board
DMS22: X1.P$B5 (B5); also elsewhere on the board
DMS23: X1.P$B4 (B4); also elsewhere on the board
DMS31: X1.P$B9 (B9); also elsewhere on the board
DMS32: X1.P$B8 (B8); also elsewhere on the board
DMS33: X1.P$B7 (B7); also elsewhere on the board
DMS41: X1.P$A1 (A1); also elsewhere on the board
DMS42: X1.P$A2 (A2); also elsewhere on the board
DMS43: X1.P$A3 (A3); also elsewhere on the board
DMS51: X1.P$A4 (A4); also elsewhere on the board
DMS52: X1.P$A5 (A5); also elsewhere on the board
DMS53: X1.P$A6 (A6); also elsewhere on the board
DMS61: X1.P$A7 (A7); also elsewhere on the board
DMS62: X1.P$A8 (A8); also elsewhere on the board
DMS63: X1.P$A9 (A9); also elsewhere on the board
EXP_IN_N: X_RXSM-DAPI.P$B3 (B3); also elsewhere on the board
EXP_IN_P: X_RXSM-DAPI.P$B4 (B4); also elsewhere on the board
EXP_OUT_N: X_RXSM-DAPI.P$A3 (A3); also elsewhere on the board
EXP_OUT_P: X_RXSM-DAPI.P$A4 (A4); also elsewhere on the board
GND: X_MIRROR.P$A8 (A8), X_MIRROR.P$B8 (B8), X_MIRROR.P$B9 (B9), X_MIRROR.P$B10 (B10), X_MIRROR.P$B11 (B11), X_MIRROR.P$B12 (B12), X_MIRROR.P$B13 (B13), X_MIRROR1.P$A6 (A6), X_MIRROR1.P$B1 (B1), X_MIRROR1.P$B2 (B2), X_MIRROR1.P$B3 (B3), X_MIRROR1.P$B4 (B4), X_MIRROR1.P$B5 (B5), X_MIRROR1.P$B6 (B6), X_PROG.4, X_PROG.6, X_PROG.8, X_PROG.10, X_PROG.12, X_PROG.14, X_PROG.16, X_PROG.18, X_PROG.20, X_PT.P$BL1 (CASE), X_PT.P$BL2 (CASE), X_PT.P$BL3 (CASE), X_PT.P$BL4 (CASE), X_RXSM-DAPI.P$A10 (A10); also elsewhere on the board
INTERSPU_RX: X_MIRROR.P$A9 (A9), X_MIRROR1.P$A4 (A4); also elsewhere on the board
INTERSPU_TX: X_MIRROR.P$A10 (A10), X_MIRROR1.P$A5 (A5); also elsewhere on the board
LO: X_MIRROR.P$A5 (A5), X_MIRROR1.P$A9 (A9), X_RXSM-DAPI.P$A5 (A5); also elsewhere on the board
NRST: X_PROG.15; also elsewhere on the board
PT11: X_PT.P$B3 (B3); also elsewhere on the board
PT12: X_PT.P$B2 (B2); also elsewhere on the board
PT13: X_PT.P$B1 (B1); also elsewhere on the board
PT21: X_PT.P$B5 (B5); also elsewhere on the board
PT22: X_PT.P$B4 (B4); also elsewhere on the board
PT23: X_PT.P$B6 (B6); also elsewhere on the board
PT31: X_PT.P$A1 (A1); also elsewhere on the board
PT32: X_PT.P$A2 (A2); also elsewhere on the board
PT33: X_PT.P$A3 (A3); also elsewhere on the board
SODS: X_MIRROR.P$A7 (A7), X_MIRROR1.P$A7 (A7), X_RXSM-DAPI.P$B6 (B6); also elsewhere on the board
SOE: X_MIRROR.P$A6 (A6), X_MIRROR1.P$A8 (A8), X_RXSM-DAPI.P$B5 (B5); also elsewhere on the board
TCK: X_PROG.9; also elsewhere on the board
TDI: X_PROG.5; also elsewhere on the board
TDO: X_PROG.13; also elsewhere on the board
TMS: X_PROG.7; also elsewhere on the board
TRST: X_PROG.3; also elsewhere on the board

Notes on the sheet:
DMS
PT100
DAPI
to/from RXSM
to Mirror
Prog SWD/JTAG

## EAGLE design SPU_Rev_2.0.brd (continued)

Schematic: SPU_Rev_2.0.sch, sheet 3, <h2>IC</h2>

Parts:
C1, C2: 22p; C0603
C3, C5, C6, C7, C8, C9, C10, C12, C13, C14, C15, C19, C21, C22, C23, C24, C25, C27, C45, C46, C47, C48, C50, C51, C53, C54, C55, C57, C58, C59: 100n; C0603
C4, C11, C20, C26, C49, C56: 1u; C1206
C28, C29, C30, C31, C32, C33, C34, C35, C36, C37, C42, C43: 100n; C0805
C38, C39, C40, C41: 10u; E/7260-38W
C44: ~0; C0805
C52: 10n; C0805
C_AVDD_PT1, C_AVDD_PT2, C_AVDD_PT3: 100n; C0603
C_DVDD_PT1, C_DVDD_PT2, C_DVDD_PT3: 100n; C0603
C_ICM1_PT1, C_ICM1_PT2, C_ICM1_PT3, C_ICM2_PT1, C_ICM2_PT2, C_ICM2_PT3: C-EUC0603; C0603
C_IDIFF_PT1, C_IDIFF_PT2, C_IDIFF_PT3: C-EUC0603; C0603
C_RCM1_PT1, C_RCM1_PT2, C_RCM1_PT3, C_RCM2_PT1, C_RCM2_PT2, C_RCM2_PT3: C-EUC0603; C0603
C_RDIFF_PT1, C_RDIFF_PT2, C_RDIFF_PT3: C-EUC0603; C0603
C_VREF_PT1, C_VREF_PT2, C_VREF_PT3: 1u; C0603
D1, D2, D5, D6: 6V; DMELF
D3, D4, D7, D8, D9, D10, D11, D12: 3V6; DMELF
Q1: 12MHz; SM49
R1, R2, R8, R30, R36, R37, R43, R44, R50, R51, R57, R58: 4k7; R0603
R3, R31, R38, R45, R52, R59: 47; R0603
R4, R5, R32, R33, R39, R40, R46, R47, R53, R54, R60, R61: 40 1%; R0805
R6, R7, R34, R35, R41, R42, R48, R49, R55, R56, R62, R63: 1k 0.1%; R0805
R10, R15: 500; R0805
R11: 3k; R0805
R12: 2k; R0805
R13: 4k7; R0805
R14: 7k5; R0805
R16, R17: 3k3; R0805
R22: 100k; R0805
R23: 1k; R0805
R24, R25: ?; R0805
RN11: 3k; EXBS8V
RN12: 300; EXBS8V
RN_A_PT1, RN_A_PT2, RN_A_PT3: 47; 0603-ARC
RN_B_PT1, RN_B_PT2, RN_B_PT3: 47; 0603-ARC
RN_DMS1, RN_DMS2, RN_DMS3, RN_DMS4, RN_DMS5, RN_DMS6: 47; 0603-ARC
R_I1_PT1, R_I1_PT2, R_I1_PT3, R_I2_PT1, R_I2_PT2, R_I2_PT3: R-EU_R0603; R0603
R_R1_PT1, R_R1_PT2, R_R1_PT3, R_R2_PT1, R_R2_PT2, R_R2_PT3: R-EU_R0603; R0603
R_REF_PT1, R_REF_PT2, R_REF_PT3: R-EU_R0603; R0603
U$1, U$2, U$3, U$4, U$5, U$6: COMMON_MODE_CHOKE
U_7805: LM78L05ACMX/NOPB; SOIC8
U_ADC_DMS1, U_ADC_DMS2, U_ADC_DMS3, U_ADC_DMS4, U_ADC_DMS5, U_ADC_DMS6: ADS1147TSSOP20; TSSOP20
U_ADC_PT1, U_ADC_PT2, U_ADC_PT3: ADS1147TSSOP20; TSSOP20
U_ADR366_3: ADR366WAUJZ; SOT23-5
U_CH340G: CH340G; SOIC16
U_LT1528: LT1528; Q5-DD
U_MAX488: MAX488CSA; SO08
U_OPTO_1, U_OPTO_2, U_OPTO_3: MOCD207MSOIC-8; SOIC127P594X363-8N
U_S70FL01GS_1, U_S70FL01GS_2: S70FL01GS; SO16
U_TRACODCDC: THN10-2411WIR; THL_20WI_SERIES

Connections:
3V3: C3.1, C5.1, C9.1, C10.1, C15.1, C19.1, C24.1, C25.1, C28.1, C29.1, C30.1, C31.1, C32.1, C33.1, C37.2, C41.+, C48.1, C55.1, C_AVDD_PT1.1, C_AVDD_PT2.1, C_AVDD_PT3.1, C_DVDD_PT1.1, C_DVDD_PT2.1, C_DVDD_PT3.1, R1.1, R2.2, R6.2, R8.1, R13.2, R30.2, R34.2, R36.1, R37.2, R41.2, R43.1, R44.2, R48.2, R51.2, R55.2, R58.2, R62.2, RN12.1, RN12.2 (1), RN12.3 (1), RN12.4 (1), RN_A_PT1.8 (2), RN_A_PT2.8 (2), RN_A_PT3.8 (2), RN_B_PT1.6 (2), RN_B_PT2.6 (2), RN_B_PT3.6 (2), U$1.P$2 (2), U$2.P$2 (2), U$3.P$2 (2), U$4.P$2 (2), U$5.P$2 (2), U$6.P$2 (2), U_ADC_DMS1.1 (DVDD), U_ADC_DMS1.14 (AVDD), U_ADC_DMS2.1 (DVDD), U_ADC_DMS2.14 (AVDD), U_ADC_DMS3.1 (DVDD), U_ADC_DMS3.14 (AVDD), U_ADC_DMS4.1 (DVDD), U_ADC_DMS4.14 (AVDD), U_ADC_DMS5.14 (AVDD), U_ADC_DMS6.14 (AVDD), U_ADC_PT1.1 (DVDD), U_ADC_PT1.14 (AVDD), U_ADC_PT2.1 (DVDD), U_ADC_PT2.14 (AVDD), U_ADC_PT3.1 (DVDD), U_ADC_PT3.14 (AVDD), U_CH340G.16 (VCC), U_LT1528.1 (OUT), U_LT1528.2 (SENSE), U_S70FL01GS_1.2 (VCC), U_S70FL01GS_2.2 (VCC); also elsewhere on the board
3V3REF: R24.2, U_ADR366_3.4 (VOUT); also elsewhere on the board
5V: C35.2, C36.2, C39.+, C40.+, C52.2, U_ADR366_3.3 (VIN), U_LT1528.4 (SHDN), U_LT1528.5 (IN), U_TRACODCDC.3 (+VOUT); also elsewhere on the board
5V-28V: C43.1, R14.2, R16.1, U_7805.1 (VOUT), U_MAX488.1 (VCC); also elsewhere on the board
28V: C34.2, C38.+, C42.2, RN11.1, RN11.2 (1), RN11.3 (1), RN11.4 (1), U_7805.8 (VIN), U_TRACODCDC.1 (+VIN); also elsewhere on the board
28VGND: C34.1, C38.-, C42.1, C43.2, C44.2, D5.A, D6.A, R11.1, R17.1, U_7805.2 (GND), U_7805.3 (GND), U_7805.6 (GND), U_7805.7 (GND), U_MAX488.4 (GND), U_OPTO_3.5 (EMT2), U_TRACODCDC.2 (-VIN); also elsewhere on the board
!CS!_DMS1: R3.2
!CS!_DMS2: R31.2
!CS!_DMS3: R38.2
!CS!_DMS4: R45.2
!CS!_DMS5: R52.2
!CS!_DMS6: R59.2
!CS!_PT1: RN_B_PT1.7 (2)
!CS!_PT2: RN_B_PT2.7 (2)
!CS!_PT3: RN_B_PT3.7 (2)
!DRDY!_DMS1: RN_DMS1.5 (2)
!DRDY!_DMS2: RN_DMS2.5 (2)
!DRDY!_DMS3: RN_DMS3.5 (2)
!DRDY!_DMS4: RN_DMS4.5 (2)
!DRDY!_DMS5: RN_DMS5.5 (2)
!DRDY!_DMS6: RN_DMS6.5 (2)
!DRDY!_PT1: RN_B_PT1.8 (2)
!DRDY!_PT2: RN_B_PT2.8 (2)
!DRDY!_PT3: RN_B_PT3.8 (2)
DAPI_N: D1.C, U_CH340G.6 (D-); also elsewhere on the board
DAPI_P: D2.C, U_CH340G.5 (D+); also elsewhere on the board
DAPI_RX: D4.C, U_CH340G.2 (TX); also elsewhere on the board
DAPI_TX: D3.C, U_CH340G.3 (RX); also elsewhere on the board
DMS11: U$2.P$1 (1); also elsewhere on the board
DMS12: U$2.P$3 (3); also elsewhere on the board
DMS13: U$2.P$5 (5); also elsewhere on the board
DMS21: U$1.P$1 (1); also elsewhere on the board
DMS22: U$1.P$3 (3); also elsewhere on the board
DMS23: U$1.P$5 (5); also elsewhere on the board
DMS31: U$3.P$1 (1); also elsewhere on the board
DMS32: U$3.P$3 (3); also elsewhere on the board
DMS33: U$3.P$5 (5); also elsewhere on the board
DMS41: U$4.P$1 (1); also elsewhere on the board
DMS42: U$4.P$3 (3); also elsewhere on the board
DMS43: U$4.P$5 (5); also elsewhere on the board
DMS51: U$5.P$1 (1); also elsewhere on the board
DMS52: U$5.P$3 (3); also elsewhere on the board
DMS53: U$5.P$5 (5); also elsewhere on the board
DMS61: U$6.P$1 (1); also elsewhere on the board
DMS62: U$6.P$3 (3); also elsewhere on the board
DMS63: U$6.P$5 (5); also elsewhere on the board
DMS_DIN: RN_DMS1.7 (2), RN_DMS2.7 (2), RN_DMS3.7 (2), RN_DMS4.7 (2), RN_DMS5.7 (2), RN_DMS6.7 (2)
DMS_DOUT: RN_DMS1.6 (2), RN_DMS2.6 (2), RN_DMS3.6 (2), RN_DMS4.6 (2), RN_DMS5.6 (2), RN_DMS6.6 (2)
DMS_SCLK: RN_DMS1.8 (2), RN_DMS2.8 (2), RN_DMS3.8 (2), RN_DMS4.8 (2), RN_DMS5.8 (2), RN_DMS6.8 (2)
EXP_IN: D5.C, U_MAX488.2 (RO), U_OPTO_3.1 (A1)
EXP_IN_N: R15.1, R17.2, U_MAX488.7 (B); also elsewhere on the board
EXP_IN_OPT: D10.C, R13.1, U_OPTO_3.8 (COL1); also elsewhere on the board
EXP_IN_P: R10.2, R16.2, U_MAX488.8 (A); also elsewhere on the board
EXP_OUT: D6.C, R14.1, U_MAX488.3 (DI), U_OPTO_3.6 (COL2)
EXP_OUT_N: U_MAX488.6 (Z); also elsewhere on the board
EXP_OUT_OPT: U_OPTO_3.3 (A2); also elsewhere on the board
EXP_OUT_P: U_MAX488.5 (Y); also elsewhere on the board
FL_1_CS1: U_S70FL01GS_1.7 (CS1); also elsewhere on the board
FL_1_CS2: U_S70FL01GS_1.6 (CS2); also elsewhere on the board
FL_1_HLD: U_S70FL01GS_1.1 (HOLD); also elsewhere on the board
FL_1_RES: U_S70FL01GS_1.3 (RESET); also elsewhere on the board
FL_1_WP: U_S70FL01GS_1.9 (WP); also elsewhere on the board
FL_2_CS1: U_S70FL01GS_2.7 (CS1); also elsewhere on the board
FL_2_CS2: U_S70FL01GS_2.6 (CS2); also elsewhere on the board
FL_2_HLD: U_S70FL01GS_2.1 (HOLD); also elsewhere on the board
FL_2_RES: U_S70FL01GS_2.3 (RESET); also elsewhere on the board
FL_2_WP: U_S70FL01GS_2.9 (WP); also elsewhere on the board
GND: C1.2, C2.2, C3.2, C4.2, C5.2, C6.1, C8.2, C9.2, C10.2, C11.2, C12.1, C14.2, C15.2, C19.2, C20.2, C21.1, C23.2, C24.2, C25.2, C26.2, C27.1, C28.2, C29.2, C30.2, C31.2, C32.2, C33.2, C35.1, C36.1, C37.1, C39.-, C40.-, C41.-, C46.2, C47.2, C48.2, C49.2, C50.1, C52.1, C53.2, C54.2, C55.2, C56.2, C57.1, C59.2, C_AVDD_PT1.2, C_AVDD_PT2.2, C_AVDD_PT3.2, C_DVDD_PT1.2, C_DVDD_PT2.2, C_DVDD_PT3.2, C_ICM1_PT1.1, C_ICM1_PT2.1, C_ICM1_PT3.1, C_ICM2_PT1.2, C_ICM2_PT2.2, C_ICM2_PT3.2, C_RCM1_PT1.1, C_RCM1_PT2.1, C_RCM1_PT3.1, C_RCM2_PT1.2, C_RCM2_PT2.2, C_RCM2_PT3.2, C_VREF_PT1.2, C_VREF_PT2.2, C_VREF_PT3.2, D1.A, D2.A, D3.A, D4.A, D7.A, D8.A, D9.A, D10.A, D11.A, D12.A, R7.2, R12.1, R23.1, R35.2, R42.2, R49.2, R56.2, R63.2, RN_B_PT1.4 (1), RN_B_PT1.5 (2), RN_B_PT2.4 (1), RN_B_PT2.5 (2), RN_B_PT3.4 (1), RN_B_PT3.5 (2), R_R2_PT1.2, R_R2_PT2.2, R_R2_PT3.2, R_REF_PT1.1, R_REF_PT2.1, R_REF_PT3.1, U$1.P$6 (6), U$2.P$6 (6), U$3.P$6 (6), U$4.P$6 (6), U$5.P$6 (6), U$6.P$6 (6), U_ADC_DMS1.2 (DGND/DSS), U_ADC_DMS1.3 (CLK), U_ADC_DMS1.8 (VREFCOM), U_ADC_DMS1.13 (AVSS), U_ADC_DMS2.2 (DGND/DSS), U_ADC_DMS2.3 (CLK), U_ADC_DMS2.8 (VREFCOM), U_ADC_DMS2.13 (AVSS), U_ADC_DMS3.2 (DGND/DSS), U_ADC_DMS3.3 (CLK), U_ADC_DMS3.8 (VREFCOM), U_ADC_DMS3.13 (AVSS), U_ADC_DMS4.2 (DGND/DSS), U_ADC_DMS4.3 (CLK), U_ADC_DMS4.8 (VREFCOM), U_ADC_DMS4.13 (AVSS), U_ADC_DMS5.2 (DGND/DSS), U_ADC_DMS5.3 (CLK), U_ADC_DMS5.8 (VREFCOM), U_ADC_DMS5.13 (AVSS), U_ADC_DMS6.2 (DGND/DSS), U_ADC_DMS6.3 (CLK), U_ADC_DMS6.8 (VREFCOM), U_ADC_DMS6.13 (AVSS), U_ADC_PT1.2 (DGND/DSS), U_ADC_PT1.3 (CLK), U_ADC_PT1.8 (VREFCOM), U_ADC_PT1.13 (AVSS), U_ADC_PT2.2 (DGND/DSS), U_ADC_PT2.3 (CLK), U_ADC_PT2.8 (VREFCOM), U_ADC_PT2.13 (AVSS), U_ADC_PT3.2 (DGND/DSS), U_ADC_PT3.3 (CLK), U_ADC_PT3.8 (VREFCOM), U_ADC_PT3.13 (AVSS), U_ADR366_3.2 (GND), U_CH340G.1 (GND), U_LT1528.3 (GND), U_LT1528.6 (GND), U_OPTO_1.5 (EMT2), U_OPTO_1.7 (EMT1), U_OPTO_2.5 (EMT2), U_OPTO_2.7 (EMT1), U_OPTO_3.7 (EMT1), U_S70FL01GS_1.10 (VSS), U_S70FL01GS_2.10 (VSS), U_TRACODCDC.5 (-VOUT); also elsewhere on the board
INTERSPU_RX: D11.C; also elsewhere on the board
INTERSPU_TX: D12.C; also elsewhere on the board
LO: U_OPTO_2.2 (C1); also elsewhere on the board
LO_OPT: D7.C, RN12.6 (2), U_OPTO_2.8 (COL1); also elsewhere on the board
unnamed: C2.1, Q1.2, U_CH340G.8 (XO)
unnamed: R2.1, U_ADC_DMS1.15 (START)
unnamed: C1.1, Q1.1, U_CH340G.7 (XI)
unnamed: C_RCM2_PT2.1, C_RDIFF_PT2.2, R_R2_PT2.1, U_ADC_PT2.6 (REFN0/GPIO1)
unnamed: C_RCM1_PT2.2, C_RDIFF_PT2.1, R_R1_PT2.1, U_ADC_PT2.5 (REFP0/GPIO0)
unnamed: C_ICM2_PT2.1, C_IDIFF_PT2.2, R_I2_PT2.1, U_ADC_PT2.11 (AIN2/IEXC/GPIO2)
unnamed: C12.2, C13.1, R32.1, U_ADC_DMS2.9 (AIN0/IEXC)
unnamed: C_VREF_PT1.1, U_ADC_PT1.7 (VREFOUT)
unnamed: C_ICM2_PT1.1, C_IDIFF_PT1.2, R_I2_PT1.1, U_ADC_PT1.11 (AIN2/IEXC/GPIO2)
unnamed: RN_DMS1.1, U_ADC_DMS1.20 (SCLK)
unnamed: C13.2, C14.1, R33.1, U_ADC_DMS2.10 (AIN1/IEXC)
unnamed: R33.2, R34.1, R35.1
unnamed: C_RCM2_PT1.1, C_RDIFF_PT1.2, R_R2_PT1.1, U_ADC_PT1.6 (REFN0/GPIO1)
unnamed: C_RCM1_PT1.2, C_RDIFF_PT1.1, R_R1_PT1.1, U_ADC_PT1.5 (REFP0/GPIO0)
unnamed: C_ICM1_PT1.2, C_IDIFF_PT1.1, R_I1_PT1.1, U_ADC_PT1.10 (AIN1/IEXC)
unnamed: RN_A_PT1.2 (1), U_ADC_PT1.20 (SCLK)
unnamed: RN_A_PT1.3 (1), U_ADC_PT1.19 (DIN)
unnamed: RN_A_PT1.4 (1), U_ADC_PT1.18 (DOUT/!DRDY)
unnamed: C_ICM1_PT2.2, C_IDIFF_PT2.1, R_I1_PT2.1, U_ADC_PT2.10 (AIN1/IEXC)
unnamed: C_VREF_PT2.1, U_ADC_PT2.7 (VREFOUT)
unnamed: RN_A_PT2.2 (1), U_ADC_PT2.20 (SCLK)
unnamed: RN_B_PT1.1, U_ADC_PT1.17 (!DRDY)
unnamed: RN_B_PT1.2 (1), U_ADC_PT1.16 (!CS)
unnamed: RN_B_PT1.3 (1), U_ADC_PT1.15 (START)
unnamed: RN_A_PT2.3 (1), U_ADC_PT2.19 (DIN)
unnamed: RN_A_PT2.4 (1), U_ADC_PT2.18 (DOUT/!DRDY)
unnamed: RN_B_PT2.1, U_ADC_PT2.17 (!DRDY)
unnamed: RN_B_PT2.2 (1), U_ADC_PT2.16 (!CS)
unnamed: RN_B_PT2.3 (1), U_ADC_PT2.15 (START)
unnamed: C_RCM2_PT3.1, C_RDIFF_PT3.2, R_R2_PT3.1, U_ADC_PT3.6 (REFN0/GPIO1)
unnamed: C_RCM1_PT3.2, C_RDIFF_PT3.1, R_R1_PT3.1, U_ADC_PT3.5 (REFP0/GPIO0)
unnamed: RN11.6 (2), U_OPTO_1.1 (A1)
unnamed: RN11.5 (2), U_OPTO_1.3 (A2)
unnamed: R12.2, U_OPTO_3.4 (C2)
unnamed: RN12.5 (2), U_OPTO_2.6 (COL2)
unnamed: RN11.8 (2), U_OPTO_2.1 (A1)
unnamed: RN11.7 (2), U_OPTO_2.3 (A2)
unnamed: R11.2, U_OPTO_3.2 (C1)
unnamed: C44.1, R10.1, R15.2
unnamed: C_ICM2_PT3.1, C_IDIFF_PT3.2, R_I2_PT3.1, U_ADC_PT3.11 (AIN2/IEXC/GPIO2)
unnamed: C_ICM1_PT3.2, C_IDIFF_PT3.1, R_I1_PT3.1, U_ADC_PT3.10 (AIN1/IEXC)
unnamed: C_VREF_PT3.1, U_ADC_PT3.7 (VREFOUT)
unnamed: RN_A_PT3.2 (1), U_ADC_PT3.20 (SCLK)
unnamed: RN_A_PT3.3 (1), U_ADC_PT3.19 (DIN)
unnamed: RN_A_PT3.4 (1), U_ADC_PT3.18 (DOUT/!DRDY)
unnamed: RN_B_PT3.1, U_ADC_PT3.17 (!DRDY)
unnamed: RN_B_PT3.2 (1), U_ADC_PT3.16 (!CS)
unnamed: RN_B_PT3.3 (1), U_ADC_PT3.15 (START)
unnamed: RN_A_PT3.1, U_ADC_PT3.4 (!RESET)
unnamed: RN_A_PT2.1, U_ADC_PT2.4 (!RESET)
unnamed: RN_A_PT1.1, U_ADC_PT1.4 (!RESET)
unnamed: C11.1, U_ADC_DMS2.7 (VREFOUT)
unnamed: R22.1, U_ADR366_3.5 (TRIM)
unnamed: R22.2, R24.1, R25.2
unnamed: R23.2, R25.1
unnamed: R32.2, U$1.P$4 (4)
unnamed: R1.2, U_ADC_DMS1.4 (!RESET)
unnamed: RN_DMS1.2 (1), U_ADC_DMS1.19 (DIN)
unnamed: RN_DMS1.3 (1), U_ADC_DMS1.18 (DOUT/!DRDY)
unnamed: RN_DMS1.4 (1), U_ADC_DMS1.17 (!DRDY)
unnamed: R3.1, U_ADC_DMS1.16 (!CS)
unnamed: R8.2, U_ADC_DMS2.4 (!RESET)
unnamed: R30.1, U_ADC_DMS2.15 (START)
unnamed: C6.2, C7.1, R4.1, U_ADC_DMS1.9 (AIN0/IEXC)
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

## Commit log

2020-03-19 initial push
    [Blade.brd, Blade.sch, messverstaerker-adc-proto.brd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]
2020-03-19 opto added
    [Blade.brd, Blade.sch]
2020-03-22 RS422 opto galv isolation added
    [Blade.brd, Blade.sch]
2020-03-23 ground vias
    [Blade.brd, Blade.sch]
2020-03-23 ads added
    [Blade.brd, Blade.sch]
2020-03-24 bom added, text cleanup
    [Blade.brd, Blade.csv, Blade.sch]
2020-03-24 finished routing Rev. 1
    [Blade.brd, Blade.sch]
2020-03-25 partslist updated
    [Blade.brd, Blade.csv]
2020-03-26 board image sw
    [Blade.brd]
2020-03-28 schematics png/pdf
    [Blade.brd, Blade.sch]
2020-03-31 Adding new images
    [Blade.brd]
2020-04-27 Werte Update
    [Blade.brd, Blade.sch]
2020-04-29 flash footprint korrigiert
    [Blade.brd, Blade.sch]
2020-04-29 led widerstand angepasst
    [Blade.brd, Blade.sch]
2020-05-01 Widerstände Wert definiert
    [Blade.brd, Blade.sch]
2020-05-03 interspu connector, ms select
    interspu connector added
    master/slave (solder)jumper added
    [Blade.brd, Blade.sch]
2020-05-03 fusion360 sync
    [Blade.brd]
2020-05-06 Renamed to SPU_Rev_xx
    [SPU_Rev_1.0.brd, SPU_Rev_1.0.sch]
2020-05-21 Revert "Renamed to SPU_Rev_xx"
    This reverts commit 304736c8d07f8b224d599abdd620e5674e37052e.
    [Blade.brd, Blade.sch]
2020-05-25 zwischenstand
    NOT FINAL
    [SPU_Rev_2.0.brd, SPU_Rev_2.0.sch]
2020-07-19 NOT final
    [SPU_Rev_2.0.brd, SPU_Rev_2.0.sch]
2020-08-01 foo
    bar
    [SPU_Rev_2.0.brd, SPU_Rev_2.0.sch]
2020-08-05 rev 2.1
    [SPU_Rev_2.0.brd, SPU_Rev_2.0.sch]
2020-08-05 renamed to 2.1
    [SPU_Rev_2.1.brd, SPU_Rev_2.1.sch]
2020-08-05 viafence STRUCT
    [SPU_Rev_2.1.brd]
2020-08-11 some routing
    [SPU_Rev_2.1.brd, SPU_Rev_2.1.sch]
2020-08-11 Pins matched to Cube
    next step, autoroute (if possible)
    [SPU_Rev_2.1.brd, SPU_Rev_2.1.sch]
2020-08-11 cleanup autoroute 1/inf
    [SPU_Rev_2.1.brd]
2020-08-11 fix autoroute 2/inf
    [SPU_Rev_2.1.brd]
2020-08-11 finished routing
    [SPU_Rev_2.1.brd]
2020-08-18 finalized silkscreen
    [SPU_Rev_2.1.brd, SPU_Rev_2.1.sch]
2020-08-24 airwire fixed (2x)
    [SPU_Rev_2.1.brd, SPU_Rev_2.1.sch]
2020-09-07 microsd added
    [SPU_Rev_2.1.brd, SPU_Rev_2.1.sch]
2020-12-20 added LWL OUT
    added LWL OUT jack
    [SPU_Rev_2.1.brd, SPU_Rev_2.1.sch]
2020-12-31 added LWL IN
    added LWL IN
    [SPU_Rev_2.1.brd, SPU_Rev_2.1.sch]
2021-01-05 connector board
    [SPU_Rev_2.1_connectors.brd, SPU_Rev_2.1_connectors.sch]
2021-01-05 Added PT100 ADC R/C values
    [SPU_Rev_2.1.brd, SPU_Rev_2.1.sch]
2021-01-08 RS422 confirmed
    RS422 driver functionality plus optocouplers tested and confirmed
    [SPU_Rev_2.1.brd, SPU_Rev_2.1.sch]
2021-01-10 HERMESS COIN
    Adding HERMESS Coin REV 1
    [HERMESS_COIN.brd, HERMESS_COIN.sch]
2021-01-11 Adding Coin bord and images, redesign started
    [COIN_QR.brd]
2021-01-11 Opto Pull-up adjusted
    [SPU_Rev_2.1.brd, SPU_Rev_2.1.sch]
2021-01-11 Update of Coin, just GIMP
    [Bestellung.xlsx]
2021-01-12 Changed Logo, just grafik works
    [Bestellung.xlsx]
2021-01-13 Minor adjustments
    adjusted zener values, added optinal trimresistors for voltage setting.
    [SPU_Rev_2.1.brd, SPU_Rev_2.1.sch]
2021-01-13 Coin QR final final version
    [redesign_qr.brd]
2021-01-13 new coin
    [redesign_qr.brd]
2021-01-16 Update Bestellung.xlsx, HERMESS - Spaß coin fehlt noch.
    [Bestellung.xlsx]
2021-02-01 Adding reverse "We are not floemess"
    [redesign_qr.brd]
2021-02-01 adding images for funny coin
    [HERMESS_COIN_FUN.brd, redesign_qr.brd]
2021-02-01 Adding FLO/HERMESS coin, just 4 fun
    [Bestellung.xlsx, HERMESS_COIN_FUN.brd]
2021-03-30 Cleanup for new design
    [Blade.brd, Blade.csv, Blade.sch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]
2021-03-31 Adds smf2 lib
    [SPU.sch]
2021-04-04 Adds STAMPs
    [SPU.sch]
2021-04-04 Almost final sch
    [SPU.brd, SPU.sch]
2021-04-09 Minor changes
    [BOM.csv, SPU.sch]
2021-04-14 Adds changes as of Grimsmann
    [BOM.csv, SPU.brd, SPU.sch]
2021-05-06 First STAMP layout
    [SPU.brd, SPU.sch]
2021-05-12 Before autoroute
    [SPU.brd, SPU.sch]
2021-05-18 Pre DRC
    [SPU.brd]
2021-05-23 Post DRC
    [SPU.brd, SPU.sch]
2021-06-01 Finishes Airwires
    [SPU.brd]
2021-06-03 Adds production files
    [BOM.csv, SPU.brd]
2021-07-01 Adds suggestions
    [SPU.brd, SPU.sch]
2021-07-05 Improves labelling
    [SPU.brd, SPU.sch]
2021-10-17 Adding FTDI FT2232HL Updating SMF2.lbr TODO: - Rename lib so a more percise name - Check schematic before production!
2021-11-12 Updates schematics
    [BOM.csv, SPU.brd, SPU.sch]
2021-11-12 Fixes LEDs
    [SPU.brd, SPU.sch]
2021-11-16 Finished Placement
    [SPU.brd, SPU.sch]
2021-11-16 After AR 97.8%
    [SPU.brd]
2021-11-18 During work commit
    [SPU.brd, SPU.sch]
2021-11-19 During work commit Reorderd RXSM interface
    [SPU.brd]
2021-11-19 Schematic: changed names from STAMP2 - STMAP6 to STAMPN_ADC_SG/TEMP Bord: Adding names for more readabilty.
    [SPU.brd, SPU.sch]
2021-11-19 End of day commit Schematic: Removed renaming error Bord: Placed and routed Stamp 2
    [SPU.brd, SPU.sch]
2021-11-20 Ignoring local KiCAD folder
2021-11-20 Mid day commit Moved Stamp 3 -5, continue with stamp 6, currently disabled airwires: GND, 3v3 Added names to top and bottom rerouted 4Mhz clk
    [SPU.brd]
2021-11-20 Routed all signals and voltages End of day commit TODO: GND connection Adding WE - XTAL Eagle lib Update schematic: Adding XTAL Bord: routed
    NOTE: DRC not ok
    [SPU.brd, SPU.sch]
2021-11-21 Adding vias 54 airwires
    [SPU.brd]
2021-11-21 Routing completed DRC: Run successfully Adding via fences Resolved grounding problems NOTE: USB Port position changed NOTE: Run ratsnest before generating gerber files
    [SPU.brd]
2021-11-21 Routing completed DRC: Run successfully Adding via fences Resolved grounding problems NOTE: USB Port position changed NOTE: Run ratsnest before generating gerber files
    NOTE: Second commit, same topic due to previous staged changes.
    [SPU.brd]
2021-11-21 Minor changes
    - XTAL from AUX to MAIN
    - Removes authors
    - Adds interface measurements
    - Fixes Airwire / Wirestub
    [SPU.brd, SPU.sch]
2021-11-22 Minor changes Minimal increased grounding plate on top layer Removed wirestubs DRC run: successful
    [SPU.brd]
2021-11-26 Adds orders
    [BOM.csv]

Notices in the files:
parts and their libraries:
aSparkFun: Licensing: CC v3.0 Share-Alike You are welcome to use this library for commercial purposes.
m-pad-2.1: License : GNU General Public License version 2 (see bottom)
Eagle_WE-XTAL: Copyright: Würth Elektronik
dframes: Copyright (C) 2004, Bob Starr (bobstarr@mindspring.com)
